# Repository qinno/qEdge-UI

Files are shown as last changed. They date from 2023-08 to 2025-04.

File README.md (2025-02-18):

# qEdge-UI

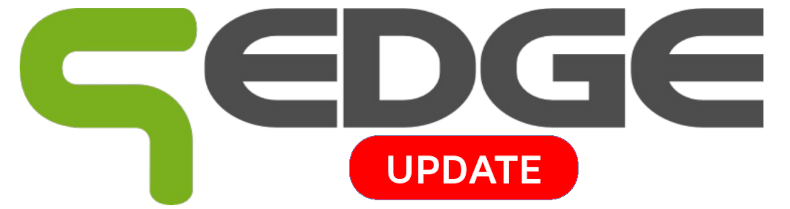
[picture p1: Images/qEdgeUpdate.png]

# Update
qEdge-UI supports now PICO2-W plattform (RP2350) with minimum changes as qEdge-UI++. Compilation now works in the Arduino 2.x.x IDE. LittleFS upload does not work in the moment, copy the files in /data to the SD-card, system copies it automagically to LittleFS on the first start. 

# About

This project is an example of use of what can be achieved with free/libre and open source software and free/libre and open source tools in a professional proceeding. 
In contrast to the generally accepted approach of commercial companies, the development results of this project (hardware and mechanical design, as well as software source code) are also available under an open source licence.

Based on the Raspberry Pi Pico (2), we have created a design that can be used as a starting point for further development. In order to keep things as simple as possible we use the Arduino platform.

Key hardware features of **qEdge-UI (qEdge-UI++)**:

- Raspberry Pi Pico RP2040 (2350)
- Dual-Core ARM Cortex M0+ CPU @133 MHz (ARM Cortex M33 @150 MHz or RISC-V)
- 264KB SRAM and 2MB Flash (520 KB / 4MB)
- WiFi + Bluetooth (Pico-W/Pico2-W)
- USB interface and power supply
- additional 12/24 VDC supply
- 3,2" TFT-Display 320x240 with resistive touch
- 4x1 keypad
- expansion connector for UART, I²C, GPIO, ADC
- RS-485 Interface
- Micro-SD-card slot
- LoRa module with stable SMA connector
- RTC with ultracap buffer
- Buzzer
- RGB-LEDs for signalling
- Raspberry Pi 3b/4b connectable (optional, not tested)

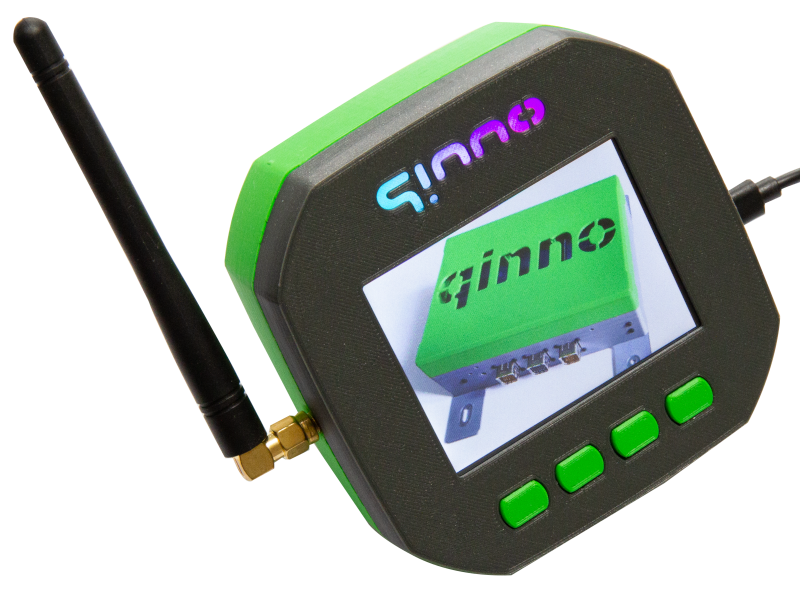
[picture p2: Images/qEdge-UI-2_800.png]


# Getting Started

### Electronics

To get started you will need the qEdge-UI electronic boards (main and display adapter). [We provide the full KiCad project here.](Electronics)

### Software

To get started with the software development you need a PC with:

* preinstalled Windows 7 or newer (64Bit), Linux (32/64Bit) or MacOS 10.10 newer
* An Arduino IDE 1.8.x including USB Driver support
* Addional you can use our qEdge-UI examples and libraries as a starting point for your own software development or you can download the precompiled UFS binaries of our qEdge-UI examples. [Here](Software) you can find the sources and installation guideline.

### Mechanics

To create the nice looking electronic box above you need a 3D printer [and the mechanics](Mechanics)

## qEdge-UI Hardware Test App functionality

The main objective of the qEdge-UI HwTestApp software is to check the functionality of the hardware.

* Touch - check precision of touch screen
* Slideshow - show PNG files on SD-Card (micro)
* UART - Test UART1 (RX/TX)
* RS-485 - Test UART2 connected to RS-485 driver (RX/TX)
* Micro-SD-card - check SD-card presence and list files on SD-card
* LittleFS - list, copy, rename and delete files in the filesystem
* LoRa - send/receive LoRa messages
* WiFi - scan and log in a network for receiving NTP time information
* GAME - space shooters clone to show performance
* Info - show system infos
* Keyboard - keyboard emulation
* Settings - set RGB preferences and backlight, test Buzzer

# Roadmap

See the [open issues](https://github.com/qinno/qEdge-UI/issues) for a list of proposed features (and known issues).

# Contributing

First of all, thank you for taking the time to contribute! Contributions are what make the open source community such an amazing place to learn, inspire and create. Every contribution you make benefits everyone else and is **greatly appreciated**.

Please try to create bug reports that are:

- _Reproducible._ Include steps to reproduce the problem.
- _Specific._ Include as much detail as possible: which version, what environment, etc.
- _Unique._ Do not duplicate existing open issues.
- _Scoped to a Single Bug._ One bug per report.

# Use and Regulations

Please note that this is an engineering example and is not certified to European regulations such as CE and RED, so use it at your own risk. If you find this platform helpful, we can assist you in creating a production-ready and certified product.

# Known limitations

This project is at the moment not used in a commercial open source product, but can be used as a starting point for that purpose. Please fell free to contact us for more information.

# Support

Reach out to the maintainer at one of the following places:

- By email which is located at [qinno GmbH · GitHub](https://github.com/qinno)

# Licenses

This project is licensed under the following open source licenses:
* Electronics are under [**CERN-OHL-S V2**](https://ohwr.org/cern_ohl_s_v2.txt)
* Mechanics and Design are under [**CC-BY-NC-4.0**](https://creativecommons.org/licenses/by-nc/4.0/legalcode)
* Software Examples are under [**GPLv3**](https://www.gnu.org/licenses/gpl-3.0.en.html)
   
See corresponding Readme.md files in the folders Electronics, Mechanics and Software for more detailed information.

[Raspberry Pi is a trademark of Raspberry Pi Ltd](http://www.raspberrypi.com/)

# Acknowledgements

Thanks to our partners supporting this project:

* [Our Customer Varmeco for the generous donation of material](https://varmeco.de)

* Axel Isele for the mechanics design

* [Würth Elektronik for free samples for the very first prototypes](https://www.we-online.com/de)

* All qinno-colleagues for their commitment even in their spare time

Thanks also for these awesome resources that were used during the development of the **qEdge-UI**:

* [The KiCAD team for their great CAE tool](https://www.kicad.org/)
* [Earle F. Philhower, III for his Arduino library for the RP2040](https://github.com/earlephilhower/arduino-pico)
* [Bodmer for his versatile TFT-Library](https://github.com/Bodmer/TFT_eSPI)
* [Larry Bank for his PNG extension](https://github.com/bitbank2/PNGdec)
* [The Adafruit Industries Team for their RGB-LED library](https://github.com/adafruit/Adafruit_NeoPixel)
* [The Arduino team for their easy to use (now legacy) IDE](https://www.arduino.cc/en/software)
* [Sandeep Mistry for his handy LoRa library](https://github.com/sandeepmistry/arduino-LoRa)

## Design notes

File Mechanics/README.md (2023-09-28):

# qEdge-UI mechanics

In this directory you will find the mechanic data to 3D-Print a housing and keys for qEdge-UI. You will find an exploded view under [Assembling](QE.ASM-102_01.pdf).

There are 4 different parts that need to be printed.

# Top housing

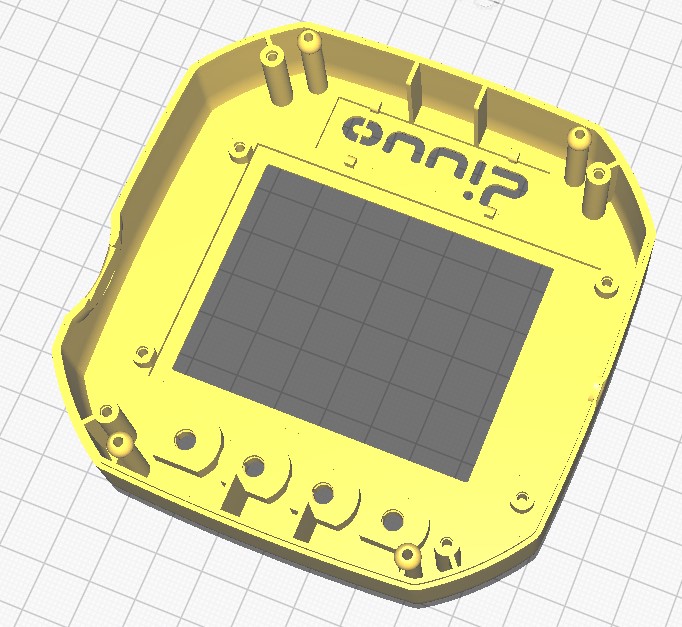
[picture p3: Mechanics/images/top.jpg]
Top


# Bottom Housing

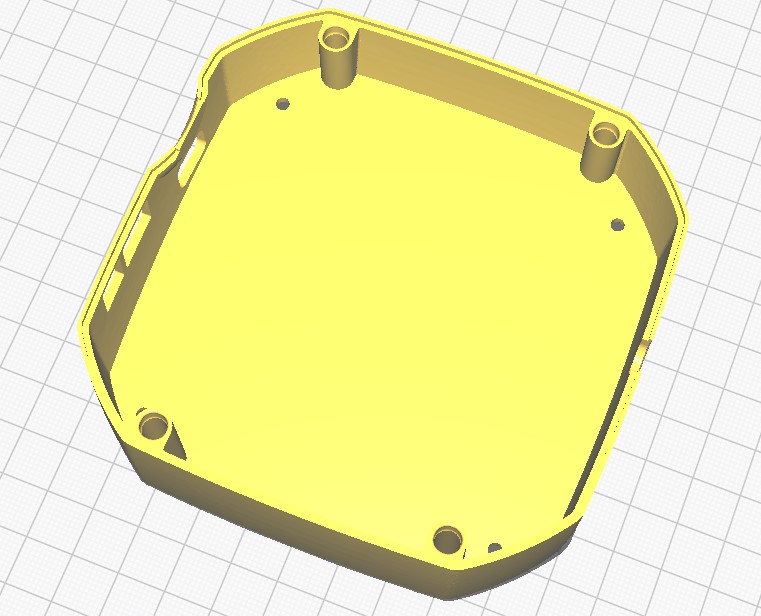
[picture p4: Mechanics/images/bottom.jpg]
Bottom


# Buttons (4x needed)

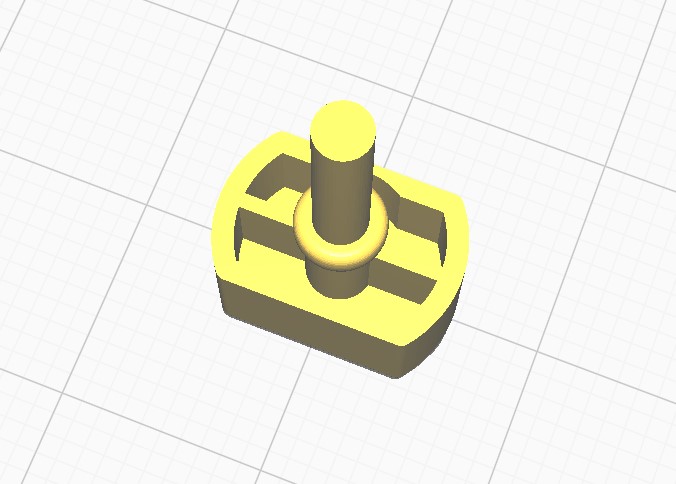
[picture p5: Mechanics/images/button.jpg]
Buttons


# LED Window

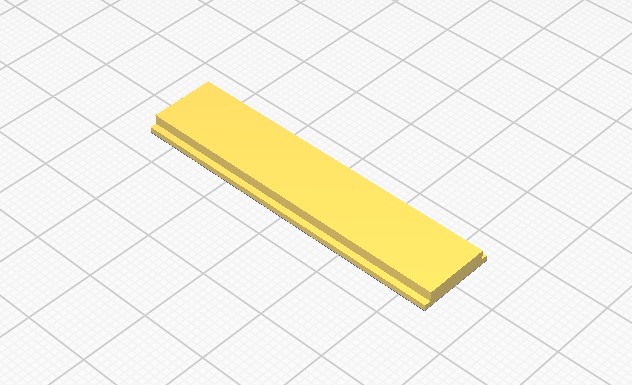
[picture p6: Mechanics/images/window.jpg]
Window


You can choose any filamant type and color. However, the GCODE is designed for PLA filament. Use something translucent for the window.

# Tips for printing

Notes on the printability of the qEdge housing, you will find the data

in [STL](./stl) for free printing in all slicers
in [3MF](./3mf) with our presets for easy adjustments
in [GCODE](./gcode) for use with a Prusa MK3S+

Please check the compatibility of the data with your printer. We cannot accept any liability for damage. The files are created with Prusa-SLICER 2.6.0.

## Bottom Housing

- The bottom should be placed flat on the print bed.
- Organic support structures / treesupports are recommended for the fillets.

## Top Housing

- The Top Housing should be placed with the top side facing the print bed. 
  
  - The Button holes also require support structures.
  
  - We do not recommend the use of treesupports here, as they are difficult to remove.  Easy to remove here was the snug option in Prusaslicer.
  
  - Before printing the upper part, we recommend printing our Support-Test STL files.  You can check the type of support structures you have and the position of the buttons without having to print the entire housing.

## Buttons

For printing, it is recommended to print at least 4 buttons at the same time to ensure sufficient cooling of the printed parts.

# License

This work is licensed under the Creative Commons Attribution-NonCommercial 4.0 International License. To view a copy of this license, visit http://creativecommons.org/licenses/by-nc/4.0/ or send a letter to Creative Commons, PO Box 1866, Mountain View, CA 94042, USA.

## Additional Printig Files (tests pending)

Since there is already print data for a Prusa printer, I wanted to extend the data for the BambuLab printer I use. Here are only [3MF](./3mf) data available, because BambuLab devices do not need the manual intermediate step to .gcode and can print directly from this file.

Important: 
1. These data are intended in the Bambu Studio Slicer or the Orca Slicer. To my knowledge, other software does not support the multi-plate layouts.

2. Bed 04 is preconfigured for a test of the support structures, the two cutouts use different types of 'normal' supports to test their removal after printing.

#### P1-X1
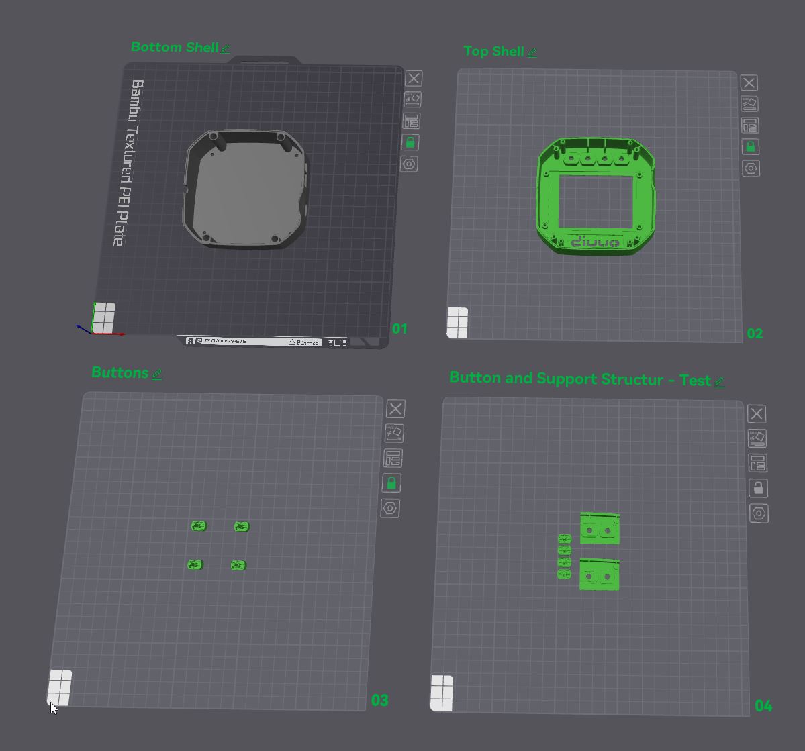
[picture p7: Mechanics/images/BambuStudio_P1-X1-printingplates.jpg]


#### A1
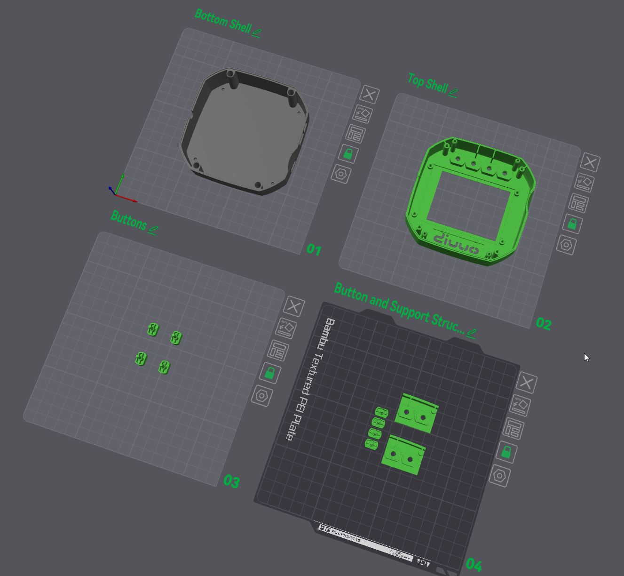
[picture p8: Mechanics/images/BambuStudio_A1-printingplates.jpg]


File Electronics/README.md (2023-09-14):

# qEdge-UI electronics

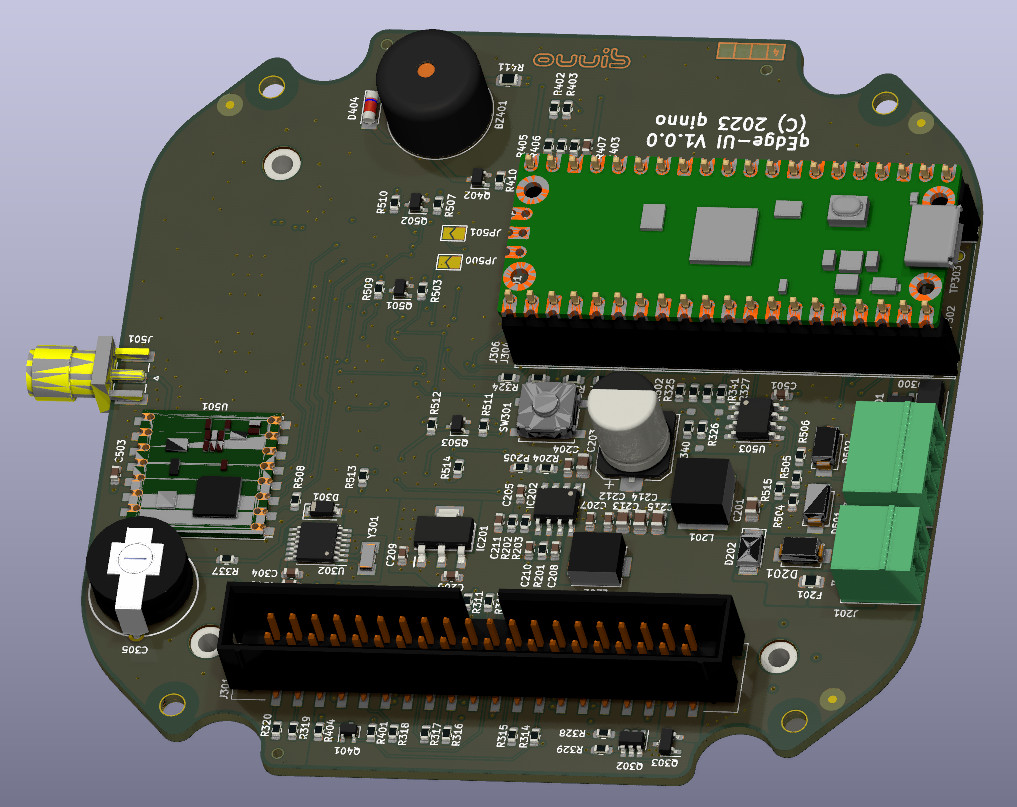
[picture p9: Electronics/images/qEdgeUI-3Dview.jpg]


In this directory you will find the complete electronic design in KiCAD.

### The main electronics

[in the directory qedge-UI](qEdge-UI)

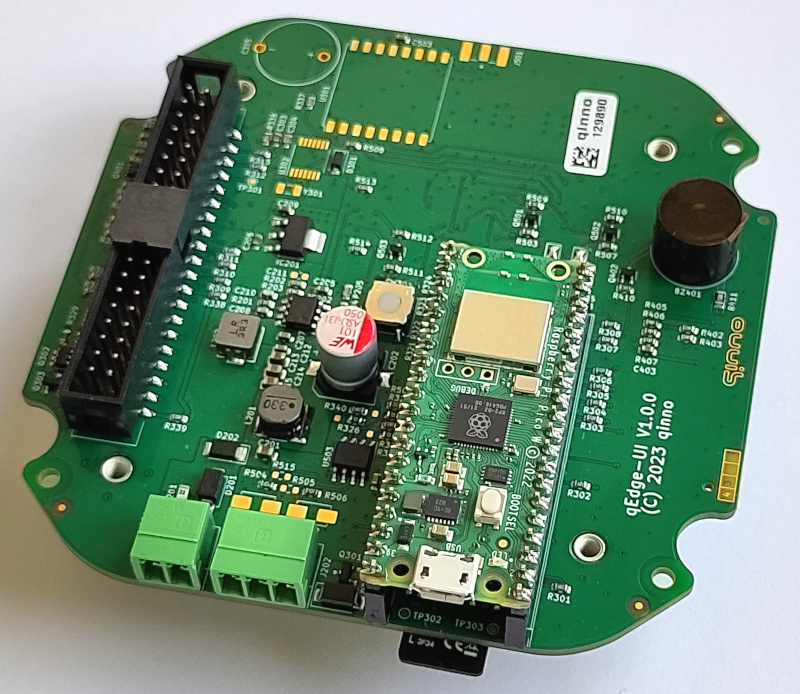
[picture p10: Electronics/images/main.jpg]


### The display adapter board

 [in the directory qEdge-LCD-Adapter](qEdge-LCD-Adapter)

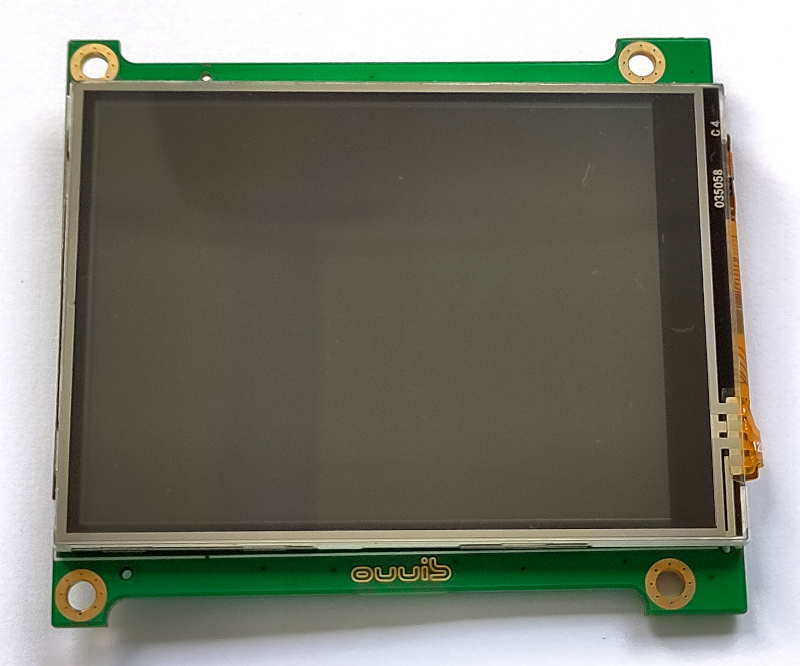
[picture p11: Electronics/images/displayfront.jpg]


You need to glue the display to the adapter board with double-sided adhesive tape and connect it to the ZIF-connector.

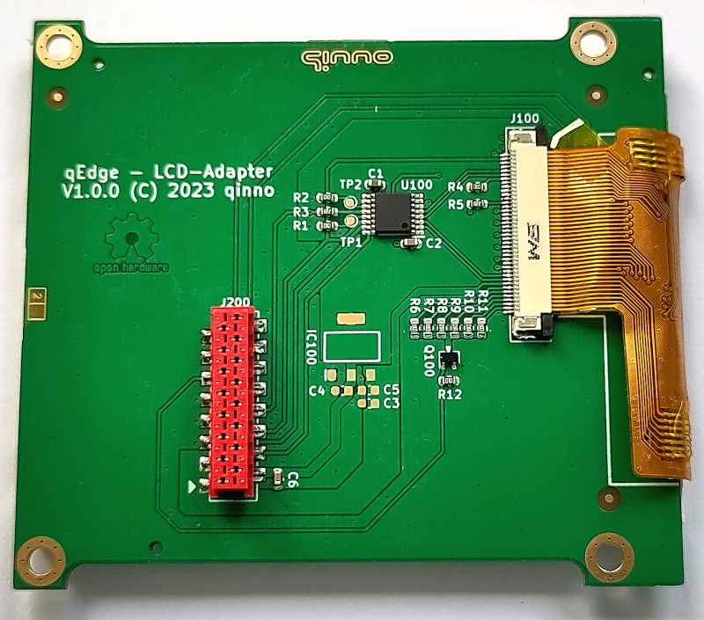
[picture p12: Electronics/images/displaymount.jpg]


For use with RaspBerry Pi Pico or Pico-W you need to close the Jumpers JP500 and JP501. After you have assembled both boards, you need to connect them with a ribbon cable.

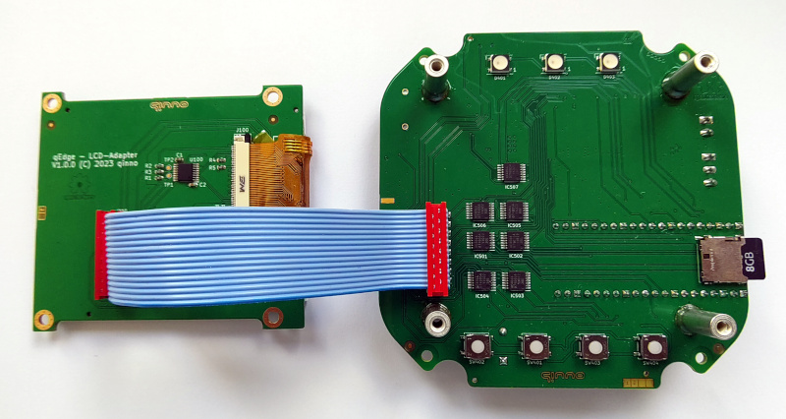
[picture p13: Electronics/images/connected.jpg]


Now screw the LCD display on top of the main board.

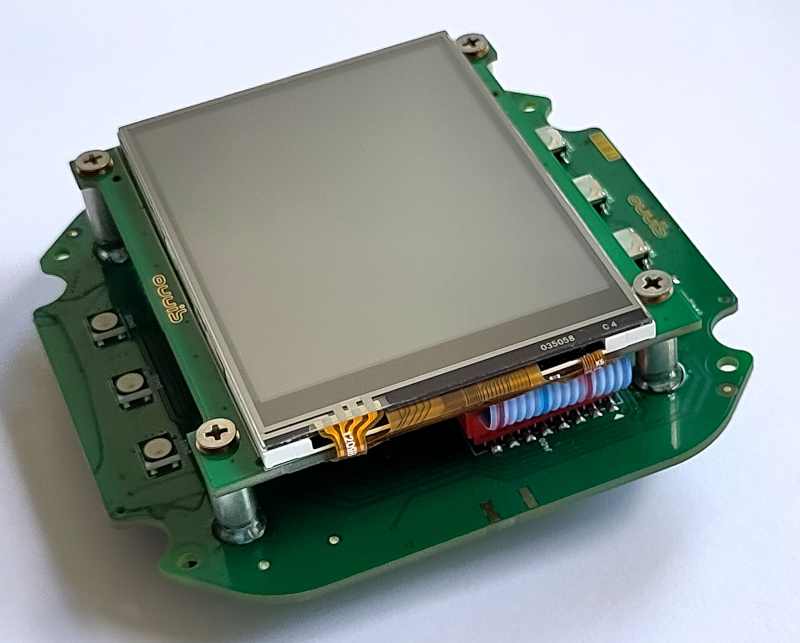
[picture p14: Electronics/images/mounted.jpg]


You can supply the unit via Micro-USB (5V) and/or via the Phoenix connectors with 12V/24V (mating connector Phoenix 1952267).

The RS-485 connector needs Phoenix mating connector 1952270 to fit.

Fingers crossed ...

# License

(C) 2023 qinno - this work is licensed under CERN-OHL-S
see https://ohwr.org/cern_ohl_s_v2.pdf for more information

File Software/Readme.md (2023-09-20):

# qEdge-UI software

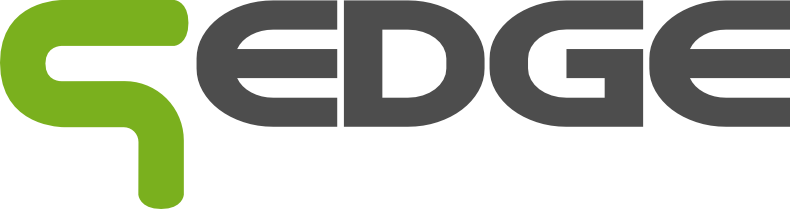
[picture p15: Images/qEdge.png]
qEdge-UI Logo

---

# Getting Started

To get started with the software development you need a PC with:

## SW-Environment Prerequisites

### OS
* Windows 7 or newer (64Bit) or
* Linux (32/64Bit) or 
* MacOS 10.10 or newer

### IDE
* An Arduino IDE 1.8.x including USB Driver support (tested with 1.8.19 - 541MB) [download here](https://www.arduino.cc/en/software). Arduino IDE 2.x is not recommended, because it has no support for Littlefs (extension), Compilation with IDE 2.x should work)

### Board package
* The Raspberry Pi Pico / RP2040 Board package by Earle F. Philhower, III. Please follow the [installation guide](https://github.com/earlephilhower/arduino-pico#installation) on Github from Earle F. Philhower, III in the arduino-pico repository. Only the installtion steps under the section "Installation" are needed.
  
### Libraries
Install the following libraries, from the Arduino IDE, by selecting the "Sketch" menu and then selecting "Include Library" and then clicking on "Manage Libraries":

* TFT_eSPI (by Bodmer - version 2.5.0)
* TFT_eWidget (by Bodmer - version 0.0.5)
* PNGdec (by Larry Bank - version 1.0.1)
* Adafruit_NeoPixel (by Adafruit - version 1.11.0)
* LoRa (by Sandeep Mistry - version 0.8.0)

#### Configure LoRA libary
* Open with an editor the file LoRa.h in Arduino/libraries/LoRa/src/
* Change in Line 23 from:

```
#define LORA_DEFAULT_SPI           SPI
```

to:

```
#define LORA_DEFAULT_SPI           SPI1
```

## Installing qEdge-UI HwTestApp

### Clone the qEdge-UI repository locally into the Arduino sources folder
* Located in the default installation path for Windows:
```
cd C:\Users\{username}\Documents\Arduino
```
  
* Located in the default installation path for Linux:
```  
cd /home/{username}/Arduino
```

* clone the repo
```
git clone https://github.com/qinno/qEdge-UI
```

### Copy & Configure the qEdge-UI HwTestApp

* Copy the file **User_Setup.h** of the repository folder Software\libaries\TFT_eSPI\ to overwrite the file with the same name in:
  
  Windows: `C:\Users\{username}\Documents\Arduino\libraries\TFT_eSPI`
  
  Linux: `/home/{username}/Arduino\libraries\TFT_eSPI`

### Download & Integrate LittleFS plugin

* Download from Github the latest ZIP archive of the LittleFS plugin (e.g. PicoLittleFS-0.2.0.zip) [Release folder of the repository of arduino-pico-littlefs-plugin from Earle F. Philhower, III](https://github.com/earlephilhower/arduino-pico-littlefs-plugin/releases). 

* Create a folder tools if it not already exists:
  
  Windows: `C:\Users\{username}\Documents\Arduino\tools`
  
  Linux: `/home/{username}/Arduino/tools`

* Unzip the LittleFS plugin archiv into the folder tools 

* Close the Ardunio IDE

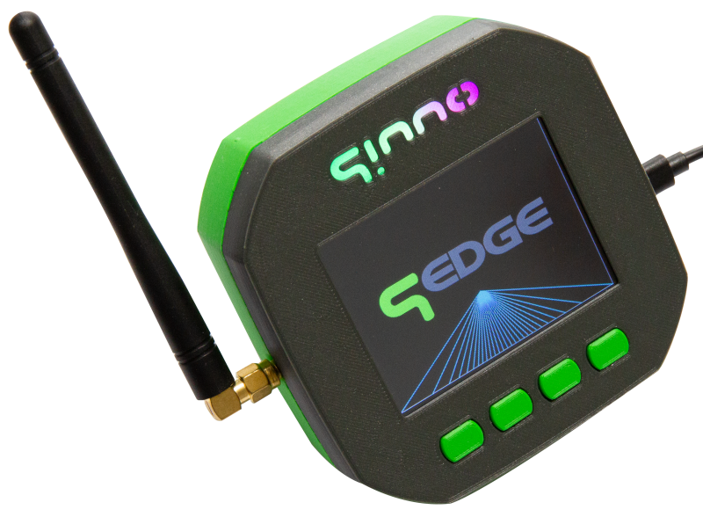
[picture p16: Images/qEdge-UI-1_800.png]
qEdge-UI with HwTestApp


## Running HwTestApp on qEdge-UI

### Initial setup Arduino IDE

* Start the Arduino IDE and select: Tools -> Board ->Raspberry Pi RP2040 Boards(3.3.0) -> **Raspberry Pi Pico W**
* Set LittleFS size by Tools -> Flash Size -> **2MB (Sketch: 1536KB, FS: 512KB**
* Connect your qEdgeUI with an USB cable 
* Select the corresponding COM Port X for the USB communication by Tools -> Port -> COM X (Raspberry Pi Pico W)

### Loading HwTestApp sketch into the IDE and compile

* In the Arduino IDE load the sketch **HwTestApp** by File -> Open -> and selecting in the qEdgeUI-demo folder the arduino file qEdgeUI-demo.ino
* Compile the sketch by selecting: Sketch -> Compile

### Upload sketch & LittleFS files to target

* Upload the sketch by selecting: Sketch -> Upload 
* Upload LittleFS files by selecting: Tools -> Pico LittleFS Data Upload (located in HwTestApp/data)

### Calibration of the qEdge-UI

The first time when the qEdge-UI unit is used after upload, it starts with a touch calibration screen. Please follow the instructions on the touchscreen. After calibration press the save button on the touchscreen and wait up to 5 seconds (if micro sd memory card is not accessible).

If you wish to re-calibrate, power down the system (unplug the USB cable) and press any front panel key on the qEdgeUI for up to 5 seconds while power is applied.

## Behind the scenes

PNG files on Micro-SD-card or LittleFS needs to be 320x240 (4:3) to fill the whole screen. Use ImageMagick to convert existing files.

# Roadmap

See the [open issues](https://github.com/dec0dOS/amazing-github-template/issues) for a list of proposed features (and known issues).

# Contributing

First of all, thank you for taking the time to contribute! Contributions are what make the open source community such an amazing place to learn, inspire and create. Every contribution you make benefits everyone else and is **greatly appreciated**.

Please try to create bug reports that are:

- _Reproducible._ Include steps to reproduce the problem.
- _Specific._ Include as much detail as possible: which version, what environment, etc.
- _Unique._ Do not duplicate existing opened issues.
- _Scoped to a Single Bug._ One bug per report.

# Known limitations

* Main menu starts slowly if compiled with SD option and no Micro-SD-card inserted

* RTC not yet supported in software

# Support

Reach out to the maintainer at one of the following places:

- By email which is located at [qinno GmbH · GitHub](https://github.com/qinno)

# License
The files in these folders are licensed under the following open source licenses:
* [examples/](examples/) -> [**GPLv3**](https://www.gnu.org/licenses/gpl-3.0.en.html)
* PNG Images in folder data and SDcontent [examples/HwTestApp/](examples/HwTestApp/) -> [**CC-BY-NC-4.0**](https://creativecommons.org/licenses/by-nc/4.0/legalcode)
* [libraries/TFT_eSPI](libraries/TFT_eSPI) -> [**MIT, BSD, FreeBSD**](libraries/TFT_eSPI/license.txt)

For detailed information please have a look at the licence files in the corresponding folders and file header in each corresponding file.

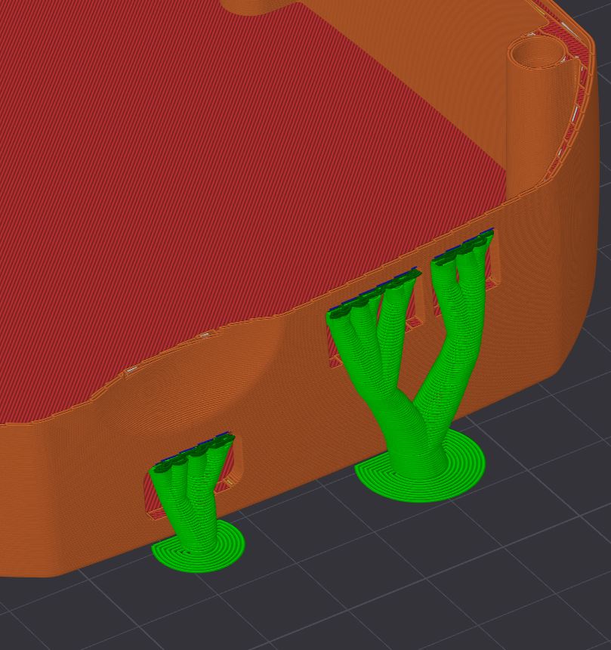
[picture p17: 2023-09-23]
Mechanics/images/bottom_support example.jpg

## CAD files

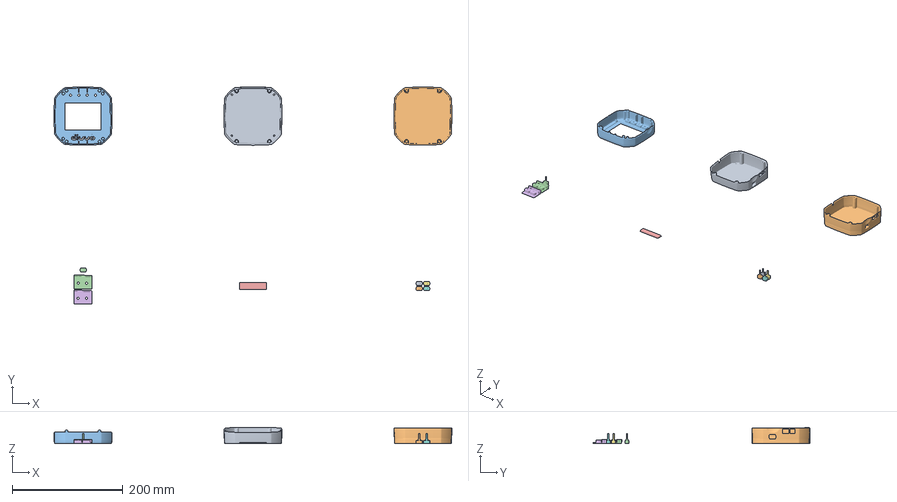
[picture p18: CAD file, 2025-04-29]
Mechanics/3mf/qEdge.104 Babu Studio 2.0+.3mf
719.4 x 392.6 x 29.6 mm
qEdge-bottom.104.stl
qEdge-bottom.104_flat.stl
qEdge-top.104.stl
Support-Test-button.104.stl
qEdge-window.104.stl
Support-Test-top-104.stl
qEdge-button.104.stl.stl x 4

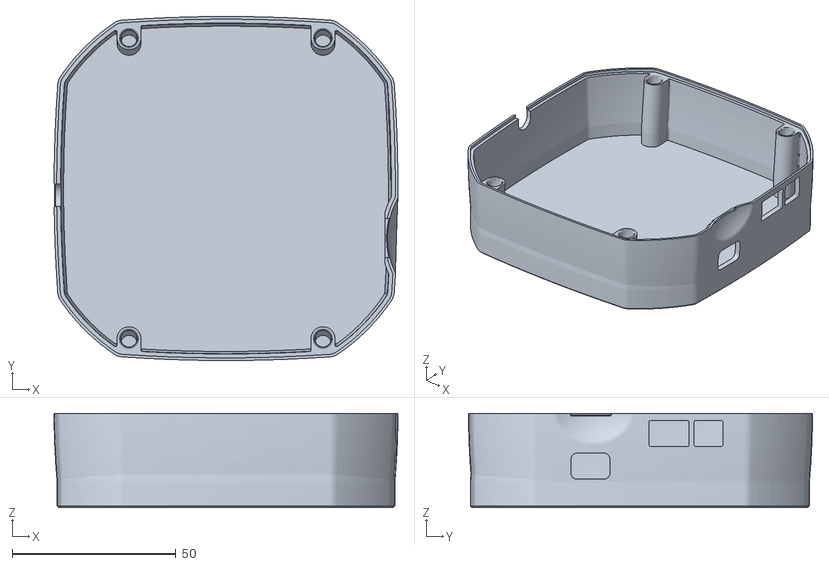
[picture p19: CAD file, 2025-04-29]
Mechanics/stl/104/qEdge-bottom.104_flat.stl
105.0 x 105.0 x 28.7

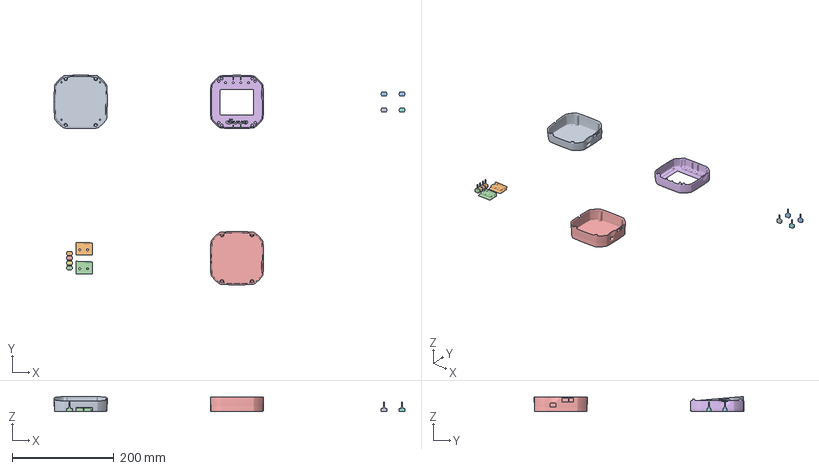
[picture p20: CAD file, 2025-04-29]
Mechanics/3mf/qEdge.104_BambuStudio-Slicer_P1-X1_3 plate project file.3mf
690.0 x 412.4 x 29.6 mm
qEdge-bottom.104.stl
Support-Test-top-104.stl x 2
qEdge-button.104.stl.stl x 8
qEdge-top.104.stl
qEdge-bottom.104_flat.stl

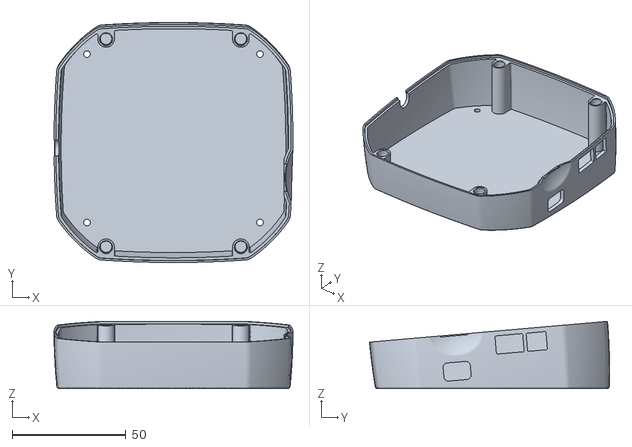
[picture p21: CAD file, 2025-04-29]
Mechanics/stl/104/qEdge-bottom.104.stl
105.0 x 105.5 x 29.6

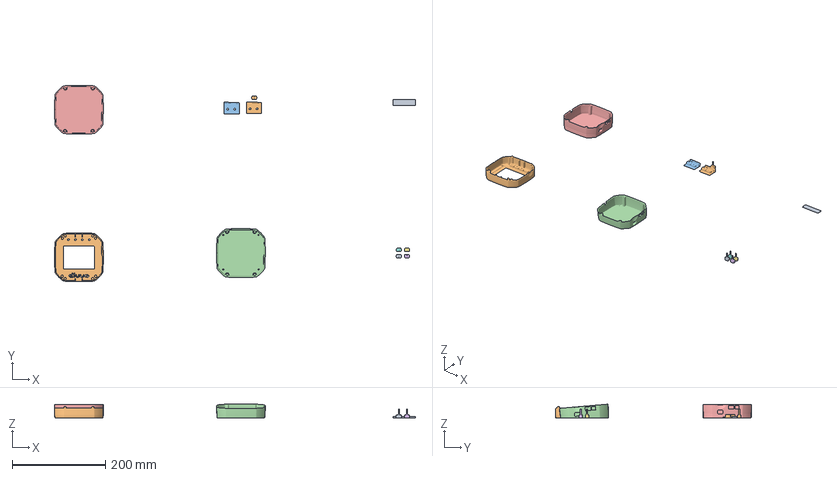
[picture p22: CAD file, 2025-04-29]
Mechanics/3mf/qEdge.104_Prusa-Slicer_plate project file.3mf
775.4 x 422.0 x 29.6 mm
qEdge-window.104.stl
Support-Test-button.104.stl
Support-Test-top-104.stl
qEdge-bottom.104.stl
qEdge-bottom.104_flat.stl
qEdge-button.104.stl.stl
qEdge-top.104.stl

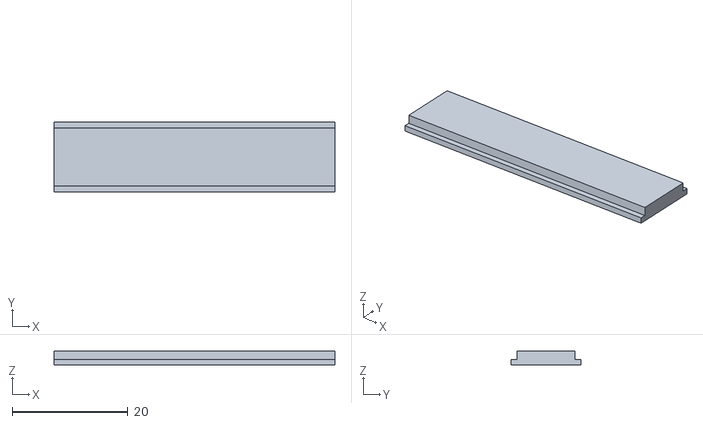
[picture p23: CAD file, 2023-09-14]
Mechanics/stl/104/qEdge-window.104.stl
48.6 x 12.1 x 2.50

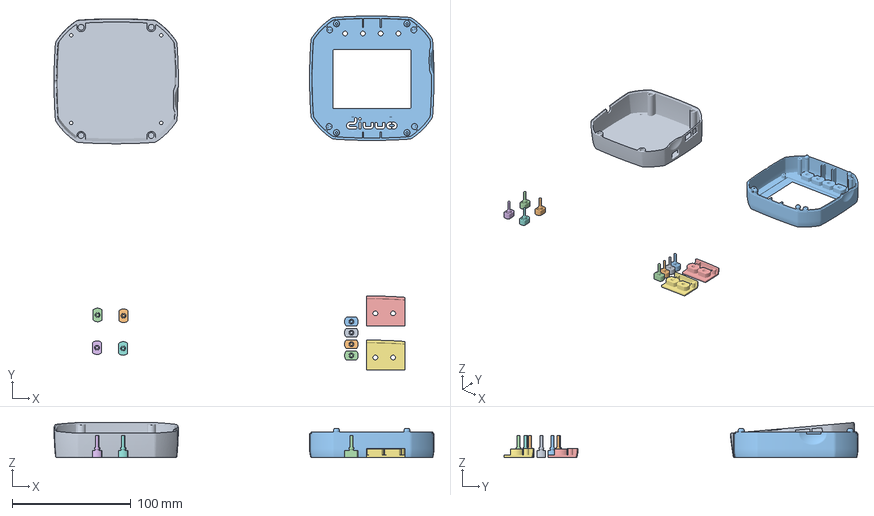
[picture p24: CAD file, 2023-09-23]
Mechanics/3mf/qEdge.104_BambuStudio-Slicer_A1_4 plates project.3mf
320.7 x 298.7 x 29.6 mm
qEdge-bottom.104.stl
qEdge-button.104.stl.stl x 8
qEdge-top.104.stl
Support-Test-top-104.stl x 2

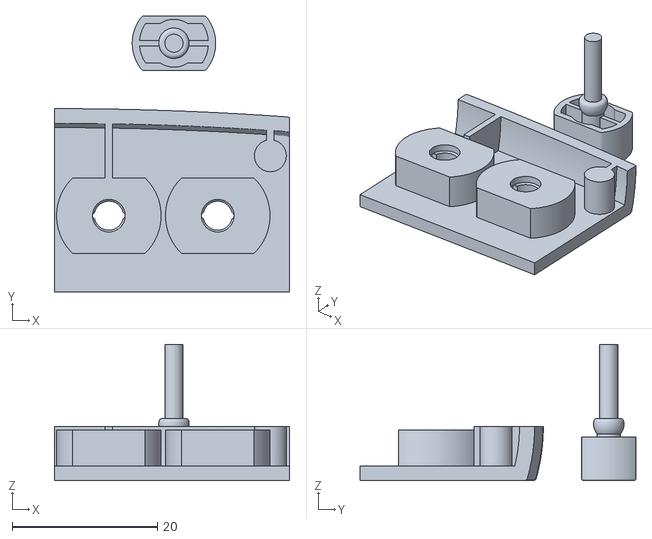
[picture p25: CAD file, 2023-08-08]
Mechanics/stl/104/Support-Test-button.104.stl
32.4 x 38.0 x 18.8

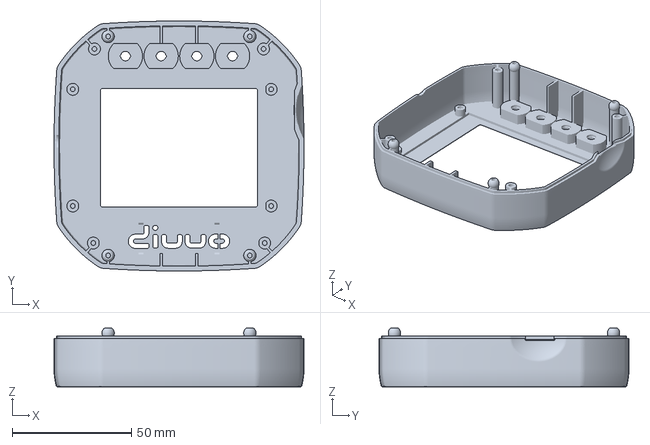
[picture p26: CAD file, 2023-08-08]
Mechanics/3mf/TOP_QE.PT-00_103+_Grau-2.3mf
105.0 x 105.0 x 24.6 mm

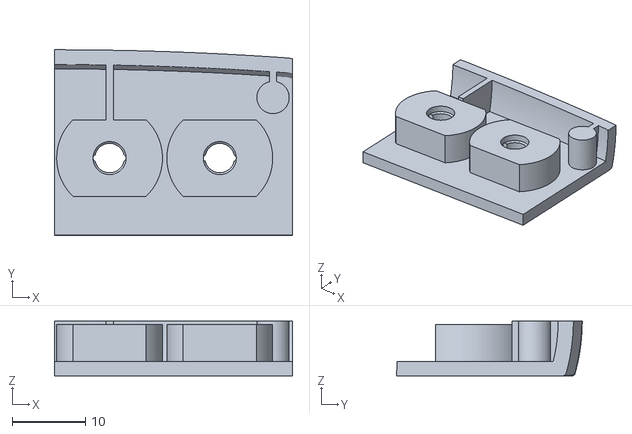
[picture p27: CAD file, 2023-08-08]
Mechanics/stl/104/Support-Test-top-104.stl
32.4 x 25.3 x 7.47

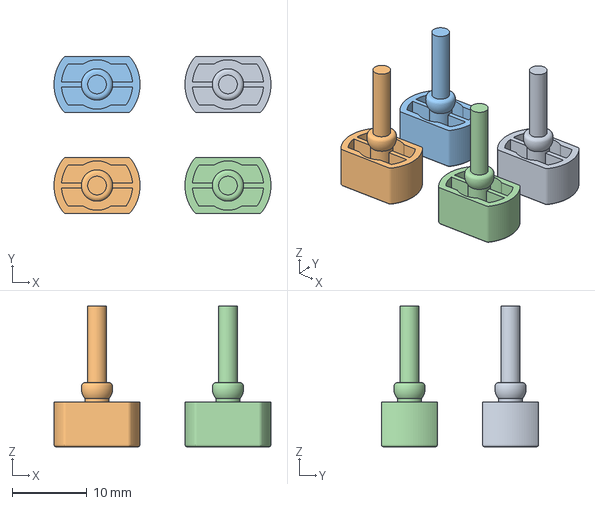
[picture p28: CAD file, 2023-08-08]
Mechanics/3mf/4xBUTTON_QE.PT-03_102_003_1mm.3mf
29.0 x 21.0 x 18.8 mm
Edit LZI_04-07-23_002_1mm x 4

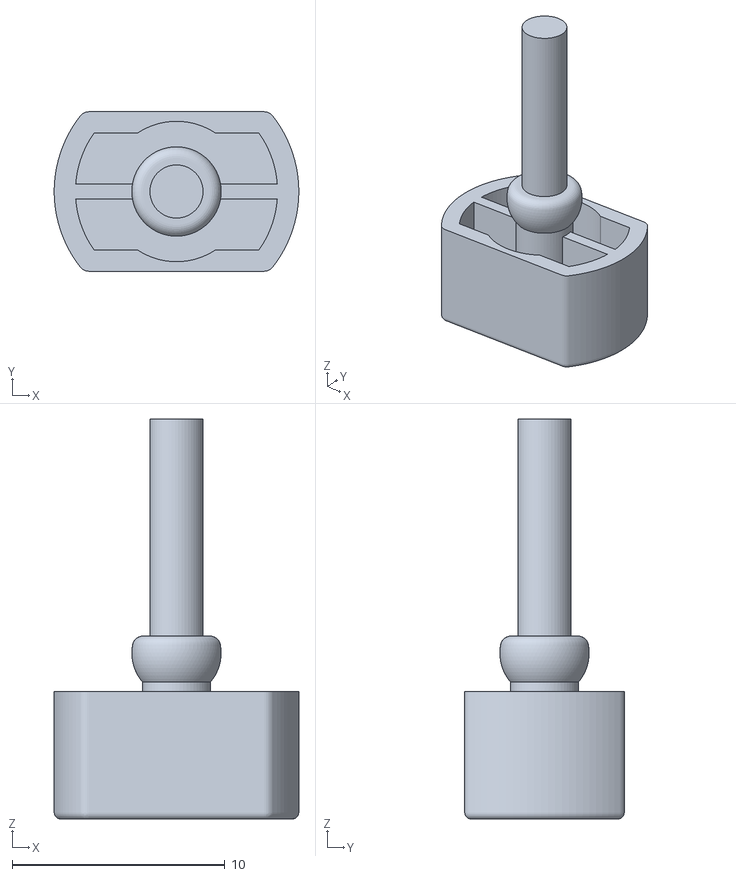
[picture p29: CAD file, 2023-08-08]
Mechanics/stl/104/qEdge-button.104.stl.stl
11.5 x 7.50 x 18.8

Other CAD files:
Mechanics/stl/104/qEdge-top.104.stl
Mechanics/3mf/BOTTOM-QE.PT-02_101.3mf

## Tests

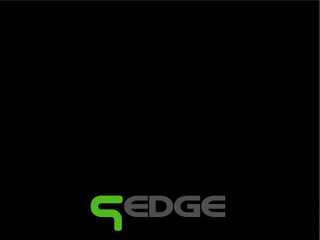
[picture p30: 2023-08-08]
Software/examples/HwTestApp/SDcontent/idle.png

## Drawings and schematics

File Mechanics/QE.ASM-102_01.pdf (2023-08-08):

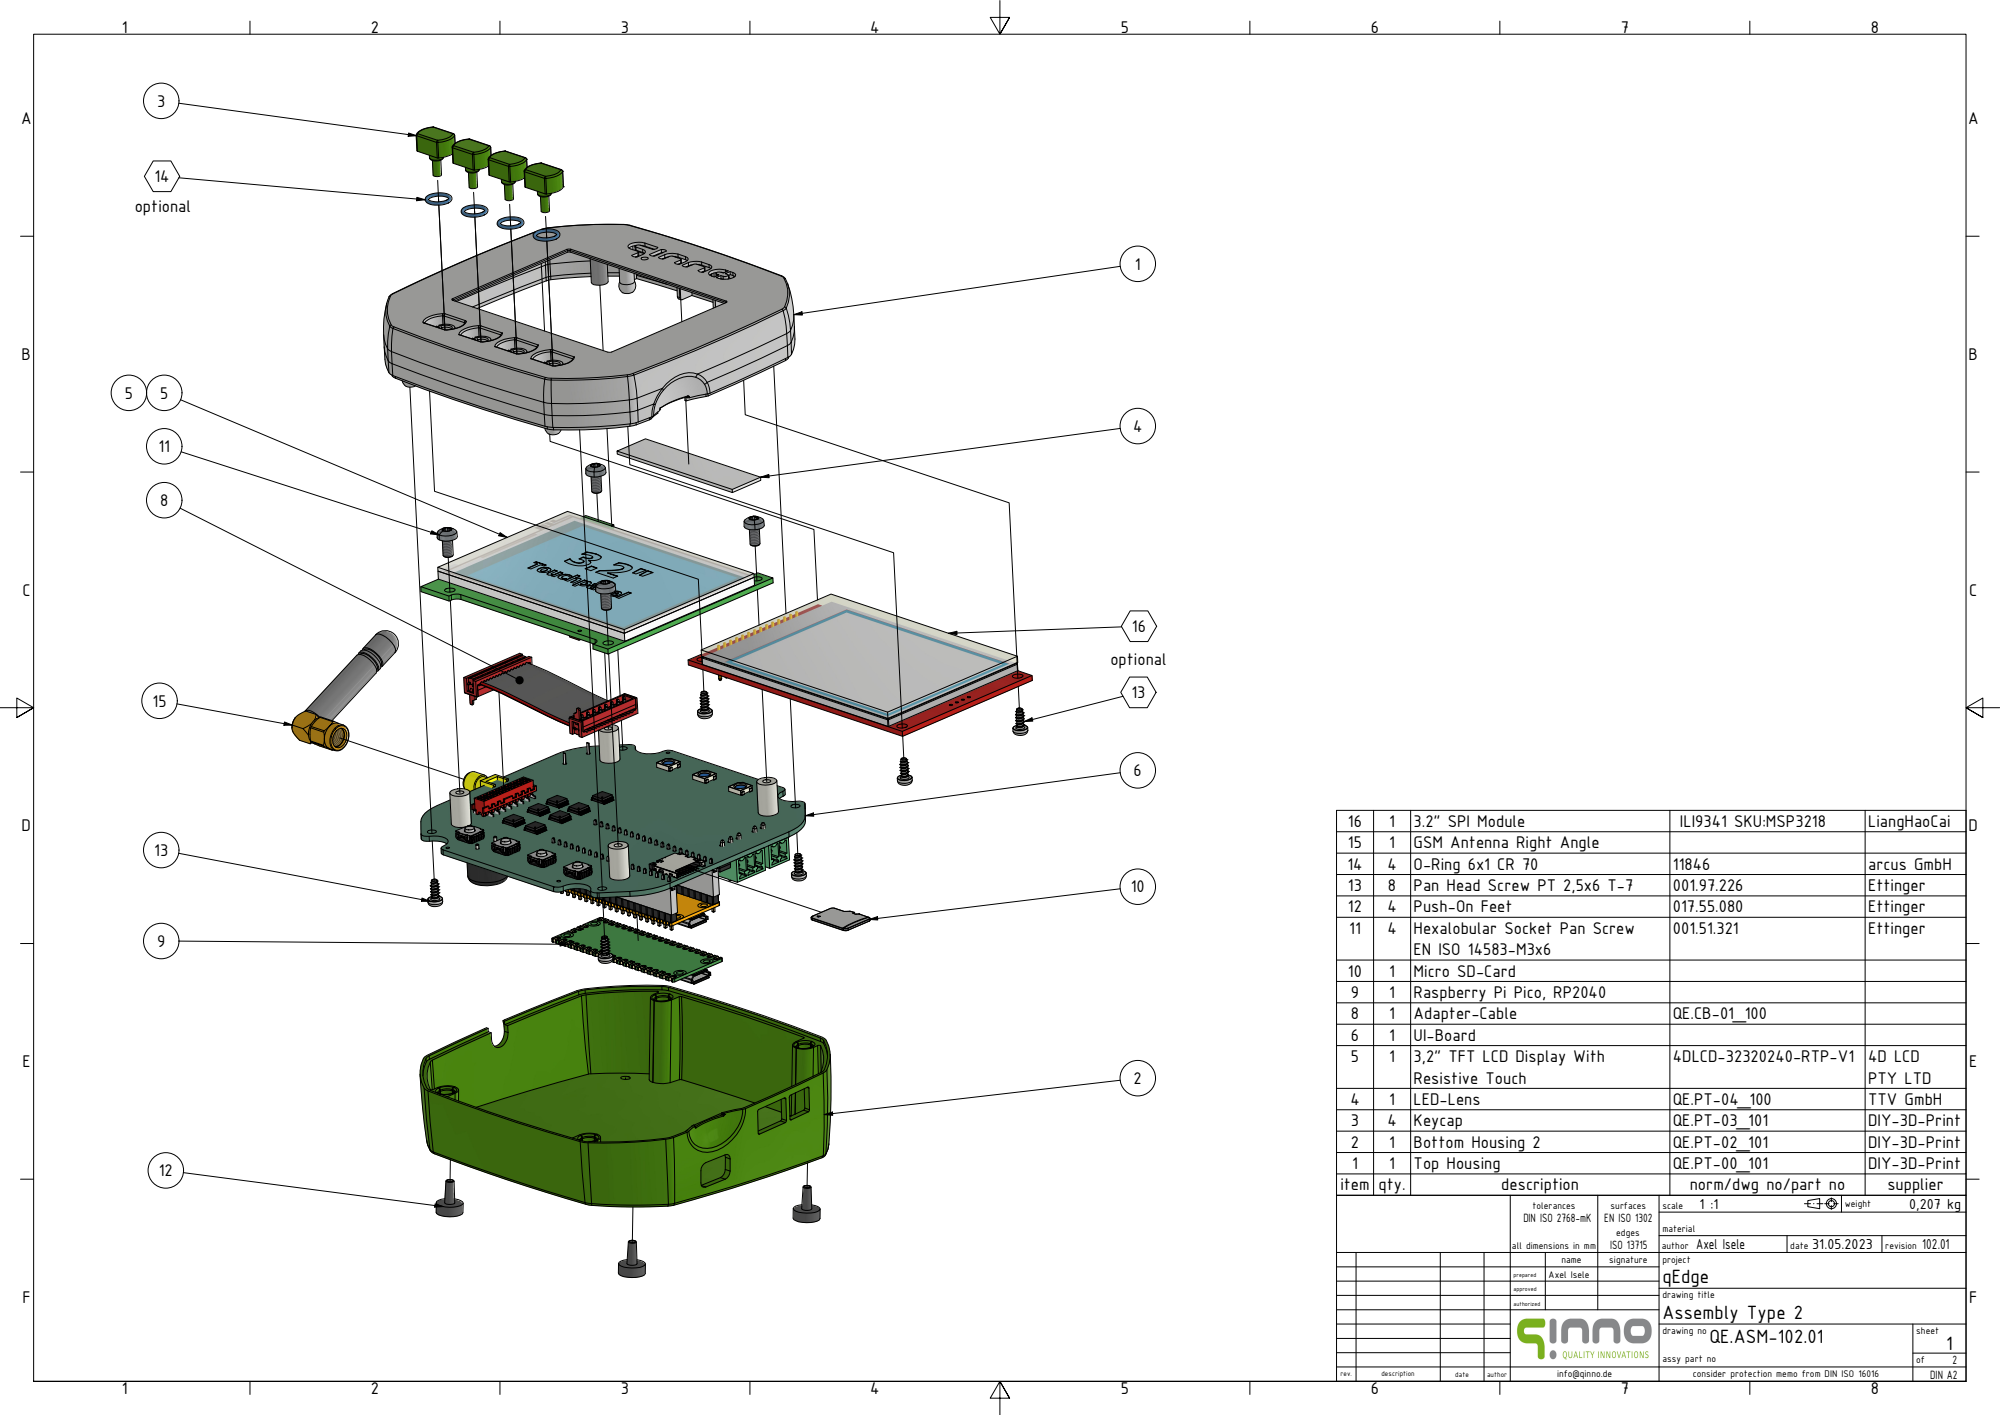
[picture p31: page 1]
GSM Antenna Right Angle 14; 4 O-Ring 6x1 CR 70; arcus GmbH 13; 8 Pan Head Screw PT 2,5x6 T-7; Ettinger 12; 4 Push-On Feet; Ettinger Hexalobular Socket Pan Screw; Ettinger EN ISO 14583-M3x6 11; Micro SD-Card 9; Raspberry Pi Pico, RP2040 8; Adapter-Cable; UI-Board; 4D LCD PTY LTD 3,2" TFT LCD Display With; 4DLCD-32320240-RTP-V1 Resistive Touch 5; LED-Lens; TTV GmbH 3; 4 Keycap; DIY-3D-Prin; t item qty.; description; norm/dwg no/part no; supplier; l info@qinno.de; project drawing; N IS s ISO 137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

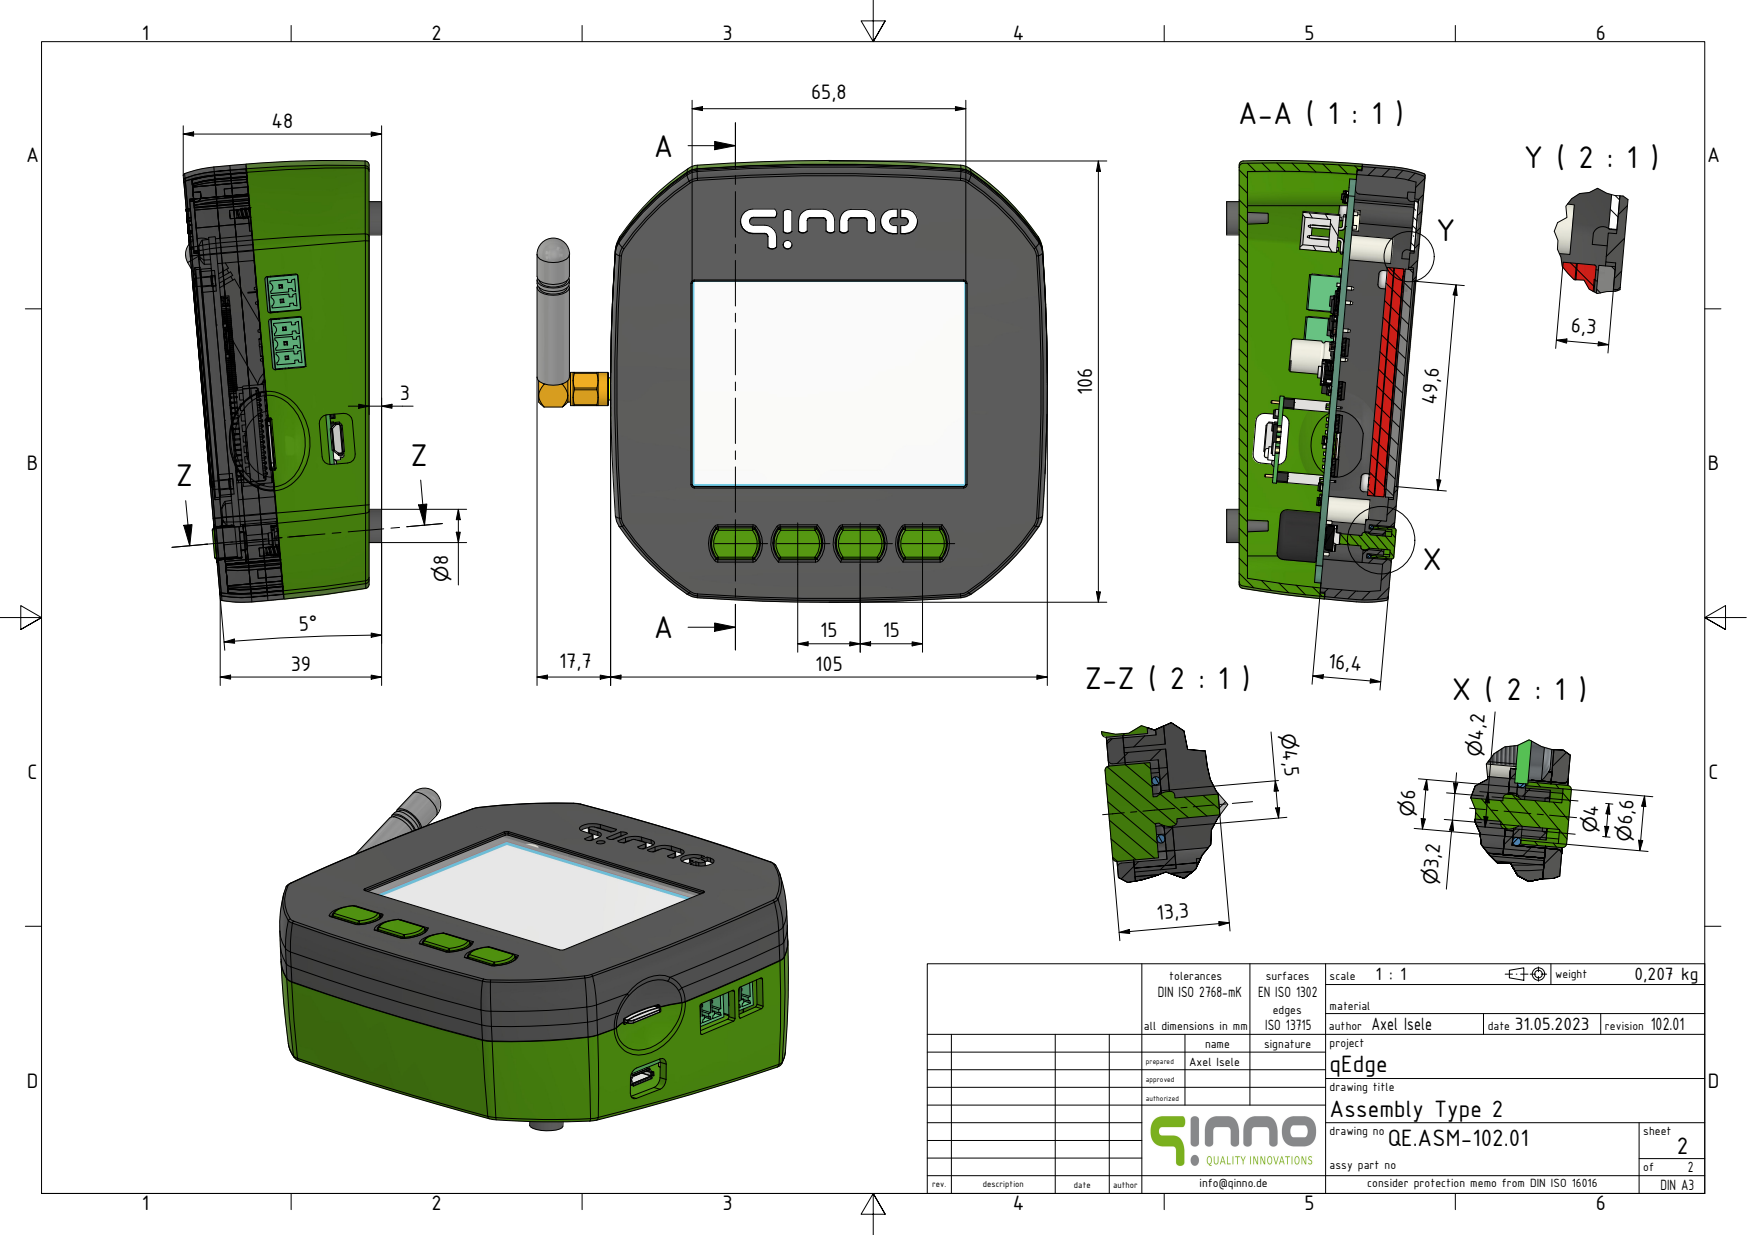
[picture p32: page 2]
N IS s ISO 137; DIN IS

p r e p a r e d | A x e l Is e l e | | l info@qinno.de

n a m e | sig n a t u r e | project drawing q E d g e

A x e l Is e l e a u t h o r | 3 1.0 5.2 0 2 3 d a t e | 1 0 2.0 1 r e visio n

a u t h o riz e d

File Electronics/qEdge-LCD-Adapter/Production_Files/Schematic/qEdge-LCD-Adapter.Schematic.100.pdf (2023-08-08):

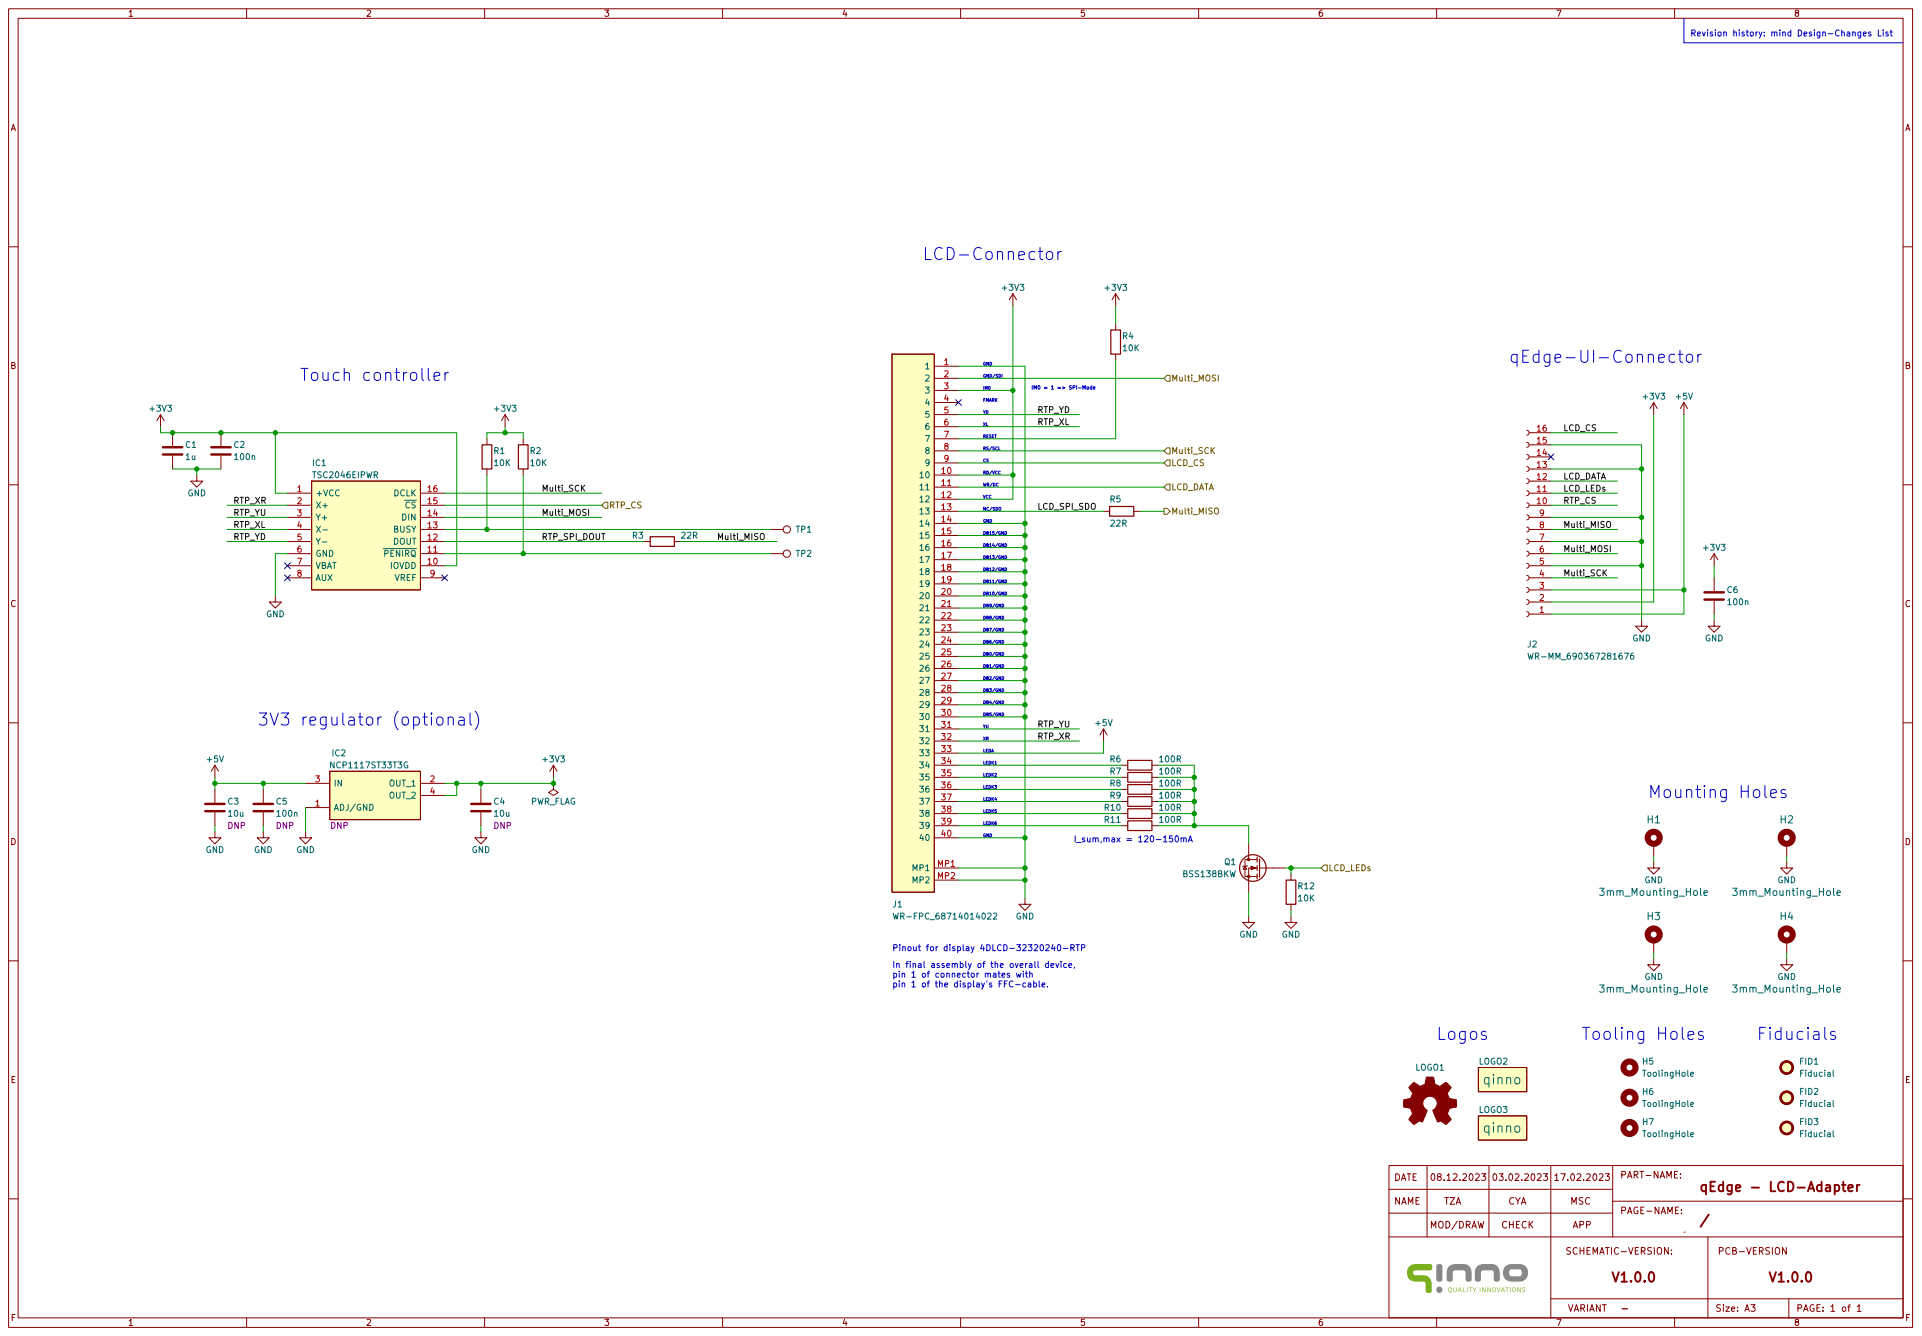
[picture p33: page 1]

Revision history: mind Design-Changes List

XLRESET GND LCD-Connector
IM0 = 1 => SPI-Mode Pinout for display 4DLCD-32320240-RTP

RD/VCC WR/DC

LEDK3 In final assembly of the overall device,

pin 1 of connector mates with
pin 1 of the display's FFC-cable.

SCHEMATIC-VERSION: | Size: A3 PCB-VERSION

VARIANT -

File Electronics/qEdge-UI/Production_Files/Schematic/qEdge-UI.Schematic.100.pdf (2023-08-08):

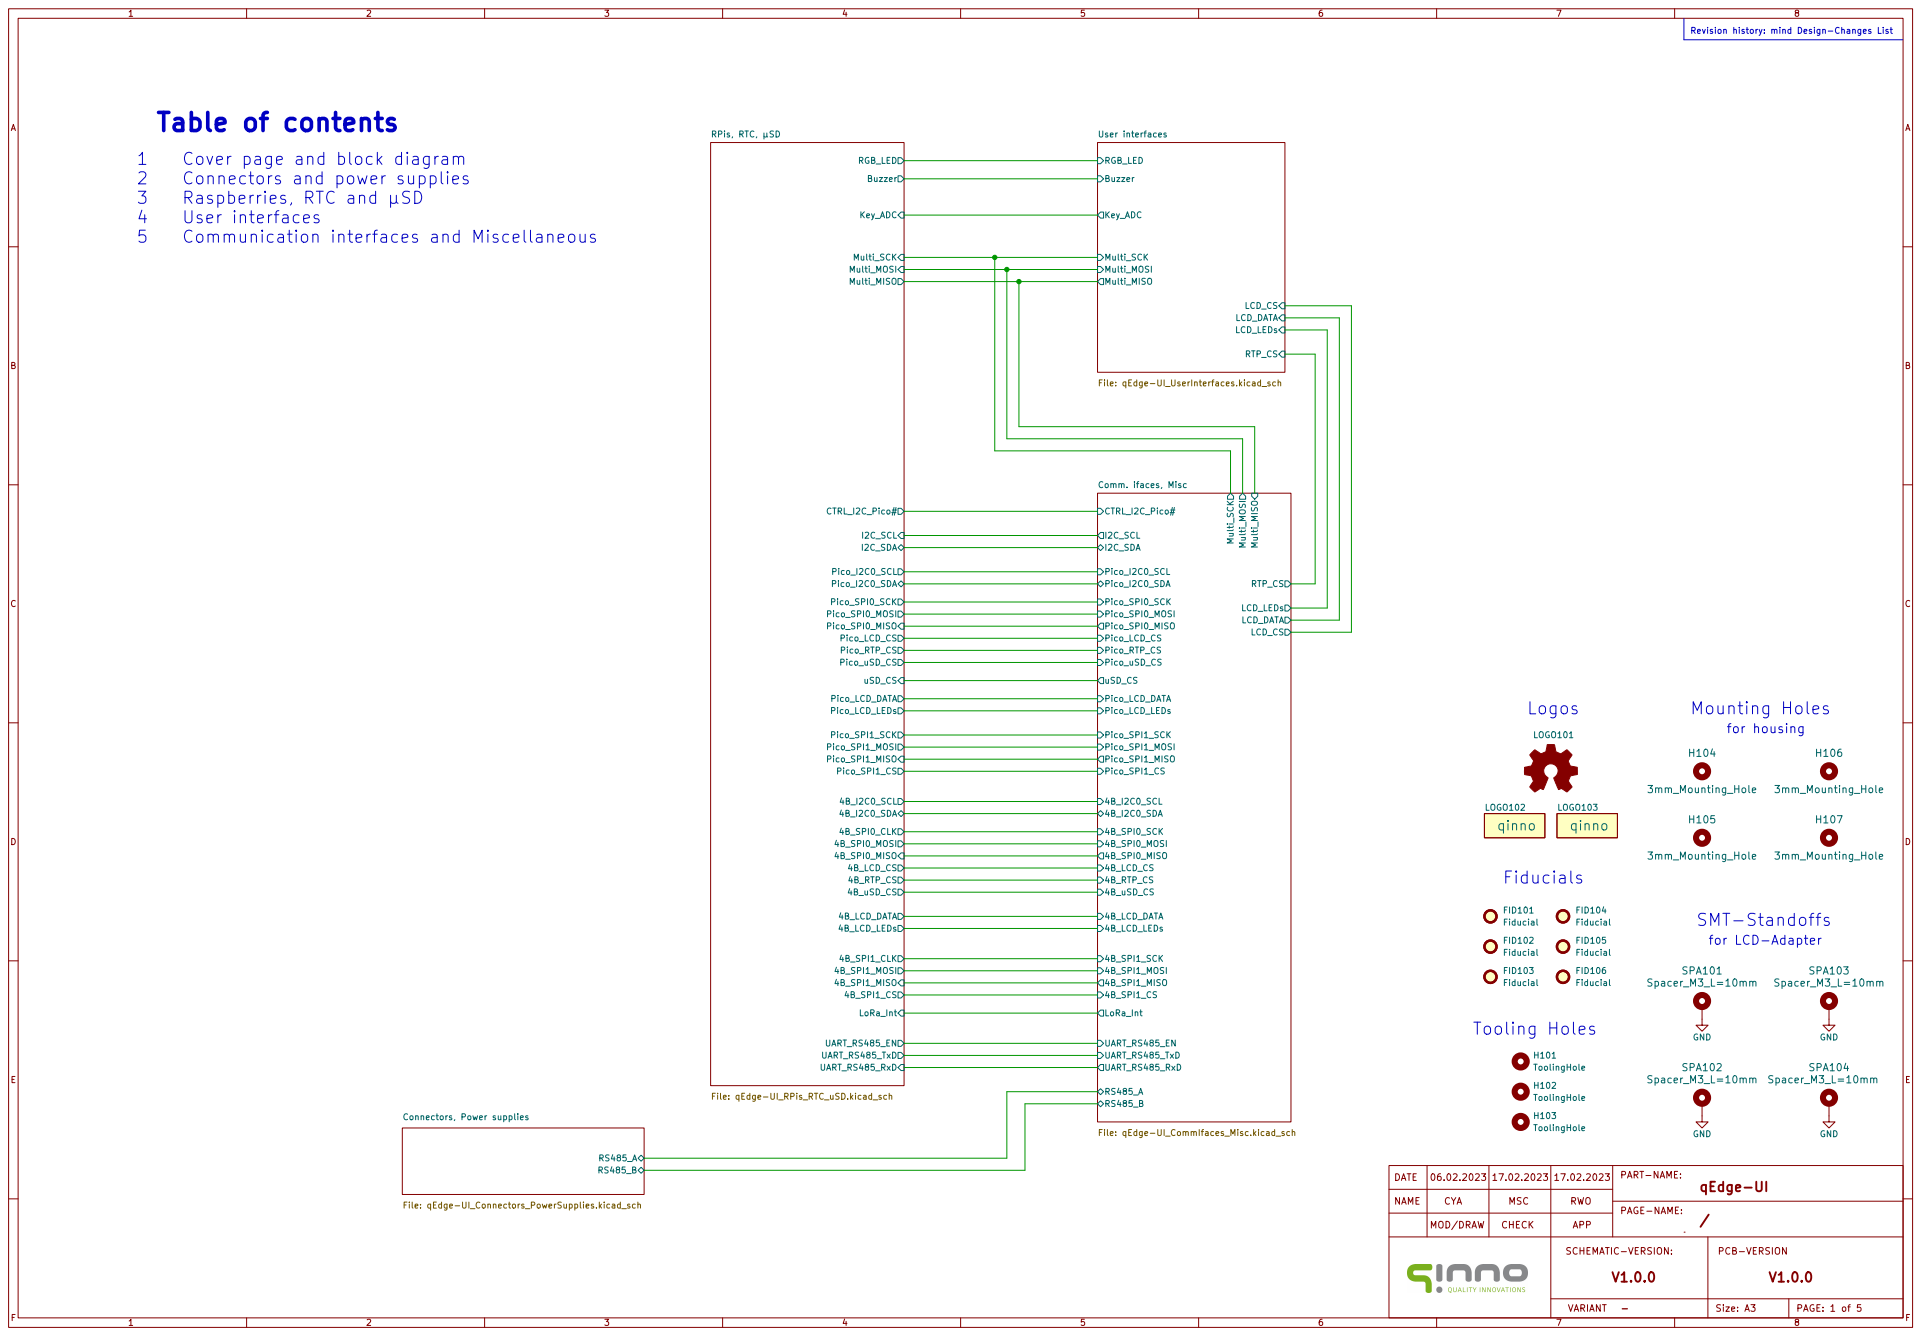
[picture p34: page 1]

Revision history: mind Design-Changes List

User interfaces File: qEdge-UI_UserInterfaces.kicad_sch

1 Cover page and block diagram
2 Connectors and power supplies
4 User interfaces
5 Communication interfaces and Miscellaneous

SCHEMATIC-VERSION: | Size: A3 PCB-VERSION

VARIANT -

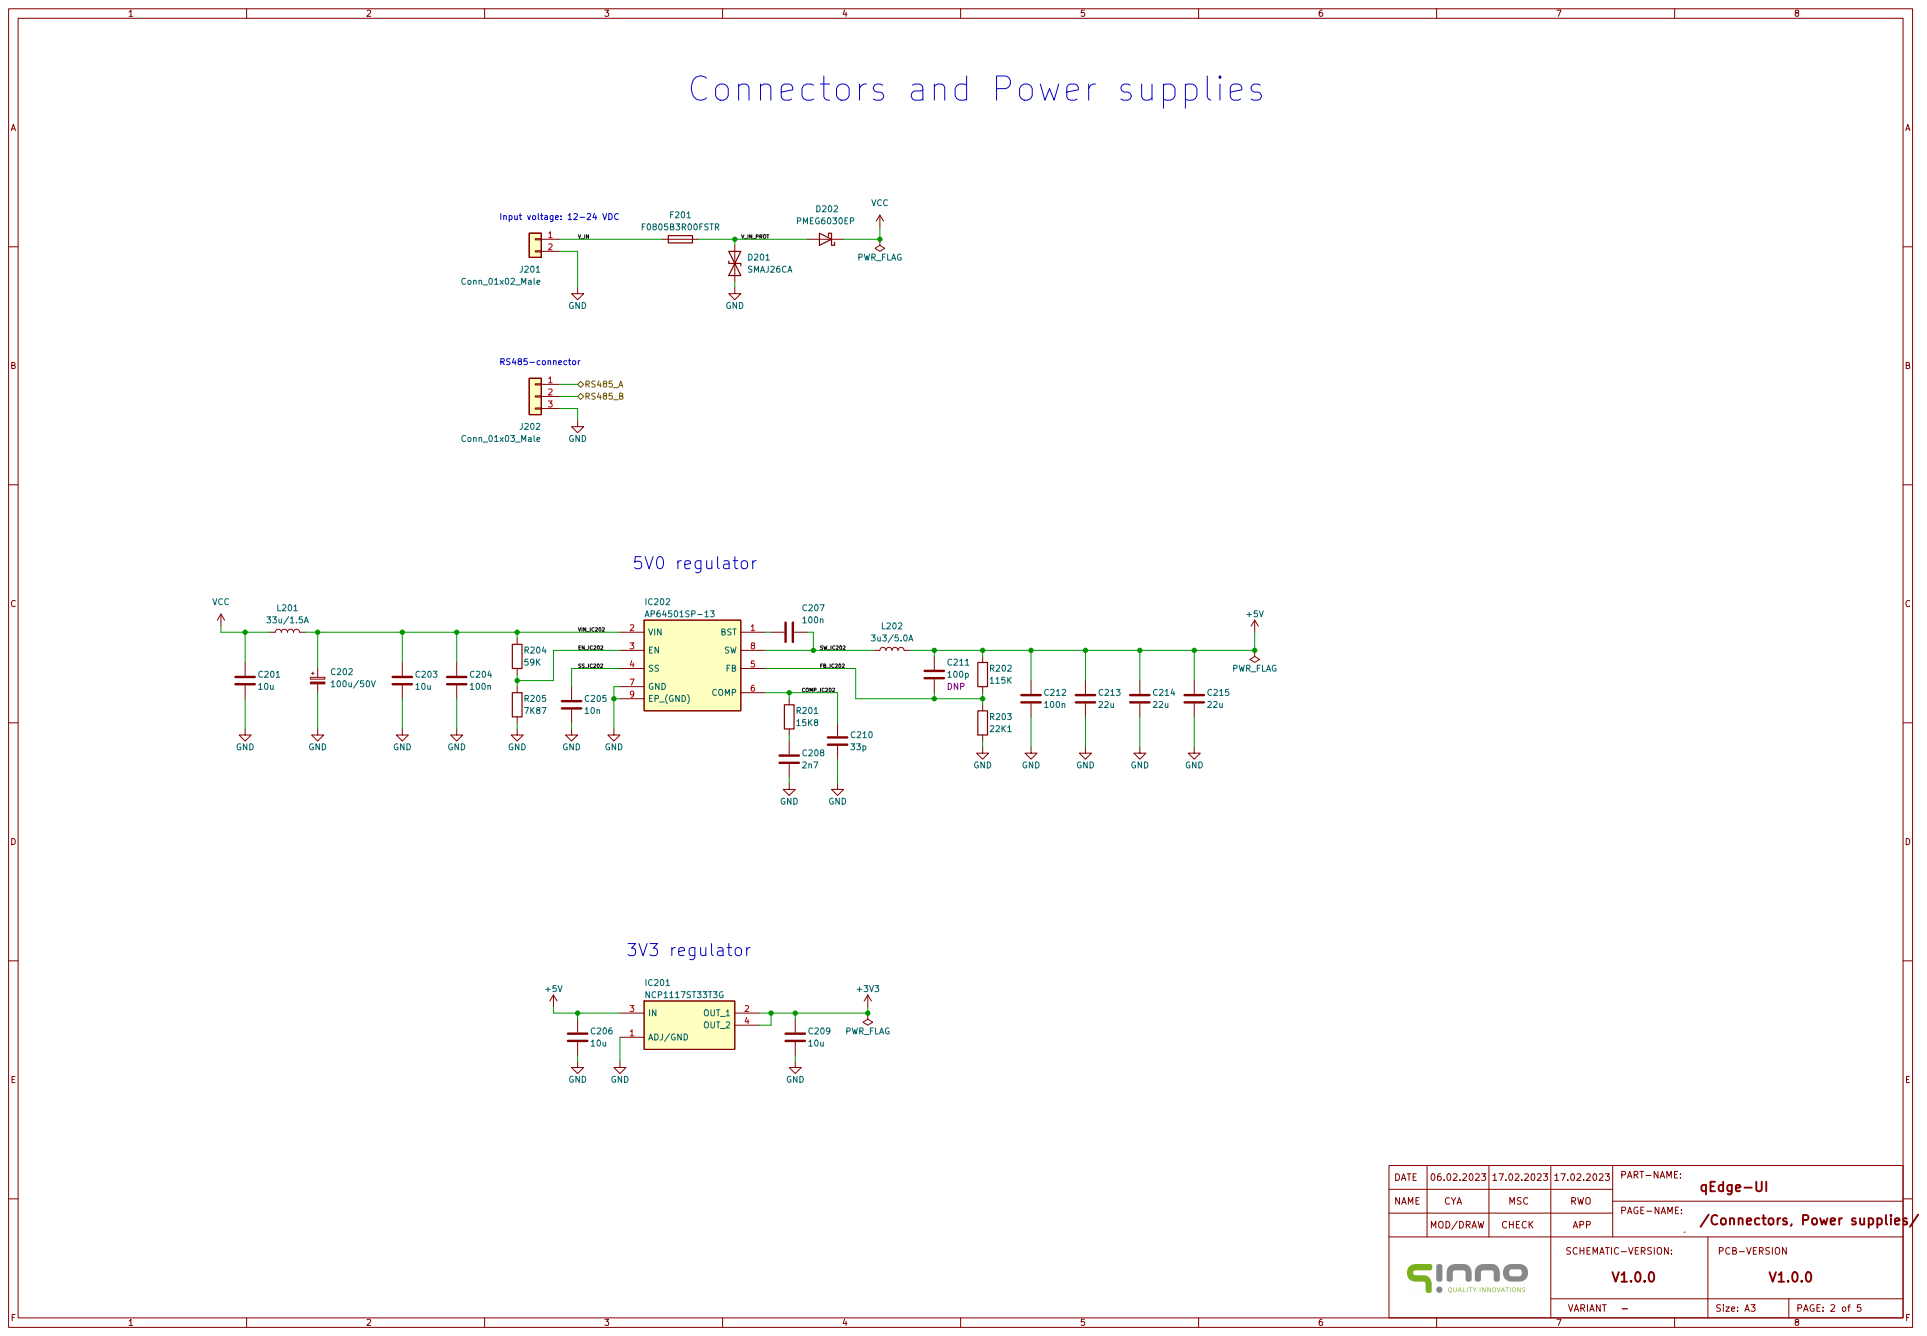
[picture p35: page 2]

Connectors and Power supplies

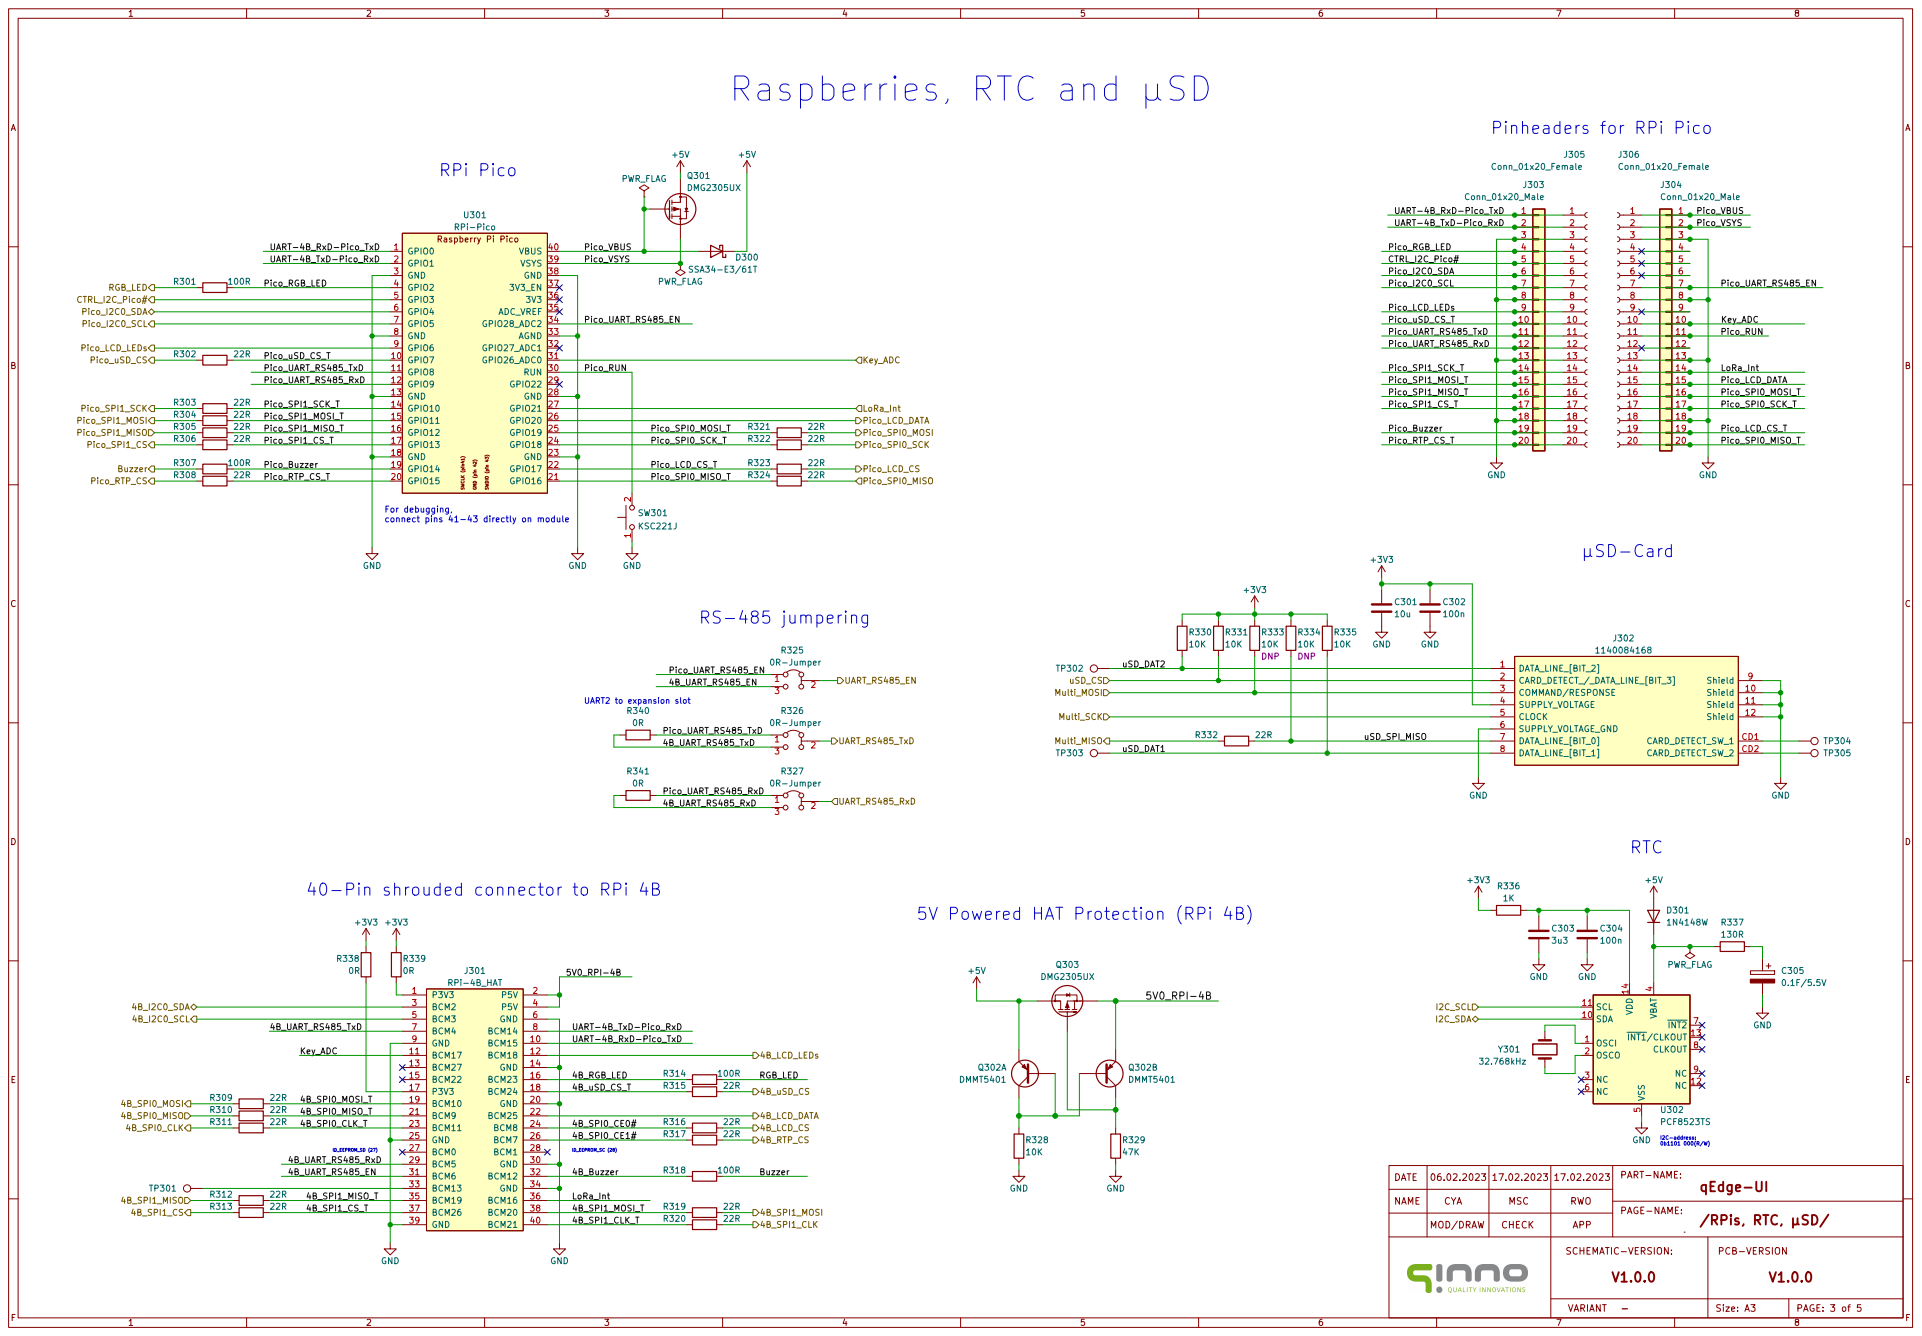
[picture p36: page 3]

Pinheaders for RPi Pico

17 | 17
18 | 18
19 | 19
20 | 20

For debugging,
connect pins 41-43 directly on module

I2C-address: 0b1101 000(R/W) 40-Pin shrouded connector to RPi 4B

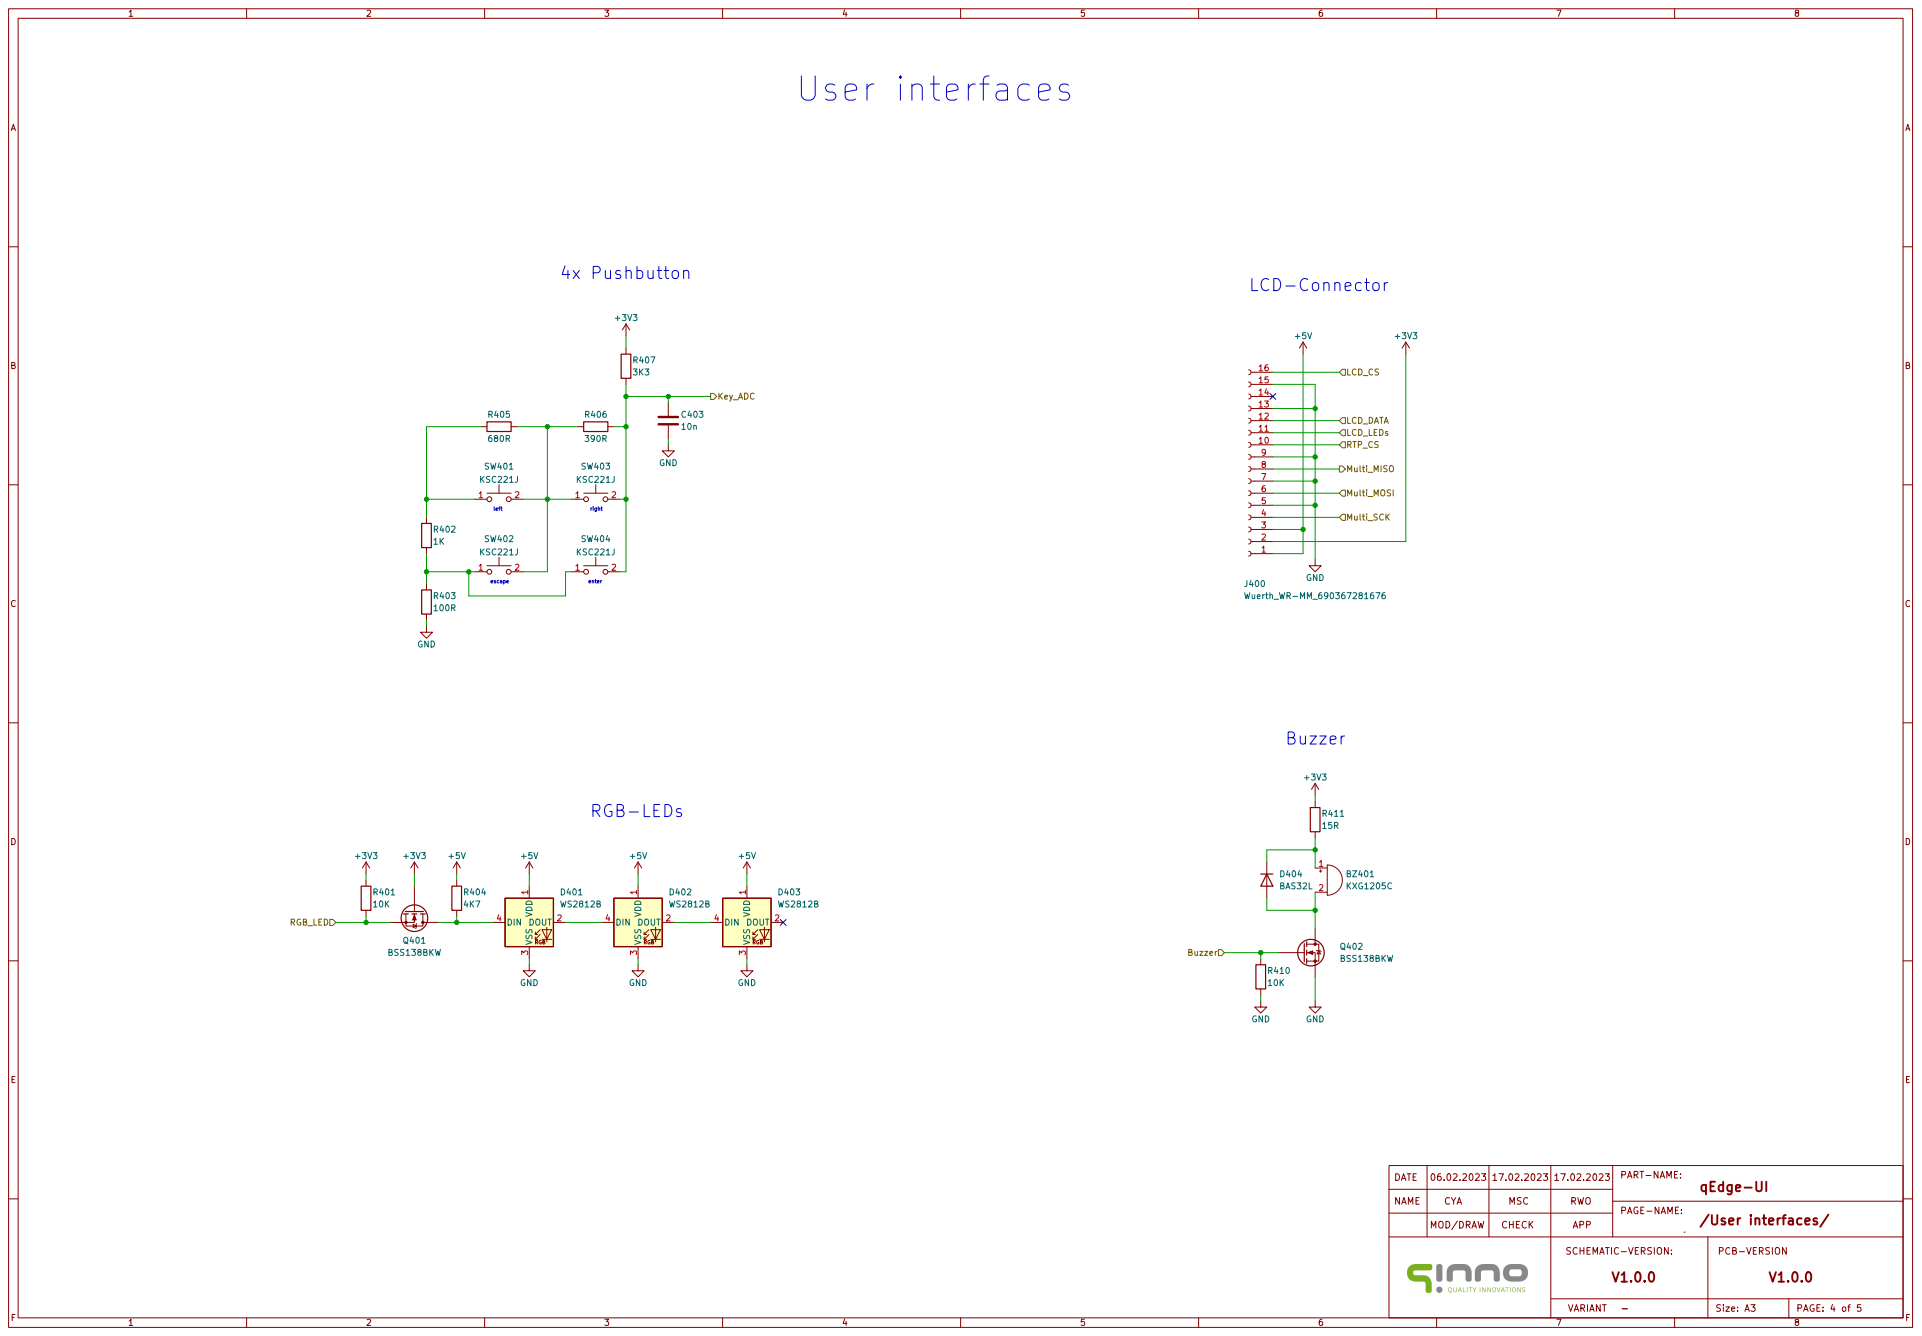
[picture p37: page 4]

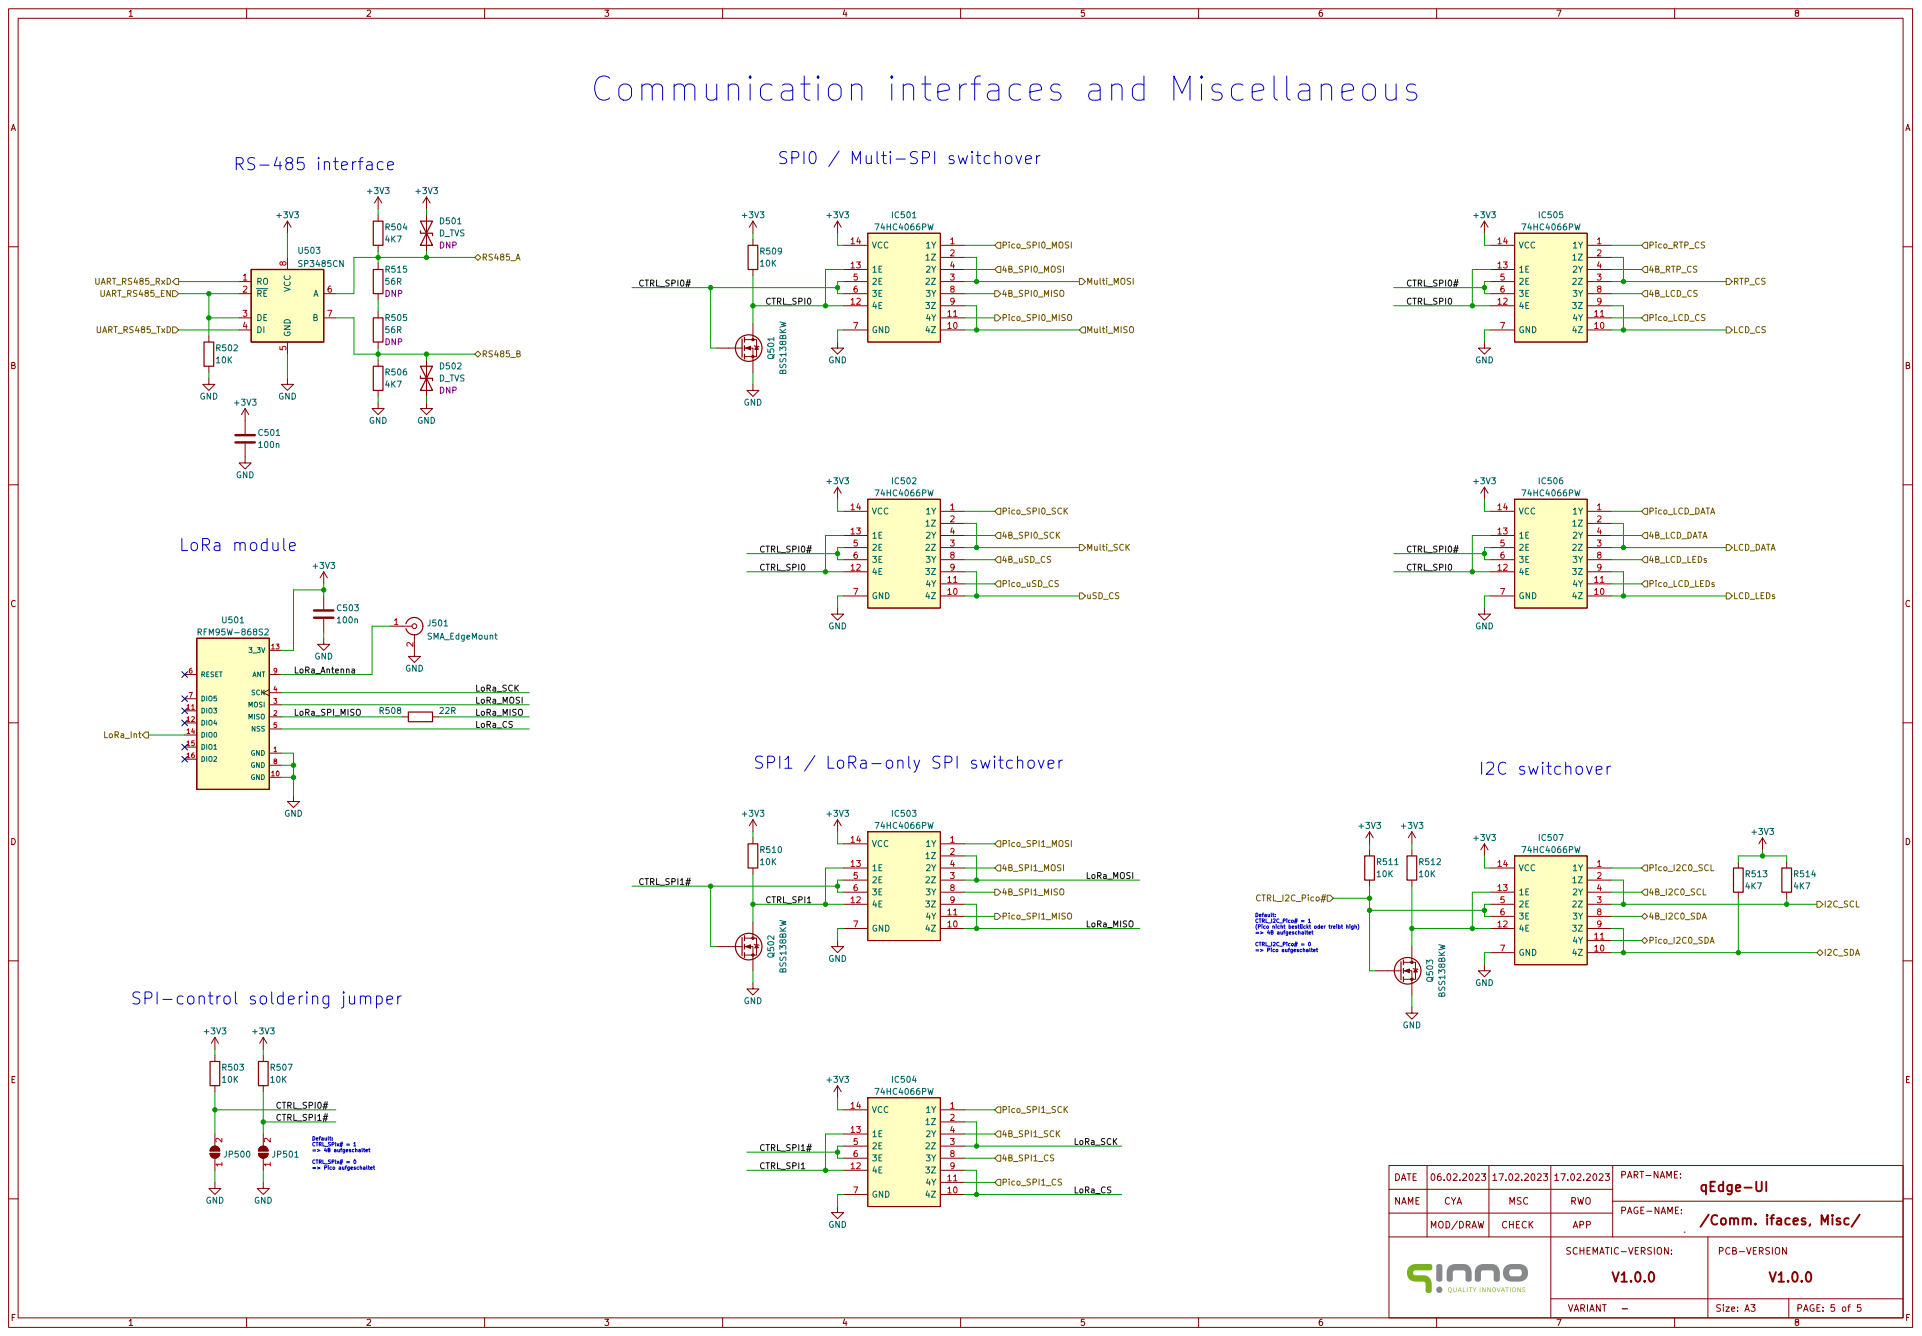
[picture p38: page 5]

þÿ(Pico nicht bestückt oder treibt high) => 4B aufgeschaltet CTRL_I2C_Pico# = 0 => Pico aufgeschaltet LoRa module

SPI1 / LoRa-only SPI switchover

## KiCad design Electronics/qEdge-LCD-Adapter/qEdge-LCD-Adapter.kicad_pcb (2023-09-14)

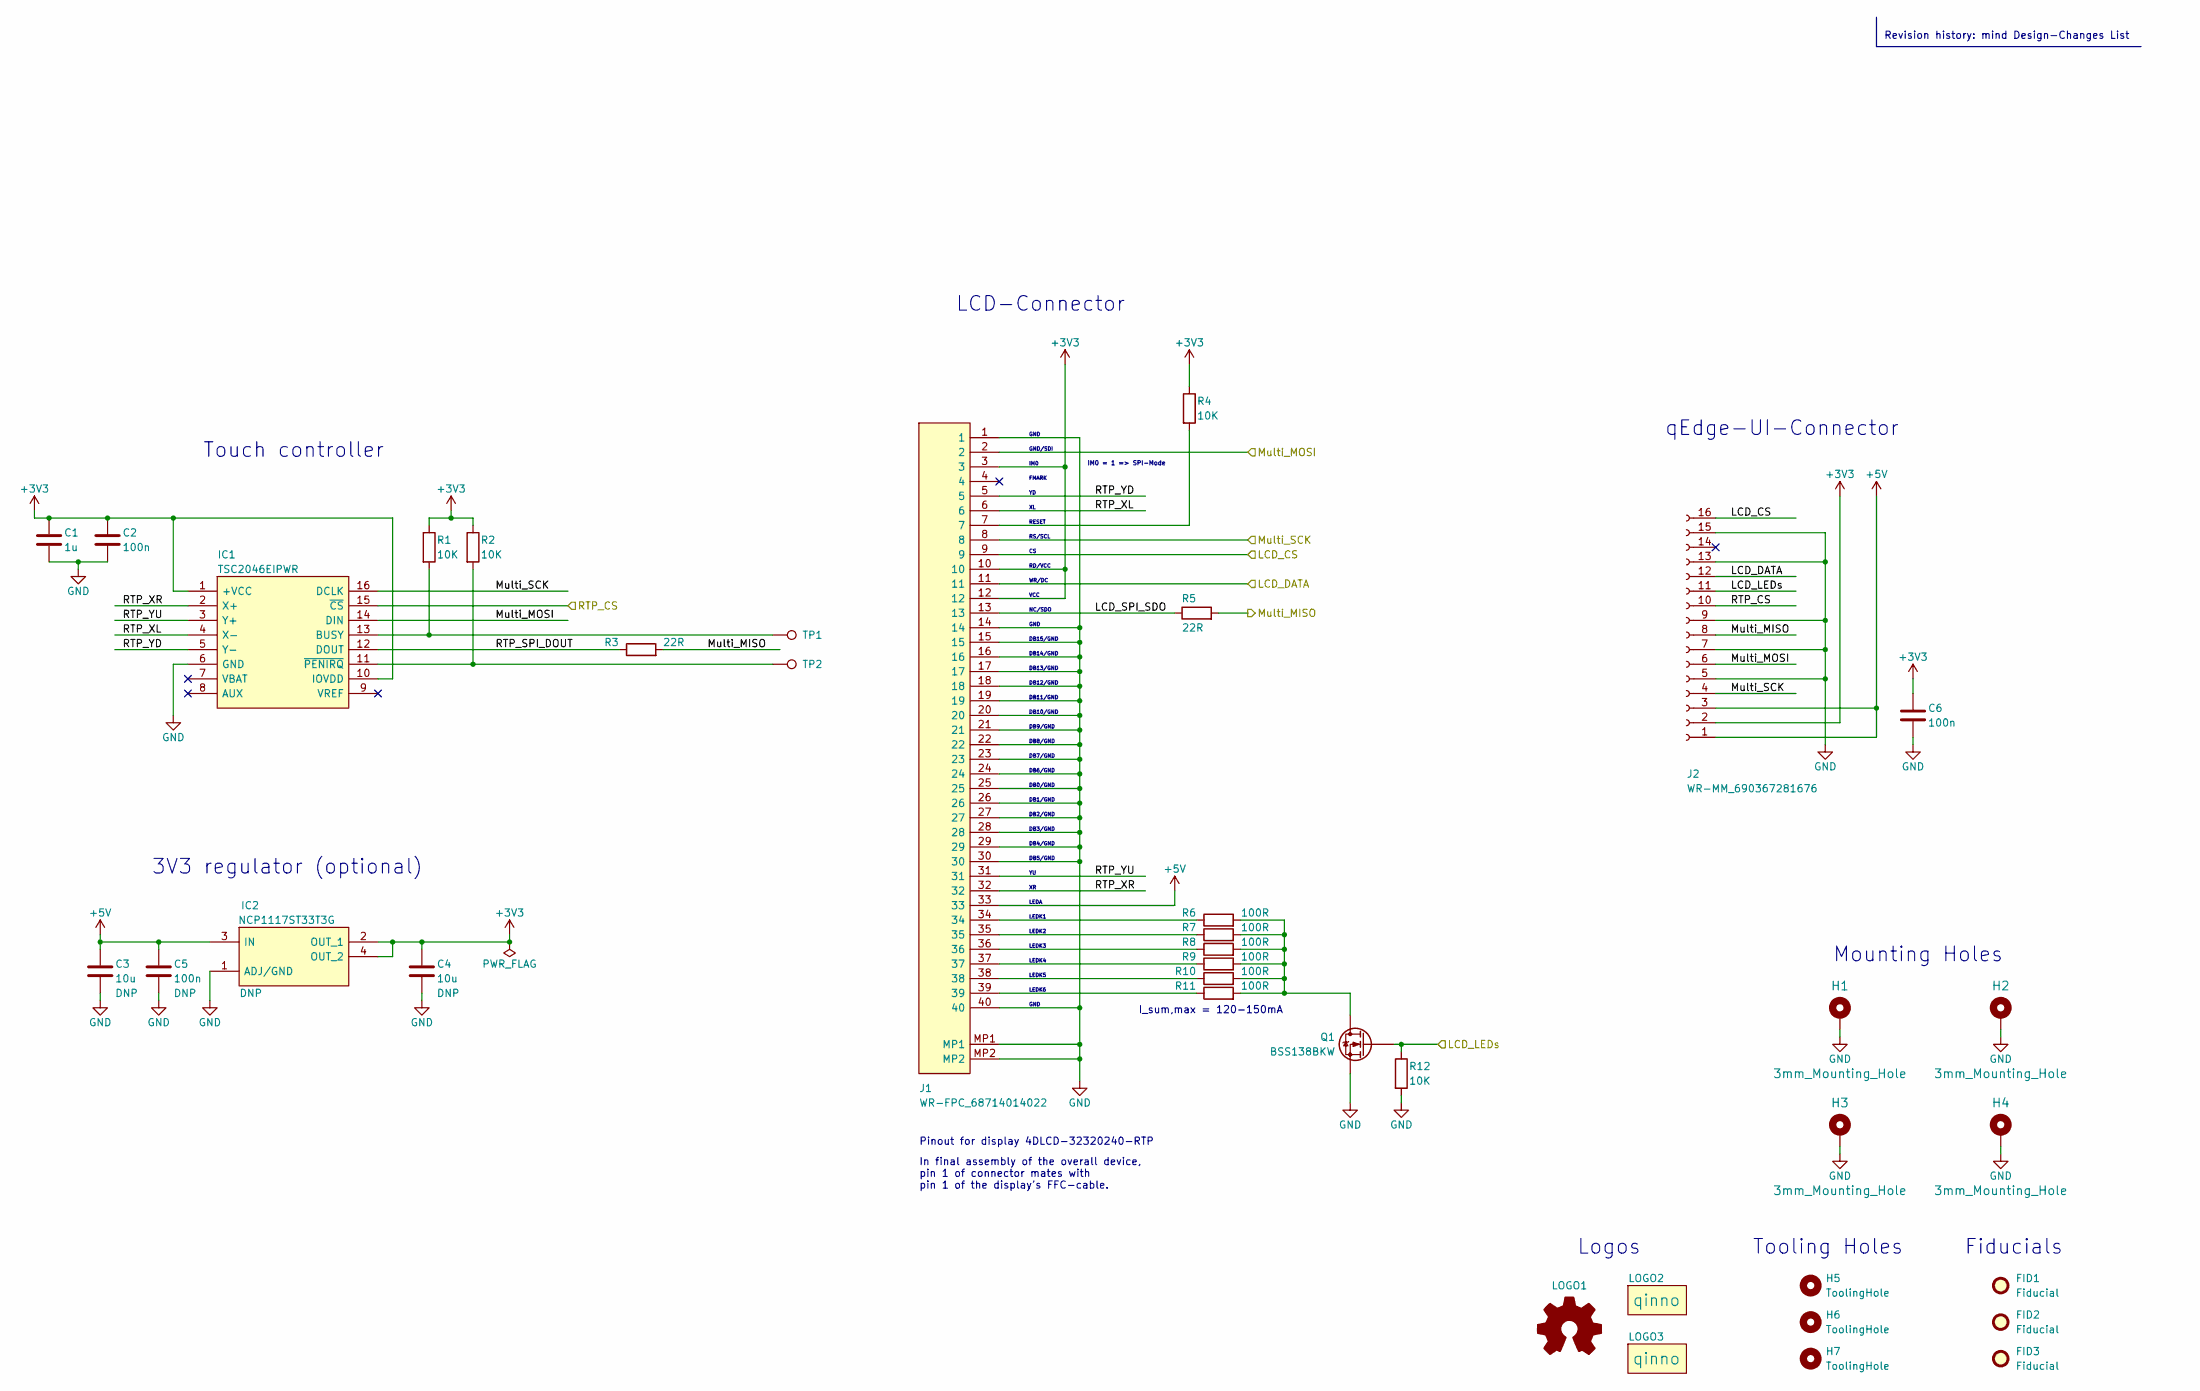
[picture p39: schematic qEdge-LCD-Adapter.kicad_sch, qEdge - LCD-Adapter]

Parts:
C1: 1u; C_0603_1608Metric
C2, C5, C6: 100n; C_0603_1608Metric
C3, C4: 10u; C_0603_1608Metric
FID1, FID2, FID3: Fiducial; Fiducial_1mm_Mask3mm
H1, H2, H3, H4: 3mm_Mounting_Hole; MountingHole_3.2mm_M3_DIN965_Pad
H5, H6, H7: ToolingHole; JLCSMT_ToolingHole
IC1: TSC2046EIPWR; SOP65P640X120-16N; Manufacturer_Part_Number TSC2046EIPWR
IC2: NCP1117ST33T3G; SOT230P700X180-4N; Manufacturer_Part_Number NCP1117ST33T3G
J1: WR-FPC_68714014022; Wuerth_WR-FPC_68714014022; Manufacturer_Part_Number 68714014022
J2: WR-MM_690367281676; Wuerth_WR-MM_690367281676; Manufacturer_Part_Number 690367281676
LOGO1: Logo_Open_Hardware_Small; OSHW-Logo2_9.8x8mm_Copper
LOGO2, LOGO3: qinno; Logo-qinno-2
Q1: BSS138BKW; SOT-323_SC-70; Manufacturer_Part_Number BSS138BKW,115
R1, R2, R4, R12: 10K; R_0603_1608Metric
R3, R5: 22R; R_0603_1608Metric
R6, R7, R8, R9, R10, R11: 100R; R_0603_1608Metric
TP1, TP2: TestPoint; TestPoint_Pad_D1.0mm

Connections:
+3V3: C1.1, C2.1, C4.1, C6.1, IC1.1 (+VCC), IC1.10 (IOVDD), IC2.2 (OUT_1), IC2.4 (OUT_2), J1.3, J1.10, J1.12, J2.2, R1.1, R2.1, R4.1
+5V: C3.1, C5.1, IC2.3 (IN), J1.33, J2.1, J2.3
/LCD_CS: J1.9, J2.16
/LCD_DATA: J1.11, J2.12
/LCD_LEDs: J2.11, Q1.1 (G), R12.1
/LCD_SPI_SDO: J1.13, R5.1
/Multi_MISO: J2.8, R3.2, R5.2
/Multi_MOSI: IC1.14 (DIN), J1.2, J2.6
/Multi_SCK: IC1.16 (DCLK), J1.8, J2.4
/RTP_CS: IC1.15 (~CS), J2.10
/RTP_SPI_DOUT: IC1.12 (DOUT), R3.1
/RTP_XL: IC1.4 (X-), J1.6
/RTP_XR: IC1.2 (X+), J1.32
/RTP_YD: IC1.5 (Y-), J1.5
/RTP_YU: IC1.3 (Y+), J1.31
GND: C1.2, C2.2, C3.2, C4.2, C5.2, C6.2, H1.1, H2.1, H3.1, H4.1, IC1.6 (GND), IC2.1 (ADJ/GND), J1.1, J1.14, J1.15, J1.16, J1.17, J1.18, J1.19, J1.20, J1.21, J1.22, J1.23, J1.24, J1.25, J1.26, J1.27, J1.28, J1.29, J1.30, J1.40, J1.MP1, J1.MP2, J2.5, J2.7, J2.9, J2.13, J2.15, Q1.2 (S), R12.2
unnamed: IC1.11 (~PENIRQ), R2.2, TP2.1
unnamed: IC1.13 (BUSY), R1.2, TP1.1
unnamed: J1.7, R4.2
unnamed: J1.34, R6.1
unnamed: J1.35, R7.1
unnamed: J1.36, R8.1
unnamed: J1.37, R9.1
unnamed: J1.38, R10.1
unnamed: J1.39, R11.1
unnamed: Q1.3 (D), R6.2, R7.2, R8.2, R9.2, R10.2, R11.2

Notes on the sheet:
LEDK3
GND
DB3/GND
DB9/GND
LEDK4
DB14/GND
LEDK2
DB5/GND
WR/DC
FMARK
Tooling Holes
IM0
LEDA
Pinout for display 4DLCD-32320240-RTP
RS/SCL
DB1/GND
LEDK5
RESET
DB10/GND
RD/VCC
DB8/GND
NC/SDO
DB0/GND
LEDK1
I_sum,max = 120-150mA
LEDK6
Logos
DB2/GND
DB11/GND
DB4/GND
qEdge-UI-Connector
DB7/GND
DB13/GND
LCD-Connector
DB15/GND
3V3 regulator (optional)
GND/SDI
Mounting Holes
Revision history: mind Design-Changes List
Touch controller

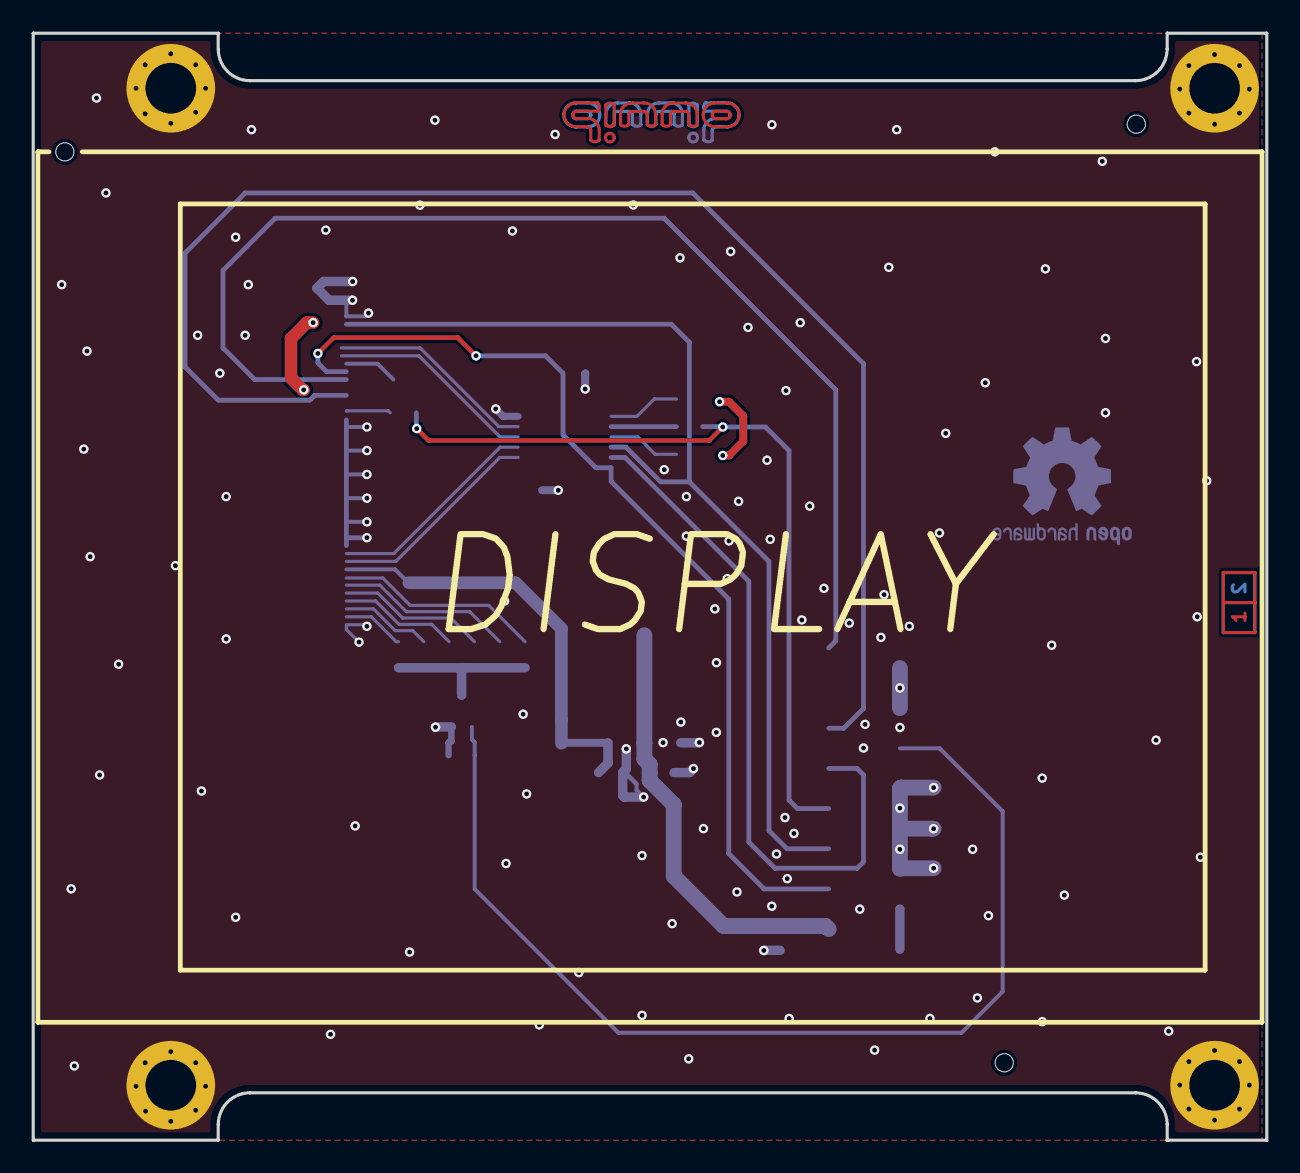
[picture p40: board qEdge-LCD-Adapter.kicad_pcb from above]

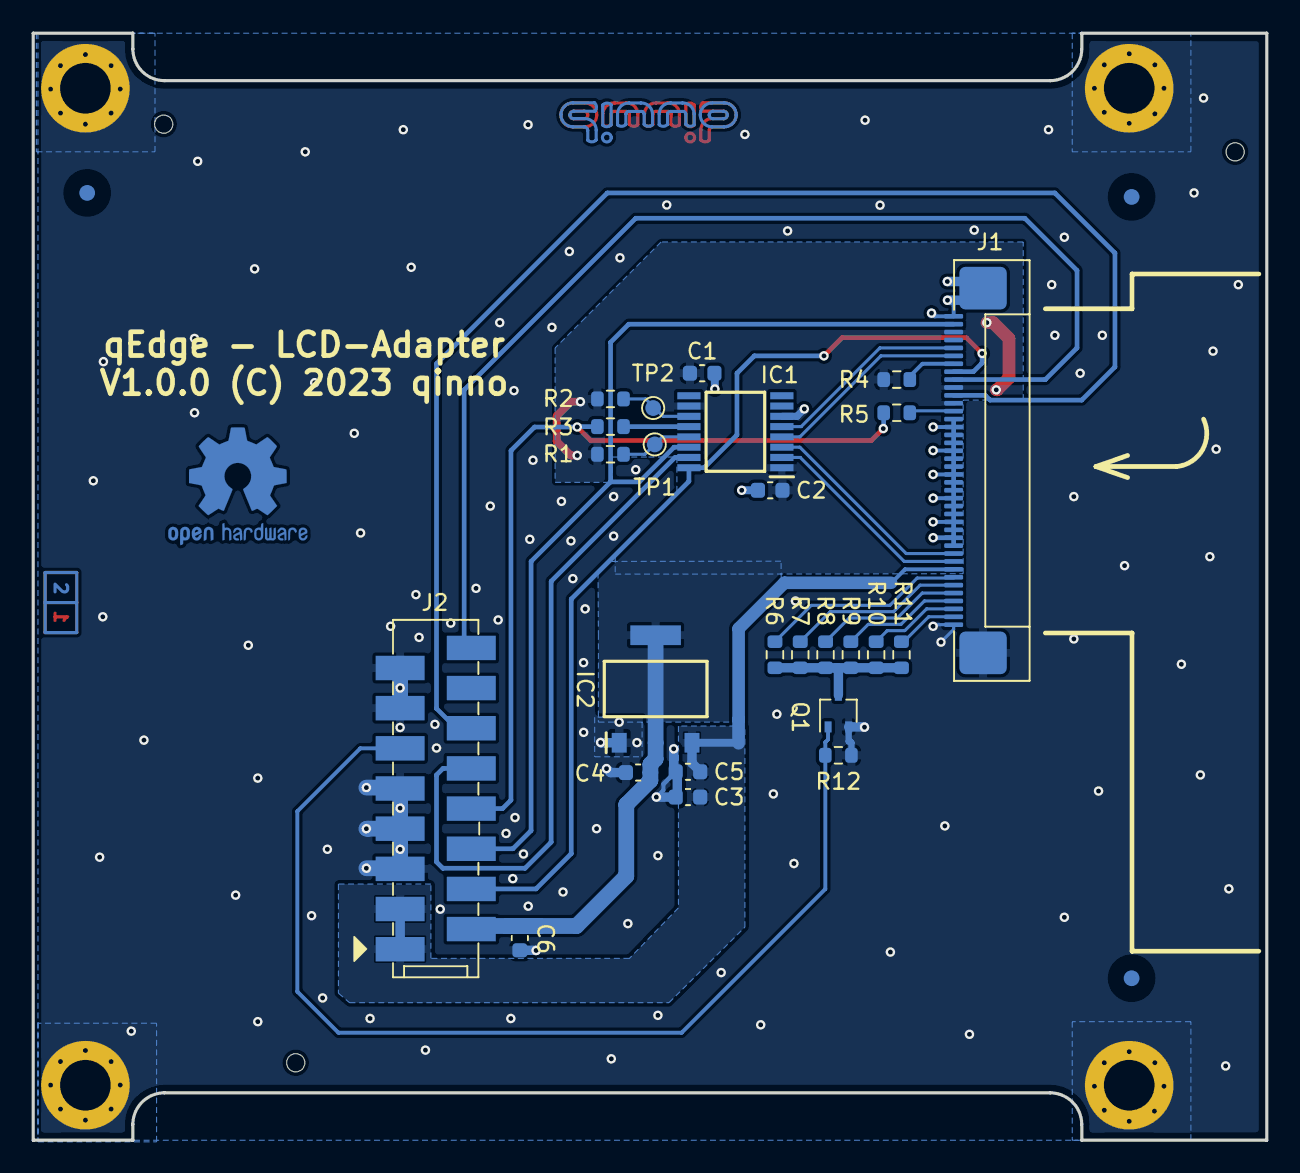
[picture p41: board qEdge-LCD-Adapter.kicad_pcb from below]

Board: 2 copper layers, 78.0 x 70.0 mm, 38 parts (30 on the bottom side), 26 nets.

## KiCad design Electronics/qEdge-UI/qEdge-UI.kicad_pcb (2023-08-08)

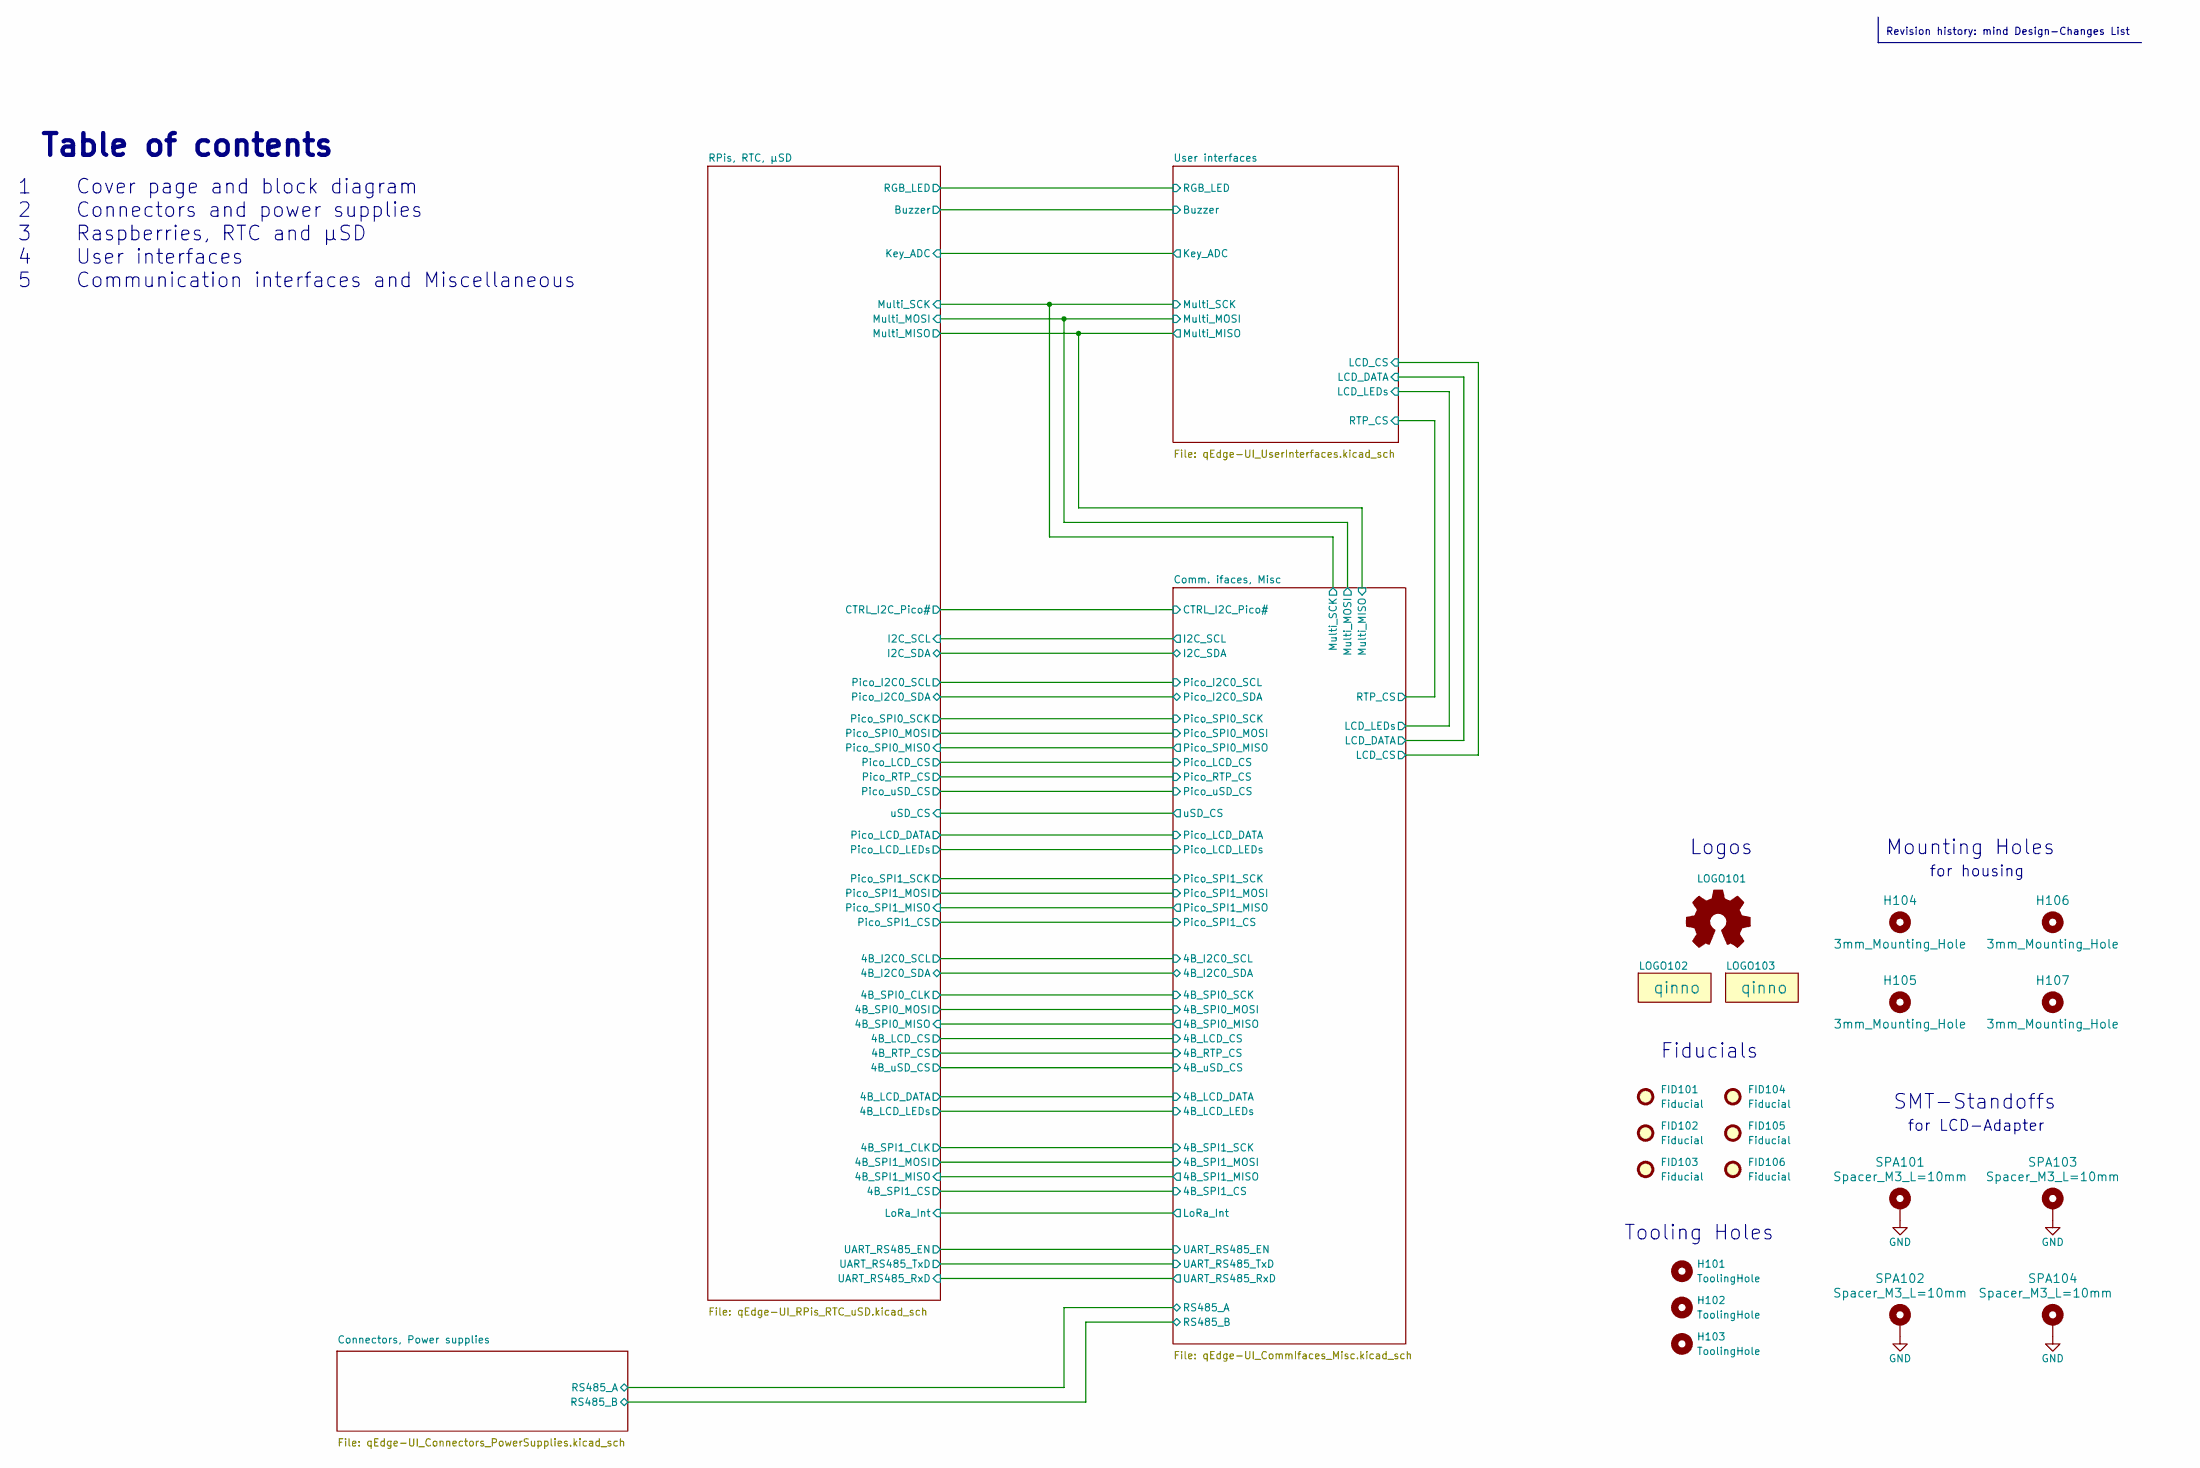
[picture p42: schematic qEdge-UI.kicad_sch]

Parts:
FID101, FID102, FID103, FID104, FID105, FID106: Fiducial; Fiducial_1mm_Mask3mm
H101, H102, H103: ToolingHole; JLCSMT_ToolingHole
H104, H105, H106, H107: 3mm_Mounting_Hole; NPTH_3mm_ID
LOGO101: Logo_Open_Hardware_Small; OSHW-Logo2_9.8x8mm_Copper
LOGO102, LOGO103: qinno; Logo-qinno-2
SPA101, SPA102, SPA103, SPA104: Spacer_M3_L=10mm; Mounting_Wuerth_WA-SMSI-M3_H10mm_9774100360; Manufacturer_Part_Number 9774100360

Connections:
GND: SPA101.1, SPA102.1, SPA103.1, SPA104.1; also elsewhere on the board

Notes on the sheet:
Logos
Mounting Holes
SMT-Standoffs
Tooling Holes
Revision history: mind Design-Changes List
for LCD-Adapter
Table of contents
for housing
1 Cover page and block diagram 2 Connectors and power supplies 3 Raspberries, RTC and µSD 4 User interfaces 5 Communication interfaces and Miscellaneous
Fiducials

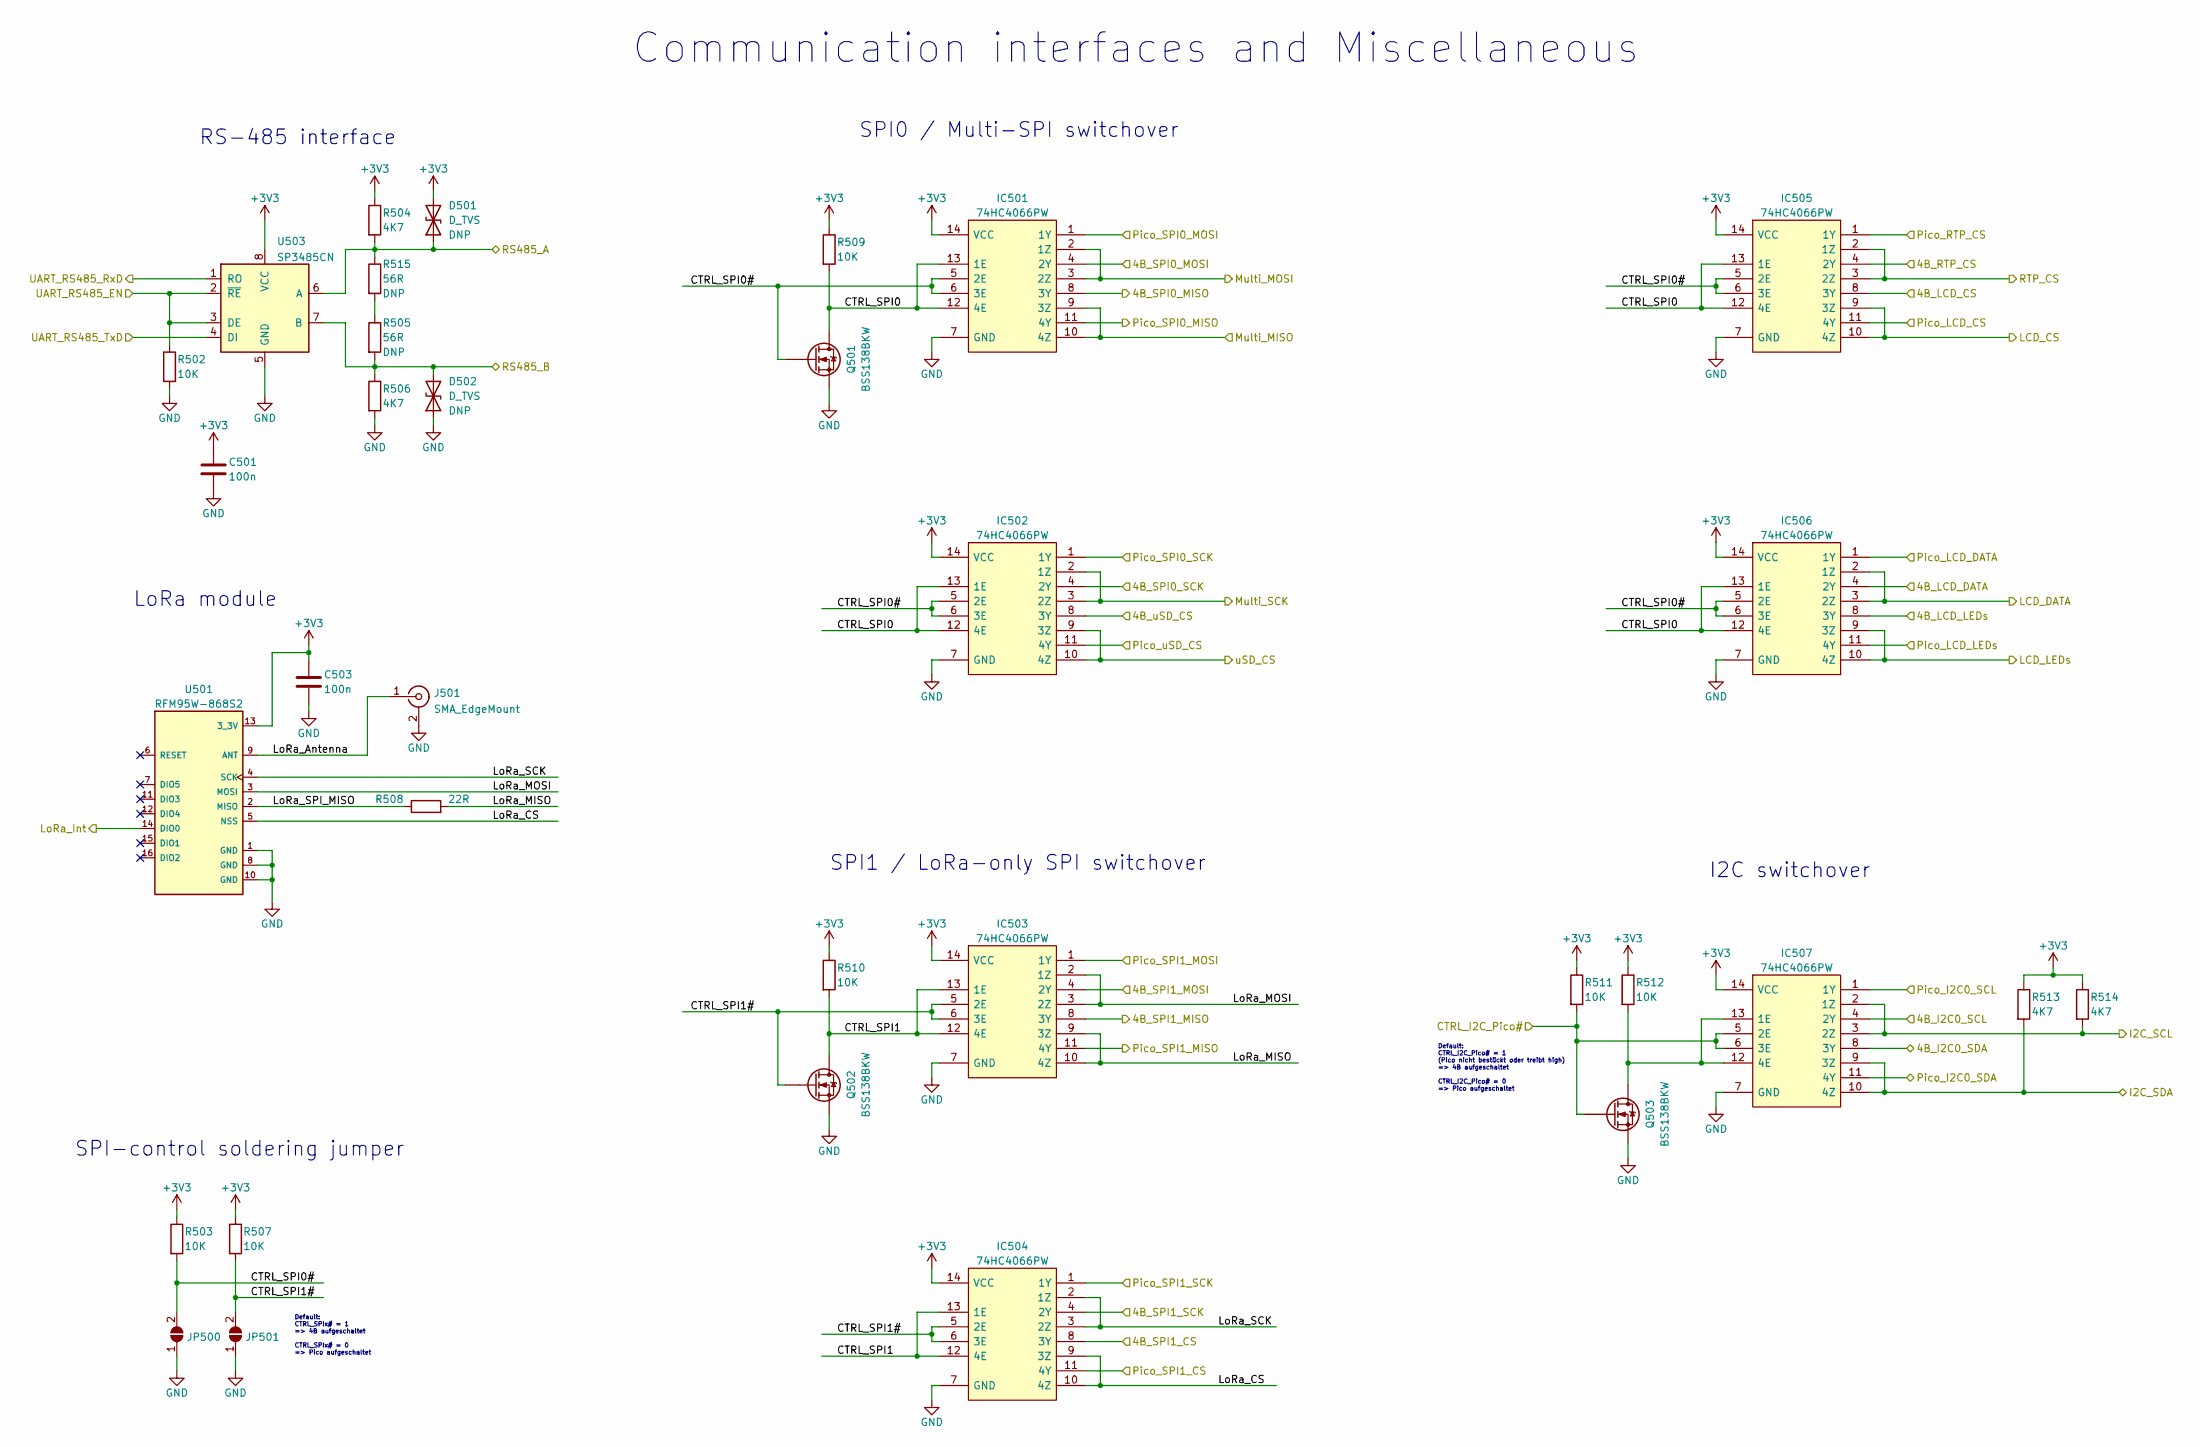
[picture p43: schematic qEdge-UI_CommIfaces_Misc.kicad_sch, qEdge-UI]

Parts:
C501, C503: 100n; C_0603_1608Metric
D501, D502: D_TVS; D_SMA_bipolar
IC501, IC502, IC503, IC504, IC505, IC506, IC507: 74HC4066PW; SOP65P640X110-14N; Manufacturer_Part_Number 74HC4066PW,118
J501: SMA_EdgeMount; Samtec_SMA-J-P-X-ST-EM1; Manufacturer_Part_Number SMA-J-P-H-ST-EM1
JP500, JP501: SolderJumper_2_Open; SolderJumper-2_P1.3mm_Open_TrianglePad1.0x1.5mm
Q501, Q502, Q503: BSS138BKW; SOT-323_SC-70; Manufacturer_Part_Number BSS138BKW,115
R502, R503, R507, R509, R510, R511, R512: 10K; R_0603_1608Metric
R504, R506, R513, R514: 4K7; R_0603_1608Metric
R505, R515: 56R; R_0603_1608Metric
R508: 22R; R_0603_1608Metric
U501: RFM95W-868S2; HopeRF_RFM95W-868S2; Manufacturer_Part_Number RFM95W-868S2
U503: SP3485CN; SOIC-8_3.9x4.9mm_P1.27mm; Manufacturer_Part_Number SP3485CN-L/TR

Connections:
+3V3: C501.1, C503.1, D501.2 (A2), IC501.14 (VCC), IC502.14 (VCC), IC503.14 (VCC), IC504.14 (VCC), IC505.14 (VCC), IC506.14 (VCC), IC507.14 (VCC), R503.1, R504.1, R507.1, R509.1, R510.1, R511.1, R512.1, R513.1, R514.1, U501.13 (3_3V), U503.8 (VCC); also elsewhere on the board
/Comm. ifaces, Misc/4B_I2C0_SCL: IC507.4 (2Y); also elsewhere on the board
/Comm. ifaces, Misc/4B_I2C0_SDA: IC507.8 (3Y); also elsewhere on the board
/Comm. ifaces, Misc/4B_LCD_CS: IC505.8 (3Y); also elsewhere on the board
/Comm. ifaces, Misc/4B_LCD_DATA: IC506.4 (2Y); also elsewhere on the board
/Comm. ifaces, Misc/4B_LCD_LEDs: IC506.8 (3Y); also elsewhere on the board
/Comm. ifaces, Misc/4B_RTP_CS: IC505.4 (2Y); also elsewhere on the board
/Comm. ifaces, Misc/4B_SPI0_MISO: IC501.8 (3Y); also elsewhere on the board
/Comm. ifaces, Misc/4B_SPI0_MOSI: IC501.4 (2Y); also elsewhere on the board
/Comm. ifaces, Misc/4B_SPI0_SCK: IC502.4 (2Y); also elsewhere on the board
/Comm. ifaces, Misc/4B_SPI1_CS: IC504.8 (3Y); also elsewhere on the board
/Comm. ifaces, Misc/4B_SPI1_MISO: IC503.8 (3Y); also elsewhere on the board
/Comm. ifaces, Misc/4B_SPI1_MOSI: IC503.4 (2Y); also elsewhere on the board
/Comm. ifaces, Misc/4B_SPI1_SCK: IC504.4 (2Y); also elsewhere on the board
/Comm. ifaces, Misc/4B_uSD_CS: IC502.8 (3Y); also elsewhere on the board
/Comm. ifaces, Misc/CTRL_SPI0: IC501.12 (4E), IC501.13 (1E), IC502.12 (4E), IC502.13 (1E), IC505.12 (4E), IC505.13 (1E), IC506.12 (4E), IC506.13 (1E), Q501.3 (D), R509.2
/Comm. ifaces, Misc/CTRL_SPI0#: IC501.5 (2E), IC501.6 (3E), IC502.5 (2E), IC502.6 (3E), IC505.5 (2E), IC505.6 (3E), IC506.5 (2E), IC506.6 (3E), JP500.2 (B), Q501.1 (G), R503.2
/Comm. ifaces, Misc/CTRL_SPI1: IC503.12 (4E), IC503.13 (1E), IC504.12 (4E), IC504.13 (1E), Q502.3 (D), R510.2
/Comm. ifaces, Misc/CTRL_SPI1#: IC503.5 (2E), IC503.6 (3E), IC504.5 (2E), IC504.6 (3E), JP501.2 (B), Q502.1 (G), R507.2
/Comm. ifaces, Misc/I2C_SCL: IC507.2 (1Z), IC507.3 (2Z), R514.2; also elsewhere on the board
/Comm. ifaces, Misc/I2C_SDA: IC507.9 (3Z), IC507.10 (4Z), R513.2; also elsewhere on the board
/Comm. ifaces, Misc/LCD_CS: IC505.9 (3Z), IC505.10 (4Z); also elsewhere on the board
/Comm. ifaces, Misc/LCD_DATA: IC506.2 (1Z), IC506.3 (2Z); also elsewhere on the board
/Comm. ifaces, Misc/LCD_LEDs: IC506.9 (3Z), IC506.10 (4Z); also elsewhere on the board
/Comm. ifaces, Misc/LoRa_Antenna: J501.1 (In), U501.9 (ANT)
/Comm. ifaces, Misc/LoRa_CS: IC504.9 (3Z), IC504.10 (4Z), U501.5 (NSS)
/Comm. ifaces, Misc/LoRa_MISO: IC503.9 (3Z), IC503.10 (4Z), R508.2
/Comm. ifaces, Misc/LoRa_MOSI: IC503.2 (1Z), IC503.3 (2Z), U501.3 (MOSI)
/Comm. ifaces, Misc/LoRa_SCK: IC504.2 (1Z), IC504.3 (2Z), U501.4 (SCK)
/Comm. ifaces, Misc/LoRa_SPI_MISO: R508.1, U501.2 (MISO)
/Comm. ifaces, Misc/Multi_MISO: IC501.9 (3Z), IC501.10 (4Z); also elsewhere on the board
/Comm. ifaces, Misc/Multi_MOSI: IC501.2 (1Z), IC501.3 (2Z); also elsewhere on the board
/Comm. ifaces, Misc/Multi_SCK: IC502.2 (1Z), IC502.3 (2Z); also elsewhere on the board
/Comm. ifaces, Misc/Pico_LCD_CS: IC505.11 (4Y); also elsewhere on the board
/Comm. ifaces, Misc/Pico_RTP_CS: IC505.1 (1Y); also elsewhere on the board
/Comm. ifaces, Misc/Pico_SPI0_MISO: IC501.11 (4Y); also elsewhere on the board
/Comm. ifaces, Misc/Pico_SPI0_MOSI: IC501.1 (1Y); also elsewhere on the board
/Comm. ifaces, Misc/Pico_SPI0_SCK: IC502.1 (1Y); also elsewhere on the board
/Comm. ifaces, Misc/Pico_SPI1_CS: IC504.11 (4Y); also elsewhere on the board
/Comm. ifaces, Misc/Pico_SPI1_MISO: IC503.11 (4Y); also elsewhere on the board
/Comm. ifaces, Misc/Pico_SPI1_MOSI: IC503.1 (1Y); also elsewhere on the board
/Comm. ifaces, Misc/Pico_SPI1_SCK: IC504.1 (1Y); also elsewhere on the board
/Comm. ifaces, Misc/Pico_uSD_CS: IC502.11 (4Y); also elsewhere on the board
/Comm. ifaces, Misc/RS485_A: D501.1 (A1), R504.2, R515.1, U503.6 (A); also elsewhere on the board
/Comm. ifaces, Misc/RS485_B: D502.2 (A2), R505.2, R506.1, U503.7 (B); also elsewhere on the board
/Comm. ifaces, Misc/RTP_CS: IC505.2 (1Z), IC505.3 (2Z); also elsewhere on the board
/Comm. ifaces, Misc/UART_RS485_EN: R502.1, U503.2 (~RE), U503.3 (DE); also elsewhere on the board
/Comm. ifaces, Misc/UART_RS485_RxD: U503.1 (RO); also elsewhere on the board
/Comm. ifaces, Misc/UART_RS485_TxD: U503.4 (DI); also elsewhere on the board
/Comm. ifaces, Misc/uSD_CS: IC502.9 (3Z), IC502.10 (4Z); also elsewhere on the board
/RPis, RTC, µSD/CTRL_I2C_Pico#: IC507.5 (2E), IC507.6 (3E), Q503.1 (G), R511.2; also elsewhere on the board
/RPis, RTC, µSD/LoRa_Int: U501.14 (DIO0); also elsewhere on the board
/RPis, RTC, µSD/Pico_I2C0_SCL: IC507.1 (1Y); also elsewhere on the board
/RPis, RTC, µSD/Pico_I2C0_SDA: IC507.11 (4Y); also elsewhere on the board
/RPis, RTC, µSD/Pico_LCD_DATA: IC506.1 (1Y); also elsewhere on the board
/RPis, RTC, µSD/Pico_LCD_LEDs: IC506.11 (4Y); also elsewhere on the board
GND: C501.2, C503.2, D502.1 (A1), IC501.7 (GND), IC502.7 (GND), IC503.7 (GND), IC504.7 (GND), IC505.7 (GND), IC506.7 (GND), IC507.7 (GND), J501.2 (Ext), JP500.1 (A), JP501.1 (A), Q501.2 (S), Q502.2 (S), Q503.2 (S), R502.2, R506.2, U501.1 (GND), U501.8 (GND), U501.10 (GND), U503.5 (GND); also elsewhere on the board
unnamed: IC507.12 (4E), IC507.13 (1E), Q503.3 (D), R512.2
unnamed: R505.1, R515.2

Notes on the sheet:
RS-485 interface
Default: CTRL_I2C_Pico# = 1 (Pico nicht bestückt oder treibt high) => 4B aufgeschaltet CTRL_I2C_Pico# = 0 => Pico aufgeschaltet
I2C switchover
Communication interfaces and Miscellaneous
SPI0 / Multi-SPI switchover
LoRa module
Default: CTRL_SPIx# = 1 => 4B aufgeschaltet CTRL_SPIx# = 0 => Pico aufgeschaltet
SPI-control soldering jumper
SPI1 / LoRa-only SPI switchover

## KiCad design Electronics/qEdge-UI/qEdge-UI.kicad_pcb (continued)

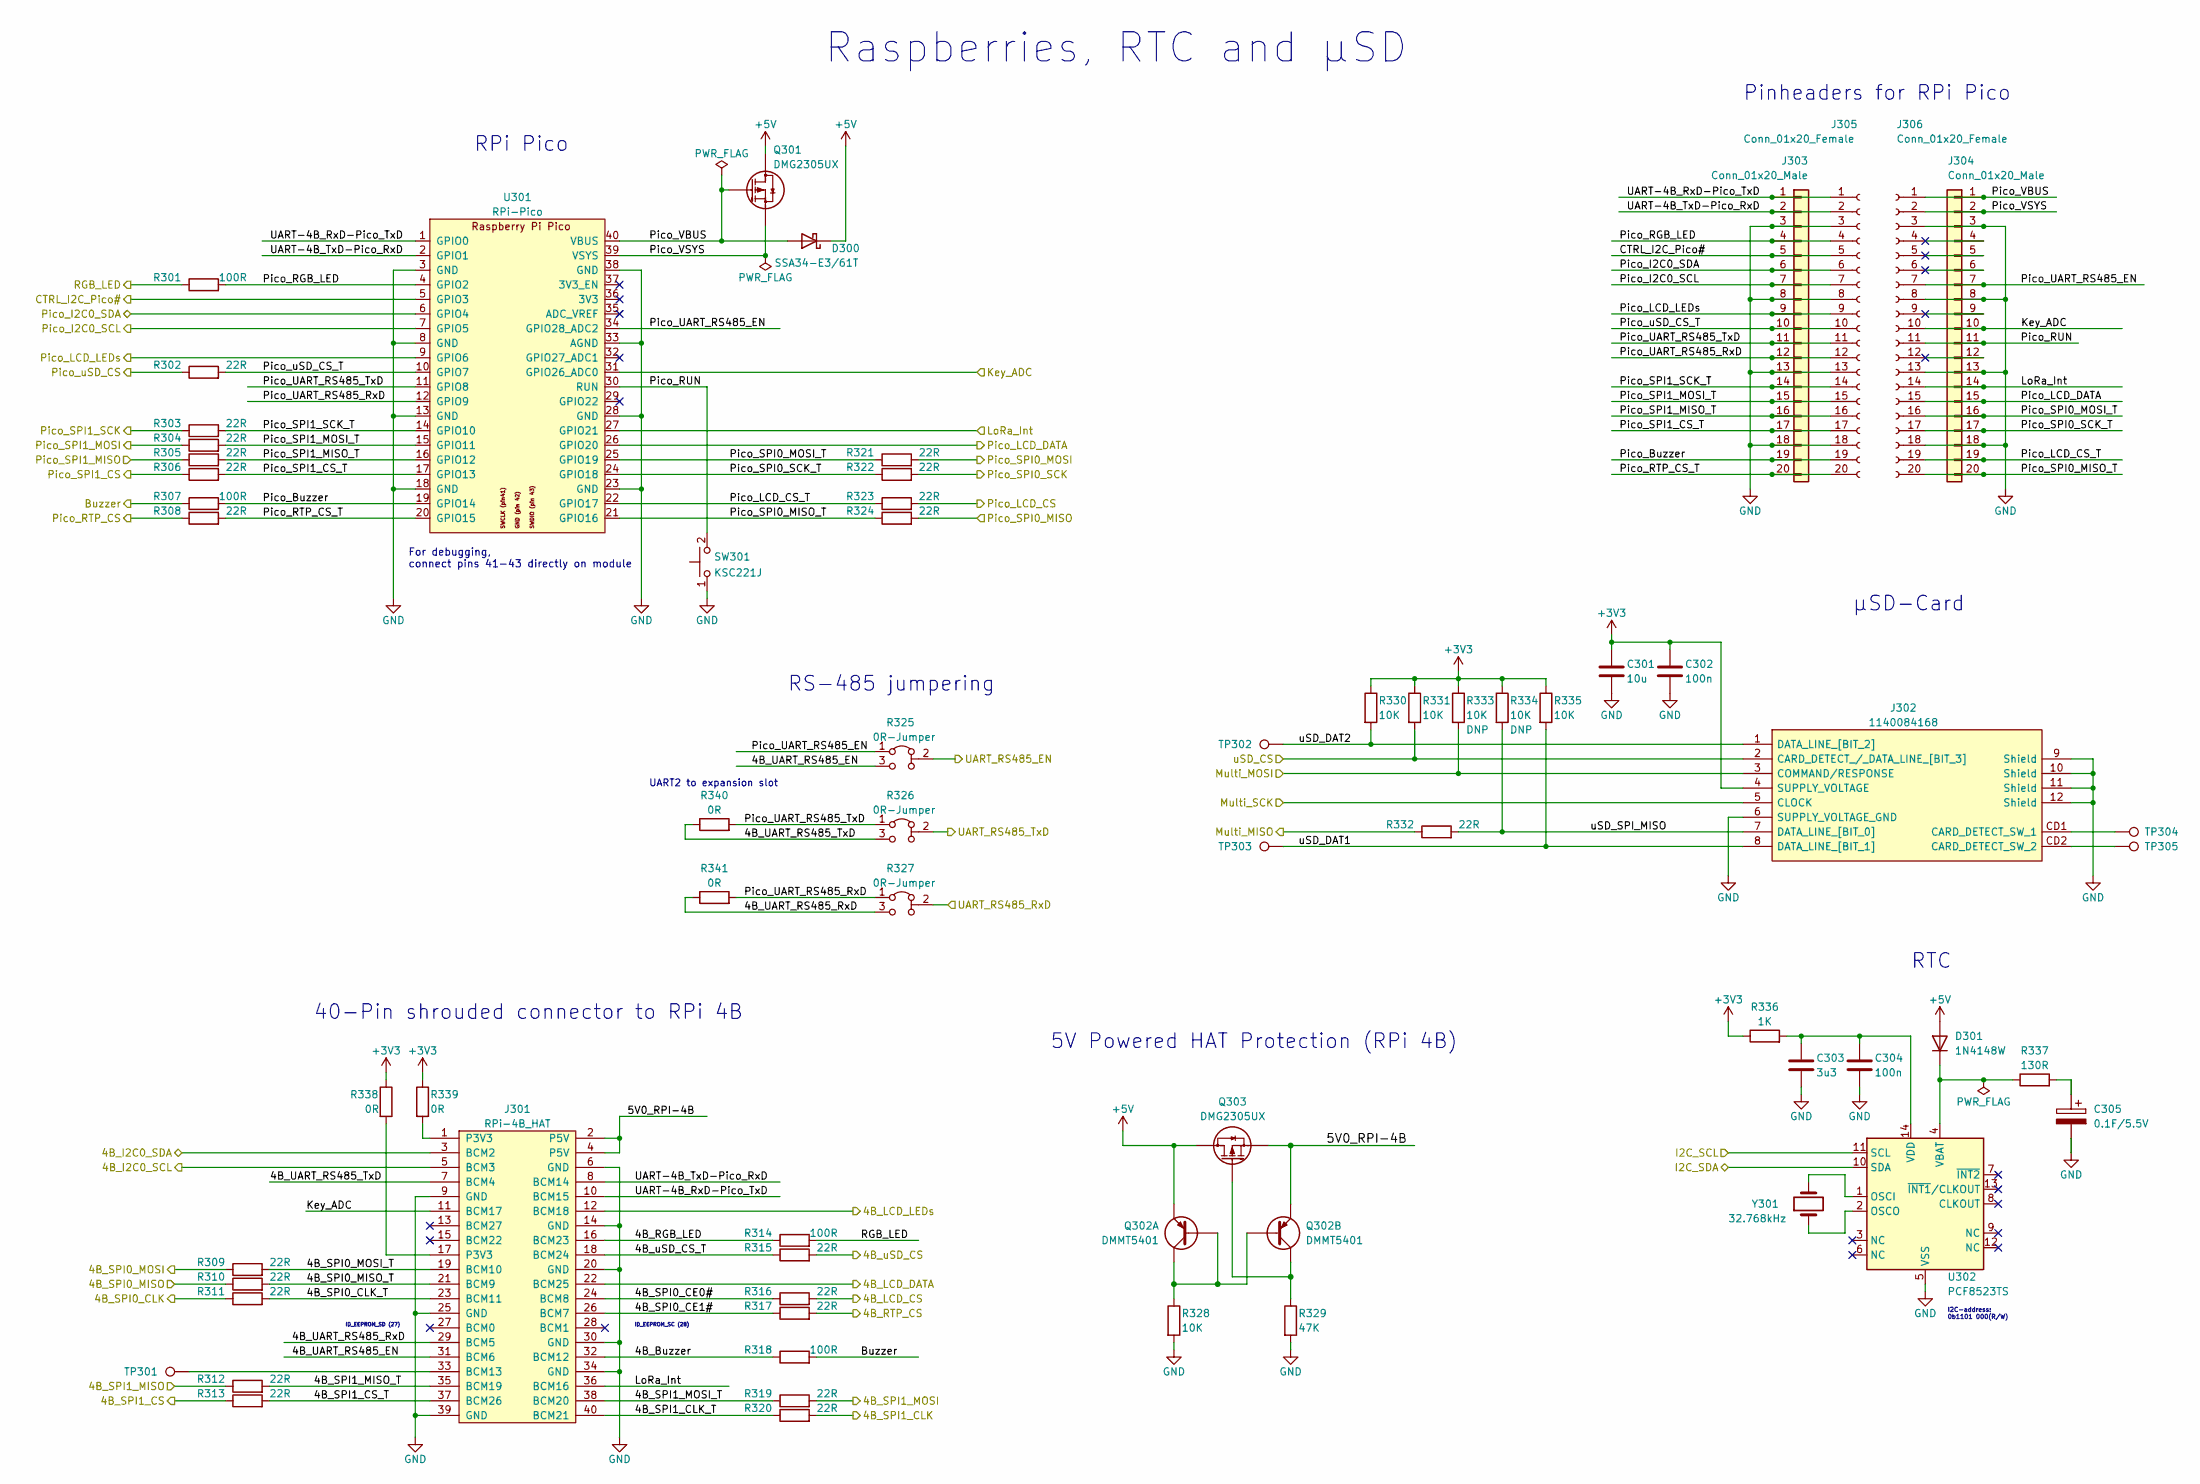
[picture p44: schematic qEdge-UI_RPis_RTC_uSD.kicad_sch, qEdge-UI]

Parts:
C301: 10u; C_0603_1608Metric
C302, C304: 100n; C_0603_1608Metric
C303: 3u3; C_0603_1608Metric
C305: 0.1F/5.5V; Elna_DX5R5H104U; Manufacturer_Part_Number DX-5R5H104U
D300: SSA34-E3/61T; D_SMA; Manufacturer_Part_Number SSA34-E3/61T
D301: 1N4148W; D_SOD-123; Manufacturer_Part_Number 1N4148W-E3
J301: RPi-4B_HAT; Wuerth_WR-BHD_61234020621; Manufacturer_Part_Number 61234020621
J302: 1140084168; Amphenol_1140084168; Manufacturer_Part_Number 1140084168
J303, J304: Conn_01x20_Male; PinHeader_1x20_P2.54mm_Vertical; Manufacturer_Part_Number MC34739
J305, J306: Conn_01x20_Female; PinSocket_1x20_P2.54mm_Vertical; Manufacturer_Part_Number 2212S-20SG-85
Q301, Q303: DMG2305UX; SOT-23; Manufacturer_Part_Number DMG2305UX-13
Q302: DMMT5401; SOT-23-6; Manufacturer_Part_Number DMMT5401-7-F
R301, R307, R314, R318: 100R; R_0603_1608Metric
R302, R303, R304, R305, R306, R308, R309, R310, R311, R312, R313, R315, R316, R317, R319, R320, R321, R322, R323, R324, R332: 22R; R_0603_1608Metric
R325, R326, R327: 0R-Jumper; 0603_3-pin-Jumper; Manufacturer_Part_Number RC0603FR-070RL
R328, R330, R331, R333, R334, R335: 10K; R_0603_1608Metric
R329: 47K; R_0603_1608Metric
R336: 1K; R_0603_1608Metric
R337: 130R; R_0603_1608Metric
R338, R339, R340, R341: 0R; R_0603_1608Metric
SW301: KSC221J; SW_Push_1P1T_NO_CK_KSC6xxJ; Manufacturer_Part_Number KSC221JLFS
TP301, TP302, TP303, TP304, TP305: TestPoint; TestPoint_Pad_D1.0mm
U301: RPi-Pico; RPi-Pico_THT_wo_Debug; Manufacturer_Part_Number Pico W
U302: PCF8523TS; TSSOP-14_4.4x5mm_P0.65mm
Y301: 32.768kHz; MicroCrystal_CM7V32768TBQA020; Manufacturer_Part_Number CM7V-T1A-Low-ESR-32.768k-7pF-10-TB-QA

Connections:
+3V3: C301.1, C302.1, J302.4 (SUPPLY_VOLTAGE), R330.1, R331.1, R333.1, R334.1, R335.1, R336.1, R338.1, R339.1; also elsewhere on the board
+5V: D300.1 (K), D301.2 (A), Q301.3 (D), Q302.6 (E), Q303.3 (D); also elsewhere on the board
/Comm. ifaces, Misc/4B_I2C0_SCL: J301.5 (BCM3); also elsewhere on the board
/Comm. ifaces, Misc/4B_I2C0_SDA: J301.3 (BCM2); also elsewhere on the board
/Comm. ifaces, Misc/4B_LCD_CS: R316.2; also elsewhere on the board
/Comm. ifaces, Misc/4B_LCD_DATA: J301.22 (BCM25); also elsewhere on the board
/Comm. ifaces, Misc/4B_LCD_LEDs: J301.12 (BCM18); also elsewhere on the board
/Comm. ifaces, Misc/4B_RTP_CS: R317.2; also elsewhere on the board
/Comm. ifaces, Misc/4B_SPI0_MISO: R310.1; also elsewhere on the board
/Comm. ifaces, Misc/4B_SPI0_MOSI: R309.1; also elsewhere on the board
/Comm. ifaces, Misc/4B_SPI0_SCK: R311.1; also elsewhere on the board
/Comm. ifaces, Misc/4B_SPI1_CS: R313.1; also elsewhere on the board
/Comm. ifaces, Misc/4B_SPI1_MISO: R312.1; also elsewhere on the board
/Comm. ifaces, Misc/4B_SPI1_MOSI: R319.2; also elsewhere on the board
/Comm. ifaces, Misc/4B_SPI1_SCK: R320.2; also elsewhere on the board
/Comm. ifaces, Misc/4B_uSD_CS: R315.2; also elsewhere on the board
/Comm. ifaces, Misc/I2C_SCL: U302.11 (SCL); also elsewhere on the board
/Comm. ifaces, Misc/I2C_SDA: U302.10 (SDA); also elsewhere on the board
/Comm. ifaces, Misc/Multi_MISO: R332.1; also elsewhere on the board
/Comm. ifaces, Misc/Multi_MOSI: J302.3 (COMMAND/RESPONSE), R333.2; also elsewhere on the board
/Comm. ifaces, Misc/Multi_SCK: J302.5 (CLOCK); also elsewhere on the board
/Comm. ifaces, Misc/Pico_LCD_CS: R323.2; also elsewhere on the board
/Comm. ifaces, Misc/Pico_RTP_CS: R308.1; also elsewhere on the board
/Comm. ifaces, Misc/Pico_SPI0_MISO: R324.2; also elsewhere on the board
/Comm. ifaces, Misc/Pico_SPI0_MOSI: R321.2; also elsewhere on the board
/Comm. ifaces, Misc/Pico_SPI0_SCK: R322.2; also elsewhere on the board
/Comm. ifaces, Misc/Pico_SPI1_CS: R306.1; also elsewhere on the board
/Comm. ifaces, Misc/Pico_SPI1_MISO: R305.1; also elsewhere on the board
/Comm. ifaces, Misc/Pico_SPI1_MOSI: R304.1; also elsewhere on the board
/Comm. ifaces, Misc/Pico_SPI1_SCK: R303.1; also elsewhere on the board
/Comm. ifaces, Misc/Pico_uSD_CS: R302.1; also elsewhere on the board
/Comm. ifaces, Misc/UART_RS485_EN: R325.2 (B); also elsewhere on the board
/Comm. ifaces, Misc/UART_RS485_RxD: R327.2 (B); also elsewhere on the board
/Comm. ifaces, Misc/UART_RS485_TxD: R326.2 (B); also elsewhere on the board
/Comm. ifaces, Misc/uSD_CS: J302.2 (CARD_DETECT_/_DATA_LINE_[BIT_3]), R331.2; also elsewhere on the board
/RPis, RTC, µSD/4B_Buzzer: J301.32 (BCM12), R318.1
/RPis, RTC, µSD/4B_RGB_LED: J301.16 (BCM23), R314.1
/RPis, RTC, µSD/4B_SPI0_CE0#: J301.24 (BCM8), R316.1
/RPis, RTC, µSD/4B_SPI0_CE1#: J301.26 (BCM7), R317.1
/RPis, RTC, µSD/4B_SPI0_CLK_T: J301.23 (BCM11), R311.2
/RPis, RTC, µSD/4B_SPI0_MISO_T: J301.21 (BCM9), R310.2
/RPis, RTC, µSD/4B_SPI0_MOSI_T: J301.19 (BCM10), R309.2
/RPis, RTC, µSD/4B_SPI1_CLK_T: J301.40 (BCM21), R320.1
/RPis, RTC, µSD/4B_SPI1_CS_T: J301.37 (BCM26), R313.2
/RPis, RTC, µSD/4B_SPI1_MISO_T: J301.35 (BCM19), R312.2
/RPis, RTC, µSD/4B_SPI1_MOSI_T: J301.38 (BCM20), R319.1
/RPis, RTC, µSD/4B_UART_RS485_EN: J301.31 (BCM6), R325.3 (C)
/RPis, RTC, µSD/4B_UART_RS485_RxD: J301.29 (BCM5), R327.3 (C), R341.1
/RPis, RTC, µSD/4B_UART_RS485_TxD: J301.7 (BCM4), R326.3 (C), R340.1
/RPis, RTC, µSD/4B_uSD_CS_T: J301.18 (BCM24), R315.1
/RPis, RTC, µSD/5V0_RPI-4B: J301.2 (P5V), J301.4 (P5V), Q302.5 (E), Q303.2 (S)
/RPis, RTC, µSD/Buzzer: R307.1, R318.2; also elsewhere on the board
/RPis, RTC, µSD/CTRL_I2C_Pico#: J303.5, J305.5, U301.5 (GPIO3); also elsewhere on the board
/RPis, RTC, µSD/Key_ADC: J301.11 (BCM17), J304.10, J306.10, U301.31 (GPIO26_ADC0); also elsewhere on the board
/RPis, RTC, µSD/LoRa_Int: J301.36 (BCM16), J304.14, J306.14, U301.27 (GPIO21); also elsewhere on the board
/RPis, RTC, µSD/Pico_Buzzer: J303.19, J305.19, R307.2, U301.19 (GPIO14)
/RPis, RTC, µSD/Pico_I2C0_SCL: J303.7, J305.7, U301.7 (GPIO5); also elsewhere on the board
/RPis, RTC, µSD/Pico_I2C0_SDA: J303.6, J305.6, U301.6 (GPIO4); also elsewhere on the board
/RPis, RTC, µSD/Pico_LCD_CS_T: J304.19, J306.19, R323.1, U301.22 (GPIO17)
/RPis, RTC, µSD/Pico_LCD_DATA: J304.15, J306.15, U301.26 (GPIO20); also elsewhere on the board
/RPis, RTC, µSD/Pico_LCD_LEDs: J303.9, J305.9, U301.9 (GPIO6); also elsewhere on the board
/RPis, RTC, µSD/Pico_RGB_LED: J303.4, J305.4, R301.2, U301.4 (GPIO2)
/RPis, RTC, µSD/Pico_RTP_CS_T: J303.20, J305.20, R308.2, U301.20 (GPIO15)
/RPis, RTC, µSD/Pico_RUN: J304.11, J306.11, SW301.2, U301.30 (RUN)
/RPis, RTC, µSD/Pico_SPI0_MISO_T: J304.20, J306.20, R324.1, U301.21 (GPIO16)
/RPis, RTC, µSD/Pico_SPI0_MOSI_T: J304.16, J306.16, R321.1, U301.25 (GPIO19)
/RPis, RTC, µSD/Pico_SPI0_SCK_T: J304.17, J306.17, R322.1, U301.24 (GPIO18)
/RPis, RTC, µSD/Pico_SPI1_CS_T: J303.17, J305.17, R306.2, U301.17 (GPIO13)
/RPis, RTC, µSD/Pico_SPI1_MISO_T: J303.16, J305.16, R305.2, U301.16 (GPIO12)
/RPis, RTC, µSD/Pico_SPI1_MOSI_T: J303.15, J305.15, R304.2, U301.15 (GPIO11)
/RPis, RTC, µSD/Pico_SPI1_SCK_T: J303.14, J305.14, R303.2, U301.14 (GPIO10)
/RPis, RTC, µSD/Pico_UART_RS485_EN: J304.7, J306.7, R325.1 (A), U301.34 (GPIO28_ADC2)
/RPis, RTC, µSD/Pico_UART_RS485_RxD: J303.12, J305.12, R327.1 (A), R341.2, U301.12 (GPIO9)
/RPis, RTC, µSD/Pico_UART_RS485_TxD: J303.11, J305.11, R326.1 (A), R340.2, U301.11 (GPIO8)
/RPis, RTC, µSD/Pico_VBUS: D300.2 (A), J304.1, J306.1, Q301.1 (G), U301.40 (VBUS)
/RPis, RTC, µSD/Pico_VSYS: J304.2, J306.2, Q301.2 (S), U301.39 (VSYS)
/RPis, RTC, µSD/Pico_uSD_CS_T: J303.10, J305.10, R302.2, U301.10 (GPIO7)
/RPis, RTC, µSD/RGB_LED: R301.1, R314.2; also elsewhere on the board
/RPis, RTC, µSD/UART-4B_RxD-Pico_TxD: J301.10 (BCM15), J303.1, J305.1, U301.1 (GPIO0)
/RPis, RTC, µSD/UART-4B_TxD-Pico_RxD: J301.8 (BCM14), J303.2, J305.2, U301.2 (GPIO1)
/RPis, RTC, µSD/uSD_DAT1: J302.8 (DATA_LINE_[BIT_1]), R335.2, TP303.1
/RPis, RTC, µSD/uSD_DAT2: J302.1 (DATA_LINE_[BIT_2]), R330.2, TP302.1
/RPis, RTC, µSD/uSD_SPI_MISO: J302.7 (DATA_LINE_[BIT_0]), R332.2, R334.2
GND: C301.2, C302.2, C303.2, C304.2, C305.1, J301.6 (GND), J301.9 (GND), J301.14 (GND), J301.20 (GND), J301.25 (GND), J301.30 (GND), J301.34 (GND), J301.39 (GND), J302.6 (SUPPLY_VOLTAGE_GND), J302.9 (Shield), J302.10 (Shield), J302.11 (Shield), J302.12 (Shield), J303.3, J303.8, J303.13, J303.18, J304.3, J304.8, J304.13, J304.18, J305.3, J305.8, J305.13, J305.18, J306.3, J306.8, J306.13, J306.18, R328.2, R329.2, SW301.1, U301.3 (GND), U301.8 (GND), U301.13 (GND), U301.18 (GND), U301.23 (GND), U301.28 (GND), U301.33 (AGND), U301.38 (GND), U302.5 (VSS); also elsewhere on the board
unnamed: C303.1, C304.1, R336.2, U302.14 (VDD)
unnamed: C305.2, R337.2
unnamed: D301.1 (K), R337.1, U302.4 (VBAT)
unnamed: J301.1 (P3V3), R339.2
unnamed: J301.17 (P3V3), R338.2
unnamed: J301.33 (BCM13), TP301.1
unnamed: J302.CD1 (CARD_DETECT_SW_1), TP304.1
unnamed: J302.CD2 (CARD_DETECT_SW_2), TP305.1
unnamed: Q302.1 (C), Q302.2 (B), Q302.3 (B), R328.1
unnamed: Q302.4 (C), Q303.1 (G), R329.1
unnamed: U302.1 (OSCI), Y301.2
unnamed: U302.2 (OSCO), Y301.1

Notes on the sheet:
Pinheaders for RPi Pico
ID_EEPROM_SC (28)
RS-485 jumpering
For debugging, connect pins 41-43 directly on module
µSD-Card
ID_EEPROM_SD (27)
RTC
RPi Pico
5V Powered HAT Protection (RPi 4B)
I2C-address: 0b1101 000(R/W)
UART2 to expansion slot
40-Pin shrouded connector to RPi 4B
Raspberries, RTC and µSD

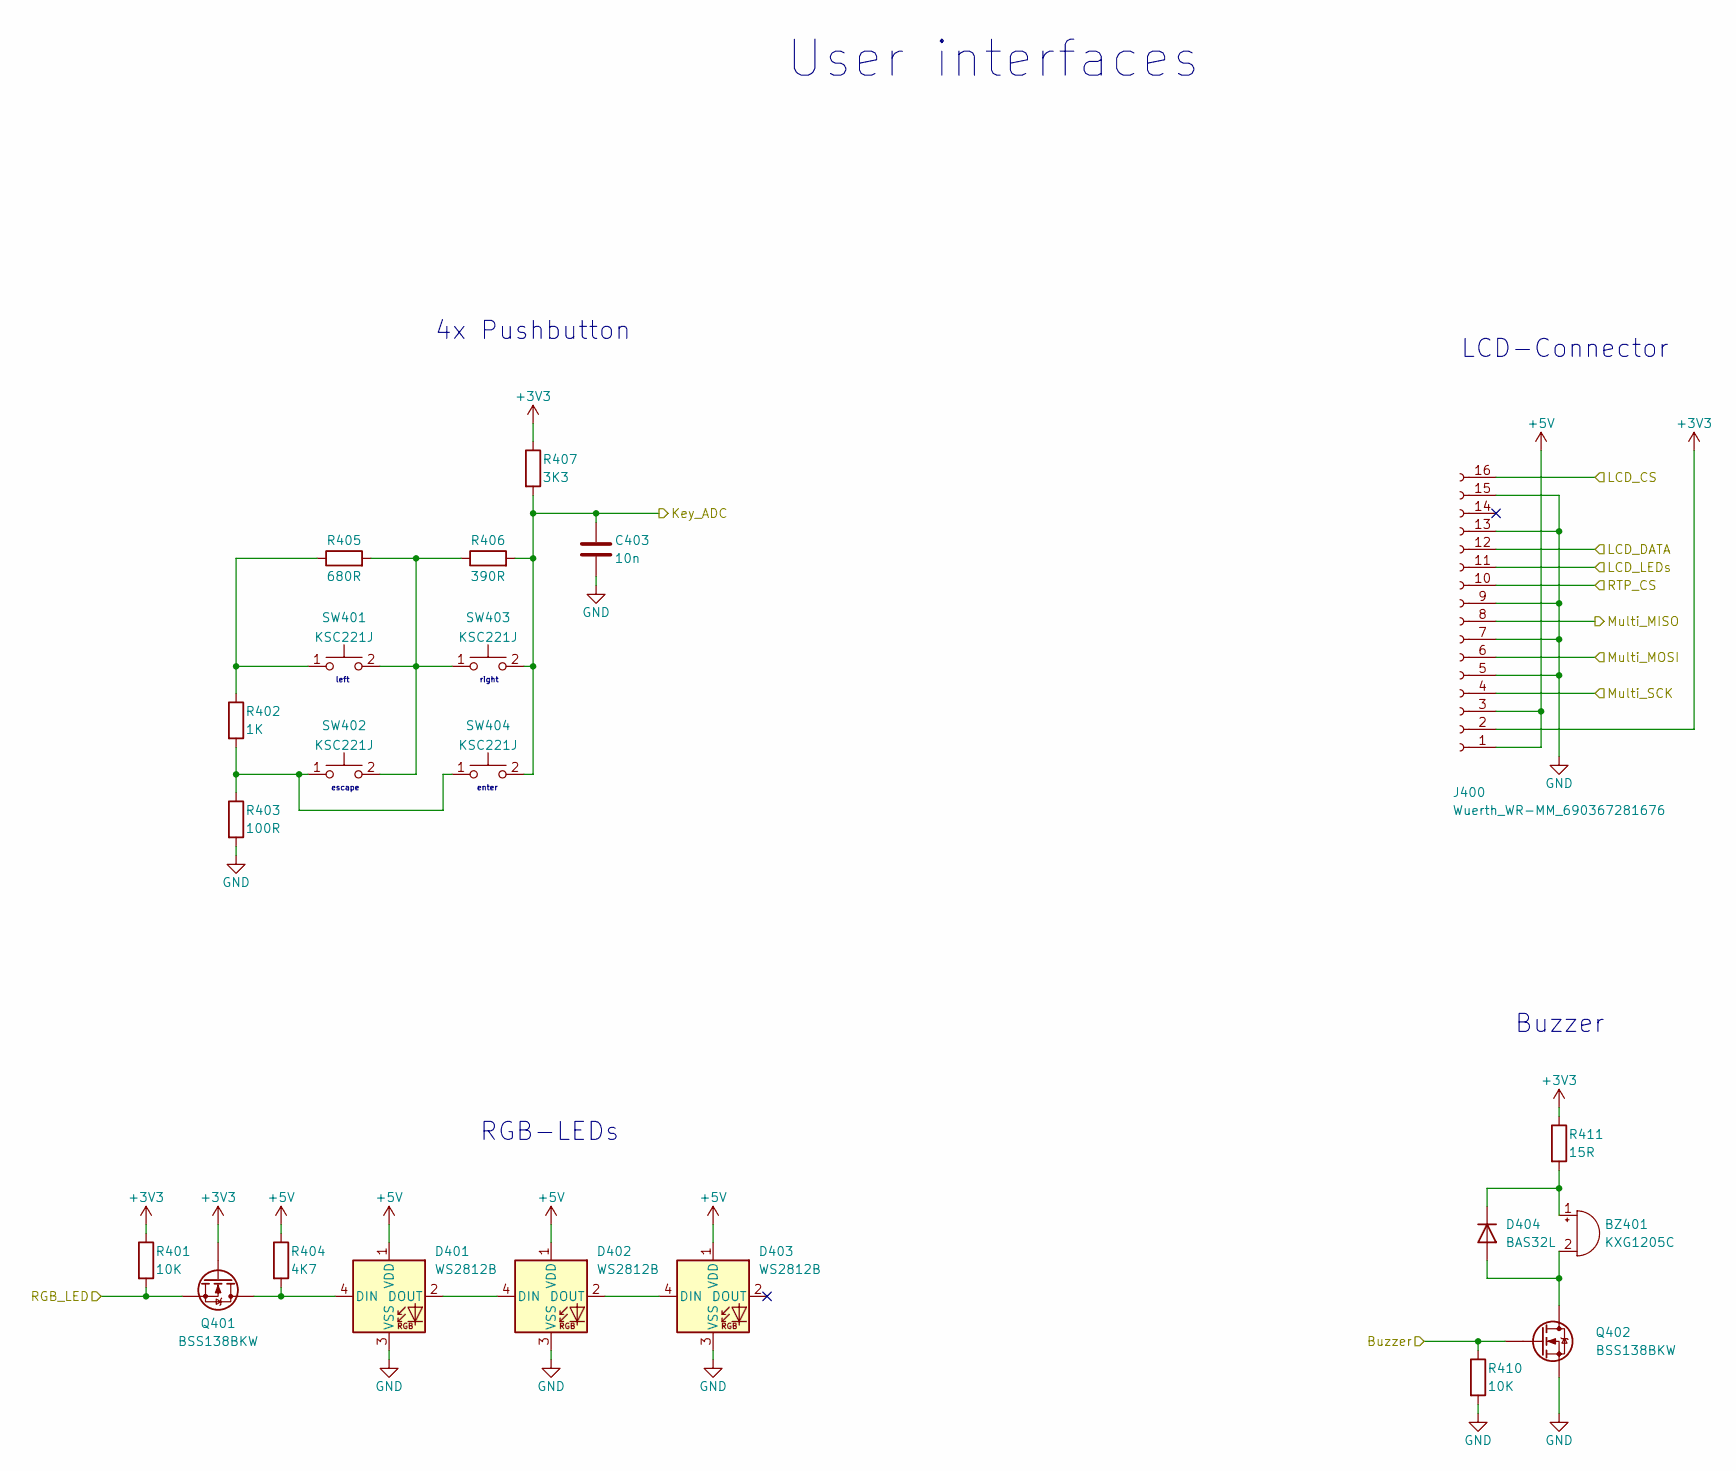
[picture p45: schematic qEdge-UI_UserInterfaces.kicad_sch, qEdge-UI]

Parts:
BZ401: KXG1205C; Buzzer_12x9.5RM7.6; Manufacturer_Part_Number KXG1205C
C403: 10n; C_0603_1608Metric
D401, D402, D403: WS2812B; LED_WS2812B_PLCC4_5.0x5.0mm_P3.2mm; Manufacturer_Part_Number WS2812B
D404: BAS32L; D_MiniMELF; Manufacturer_Part_Number BAS32L,115
J400: Wuerth_WR-MM_690367281676; Manufacturer_Part_Number 690367281676
Q401, Q402: BSS138BKW; SOT-323_SC-70; Manufacturer_Part_Number BSS138BKW,115
R401, R410: 10K; R_0603_1608Metric
R402: 1K; R_0603_1608Metric
R403: 100R; R_0603_1608Metric
R404: 4K7; R_0603_1608Metric
R405: 680R; R_0603_1608Metric
R406: 390R; R_0603_1608Metric
R407: 3K3; R_0603_1608Metric
R411: 15R; R_0805_2012Metric
SW401, SW402, SW403, SW404: KSC221J; SW_Push_1P1T_NO_CK_KSC6xxJ; Manufacturer_Part_Number KSC221JLFS

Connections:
+3V3: J400.2, Q401.1 (G), R401.1, R407.1, R411.1; also elsewhere on the board
+5V: D401.1 (VDD), D402.1 (VDD), D403.1 (VDD), J400.1, J400.3, R404.1; also elsewhere on the board
/Comm. ifaces, Misc/LCD_CS: J400.16; also elsewhere on the board
/Comm. ifaces, Misc/LCD_DATA: J400.12; also elsewhere on the board
/Comm. ifaces, Misc/LCD_LEDs: J400.11; also elsewhere on the board
/Comm. ifaces, Misc/Multi_MISO: J400.8; also elsewhere on the board
/Comm. ifaces, Misc/Multi_MOSI: J400.6; also elsewhere on the board
/Comm. ifaces, Misc/Multi_SCK: J400.4; also elsewhere on the board
/Comm. ifaces, Misc/RTP_CS: J400.10; also elsewhere on the board
/RPis, RTC, µSD/Buzzer: Q402.1 (G), R410.1; also elsewhere on the board
/RPis, RTC, µSD/Key_ADC: C403.1, R406.2, R407.2, SW403.2, SW404.2; also elsewhere on the board
/RPis, RTC, µSD/RGB_LED: Q401.2 (S), R401.2; also elsewhere on the board
GND: C403.2, D401.3 (VSS), D402.3 (VSS), D403.3 (VSS), J400.5, J400.7, J400.9, J400.13, J400.15, Q402.2 (S), R403.2, R410.2; also elsewhere on the board
unnamed: BZ401.1 (-), D404.1 (K), R411.2
unnamed: BZ401.2 (+), D404.2 (A), Q402.3 (D)
unnamed: D401.2 (DOUT), D402.4 (DIN)
unnamed: D401.4 (DIN), Q401.3 (D), R404.2
unnamed: D402.2 (DOUT), D403.4 (DIN)
unnamed: R402.1, R405.1, SW401.1
unnamed: R402.2, R403.1, SW402.1, SW404.1
unnamed: R405.2, R406.1, SW401.2, SW402.2, SW403.1

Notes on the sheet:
right
left
escape
Buzzer
User interfaces
LCD-Connector
4x Pushbutton
enter
RGB-LEDs

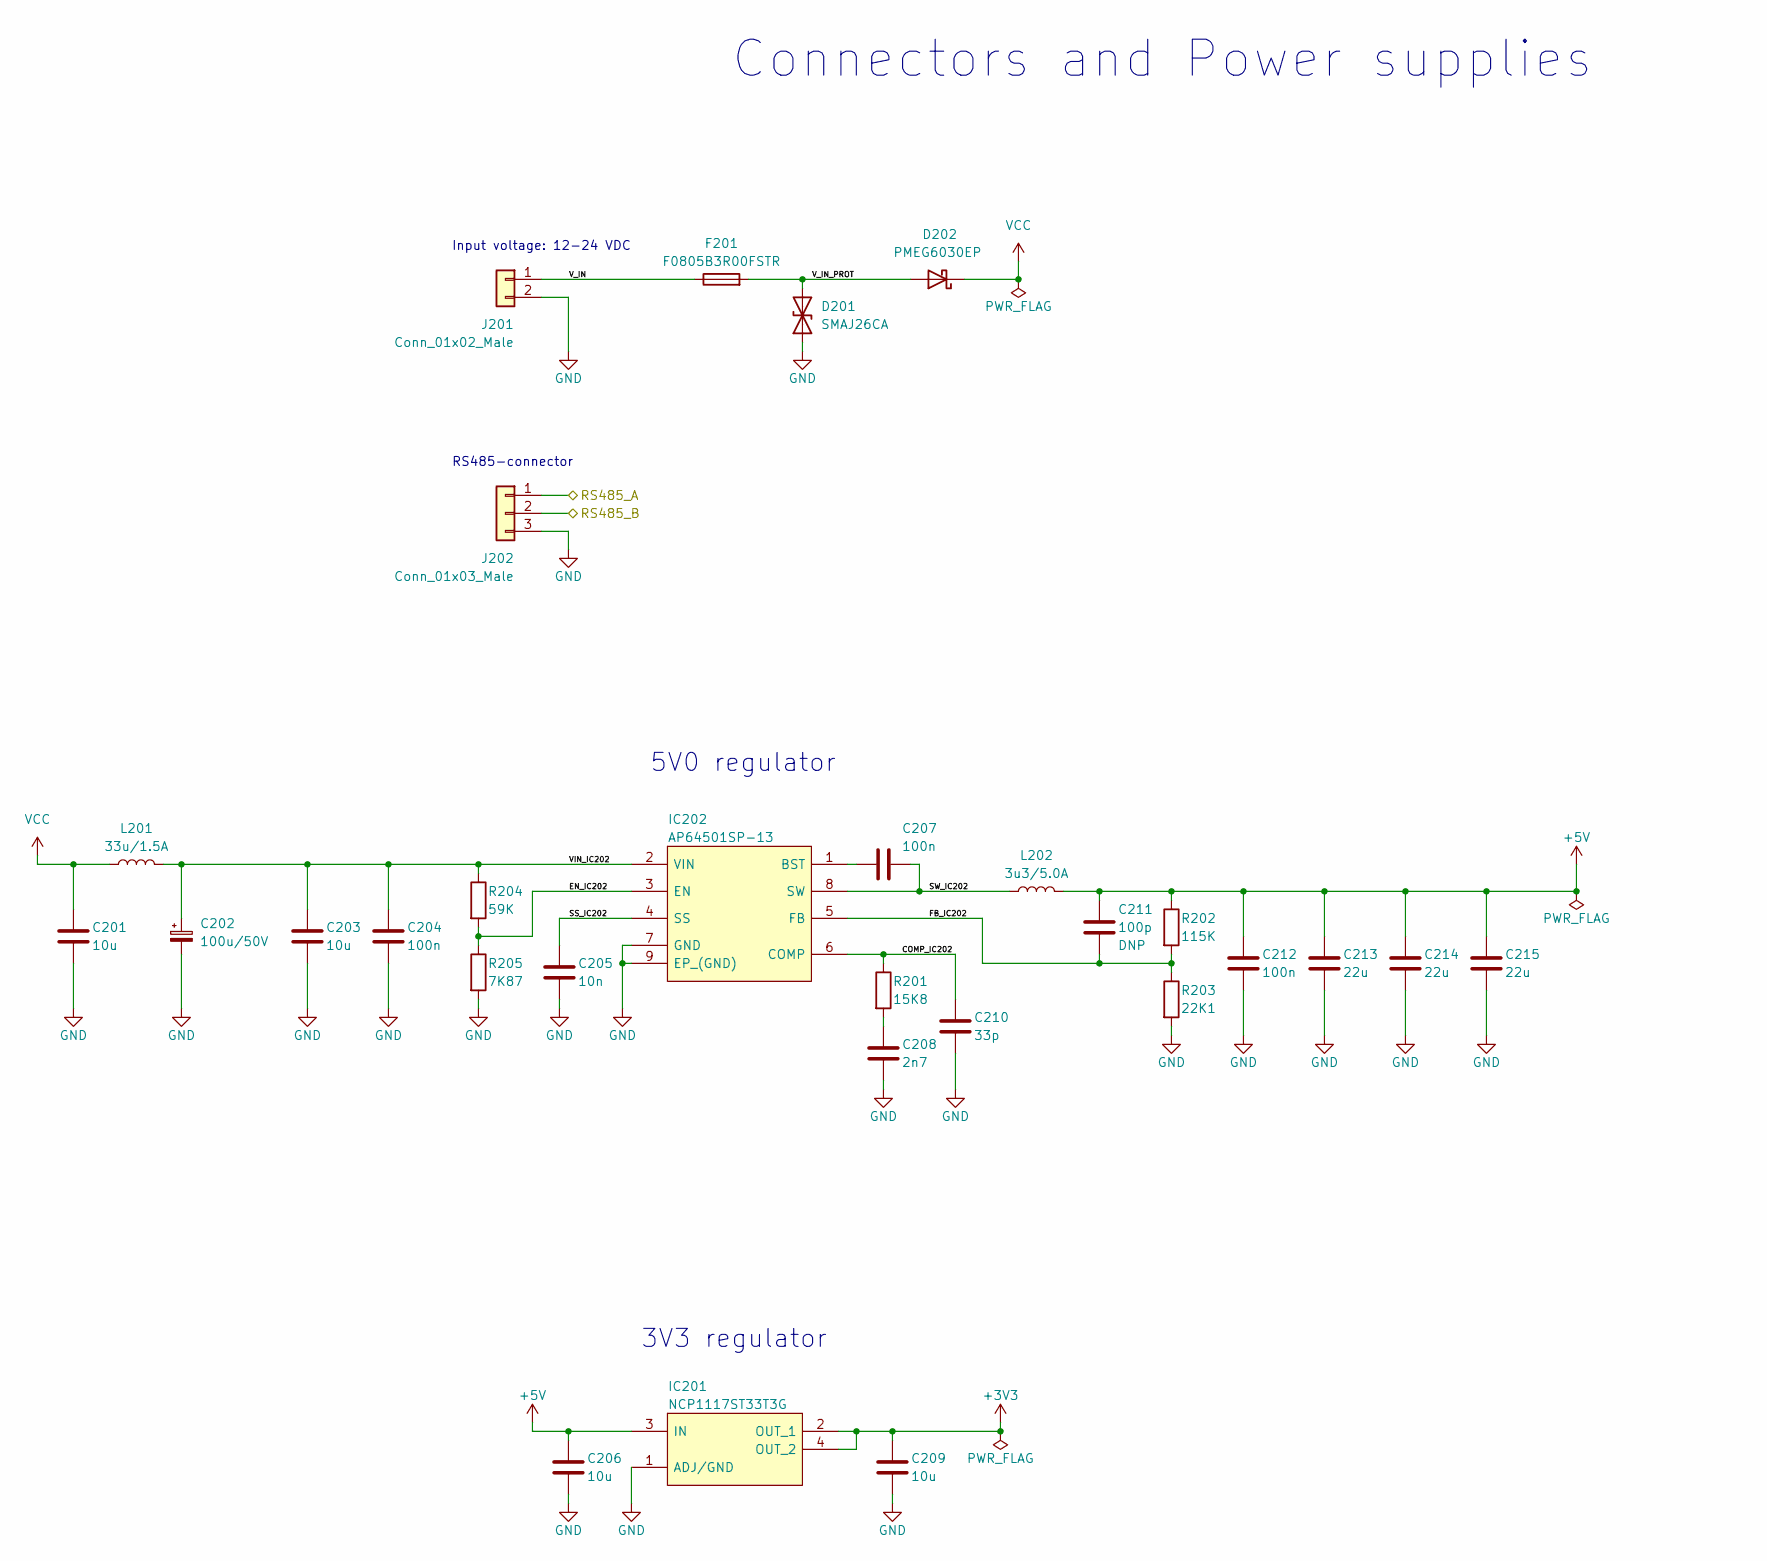
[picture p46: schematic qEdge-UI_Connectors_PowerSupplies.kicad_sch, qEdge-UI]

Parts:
C201, C203: 10u; C_0805_2012Metric
C202: 100u/50V; CP_Elec_8x10.5; Manufacturer_Part_Number 865080653016
C204, C207, C212: 100n; C_0603_1608Metric
C205: 10n; C_0603_1608Metric
C206, C209: 10u; C_0603_1608Metric
C208: 2n7; C_0603_1608Metric
C210: 33p; C_0603_1608Metric
C211: 100p; C_0603_1608Metric
C213, C214, C215: 22u; C_0805_2012Metric
D201: SMAJ26CA; D_SMA_bipolar; Manufacturer_Part_Number SMAJ26CA
D202: PMEG6030EP; D_SOD-128; Manufacturer_Part_Number PMEG6030EP,115
F201: F0805B3R00FSTR; Fuse_0805_2012Metric; Manufacturer_Part_Number F0805B3R00FSTR
IC201: NCP1117ST33T3G; SOT230P700X180-4N; Manufacturer_Part_Number NCP1117ST33T3G
IC202: AP64501SP-13; SOIC127P600X163-9N; Manufacturer_Part_Number AP64501SP-13
J201: Conn_01x02_Male; PhoenixContact_MC_1,5_2-G-3.5_1x02_P3.50mm_Horizontal; Manufacturer_Part_Number MC 1,5/ 2-G-3,5 - 1844210
J202: Conn_01x03_Male; PhoenixContact_MC_1,5_3-G-3.5_1x03_P3.50mm_Horizontal; Manufacturer_Part_Number MC 1,5/ 3-G-3,5 - 1844223
L201: 33u/1.5A; Murata_1255AY100MP3; Manufacturer_Part_Number 1255AY-330M=P3
L202: 3u3/5.0A; Abracon_ASPI0530LR3R3MT2; Manufacturer_Part_Number ASPI-0530LR-3R3M-T2
R201: 15K8; R_0603_1608Metric
R202: 115K; R_0603_1608Metric
R203: 22K1; R_0603_1608Metric
R204: 59K; R_0603_1608Metric
R205: 7K87; R_0603_1608Metric

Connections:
+3V3: C209.1, IC201.2 (OUT_1), IC201.4 (OUT_2); also elsewhere on the board
+5V: C206.1, C211.1, C212.1, C213.1, C214.1, C215.1, IC201.3 (IN), L202.2, R202.1; also elsewhere on the board
/Comm. ifaces, Misc/RS485_A: J202.1; also elsewhere on the board
/Comm. ifaces, Misc/RS485_B: J202.2; also elsewhere on the board
/Connectors, Power supplies/COMP_IC202: C210.1, IC202.6 (COMP), R201.1
/Connectors, Power supplies/EN_IC202: IC202.3 (EN), R204.2, R205.1
/Connectors, Power supplies/FB_IC202: C211.2, IC202.5 (FB), R202.2, R203.1
/Connectors, Power supplies/SS_IC202: C205.1, IC202.4 (SS)
/Connectors, Power supplies/SW_IC202: C207.1, IC202.8 (SW), L202.1
/Connectors, Power supplies/VIN_IC202: C202.1, C203.1, C204.1, IC202.2 (VIN), L201.2, R204.1
/Connectors, Power supplies/V_IN: F201.1, J201.1
/Connectors, Power supplies/V_IN_PROT: D201.2 (A2), D202.2 (A), F201.2
GND: C201.2, C202.2, C203.2, C204.2, C205.2, C206.2, C208.2, C209.2, C210.2, C212.2, C213.2, C214.2, C215.2, D201.1 (A1), IC201.1 (ADJ/GND), IC202.7 (GND), IC202.9 (EP_(GND)), J201.2, J202.3, R203.2, R205.2; also elsewhere on the board
unnamed: C207.2, IC202.1 (BST)
unnamed: C208.1, R201.2
VCC: C201.1, D202.1 (K), L201.1

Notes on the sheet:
RS485-connector
Connectors and Power supplies
3V3 regulator
5V0 regulator
Input voltage: 12-24 VDC

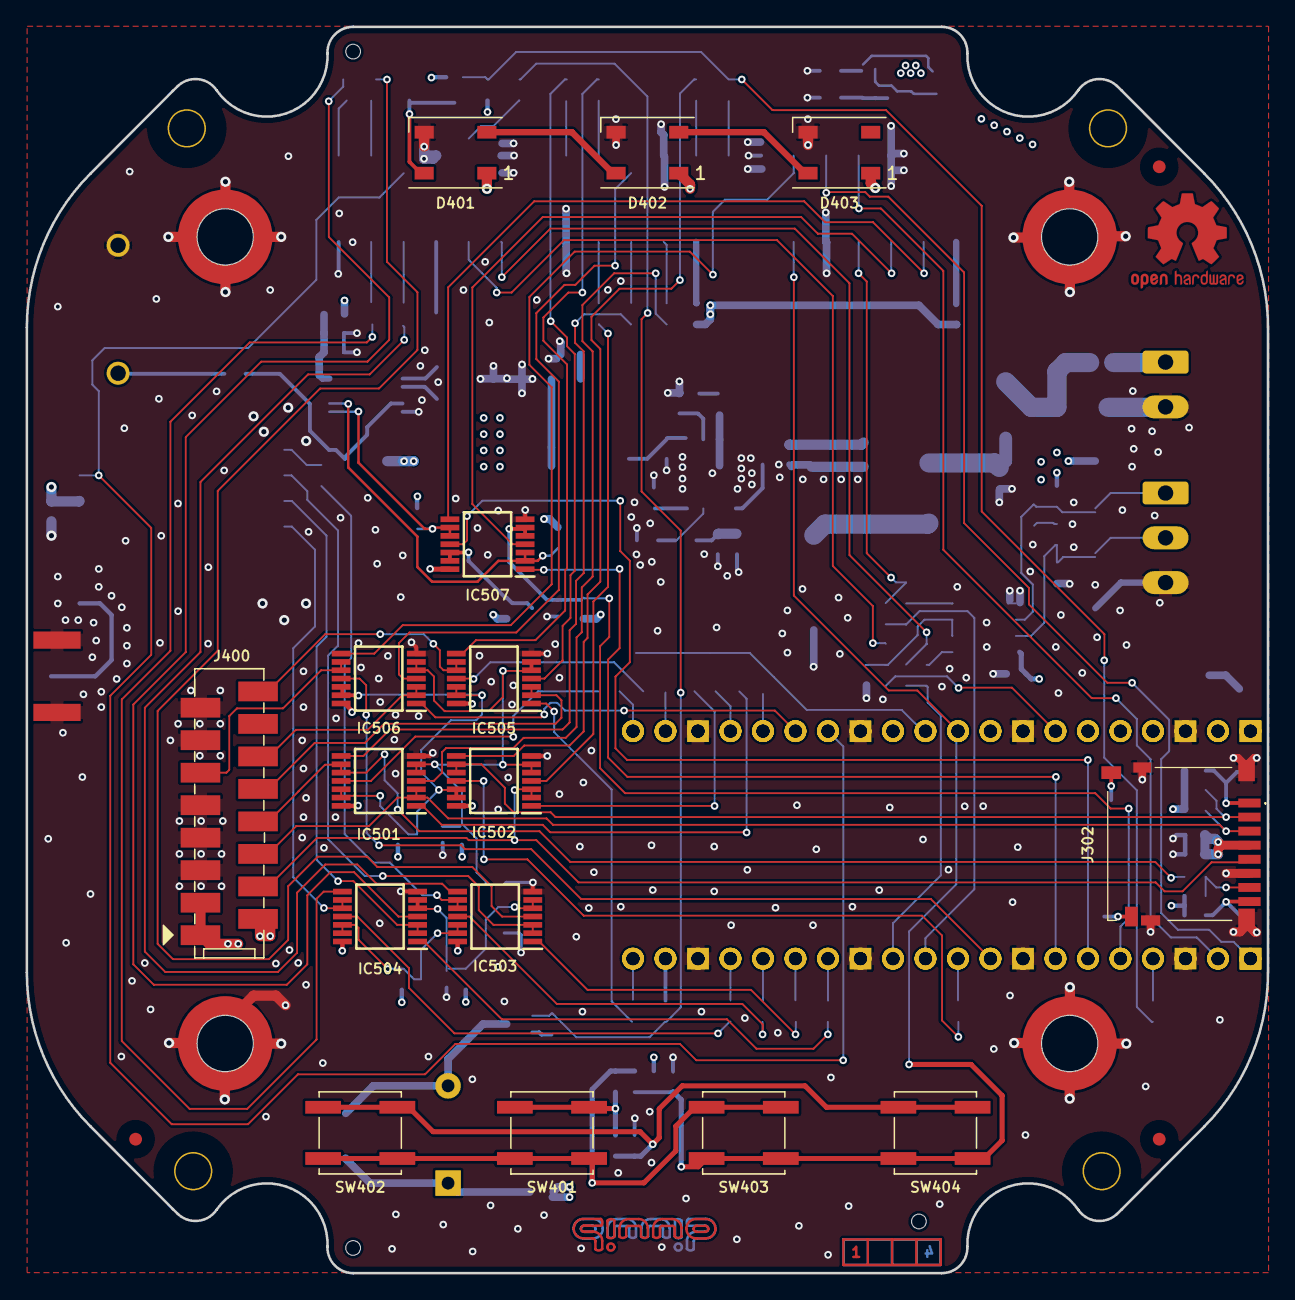
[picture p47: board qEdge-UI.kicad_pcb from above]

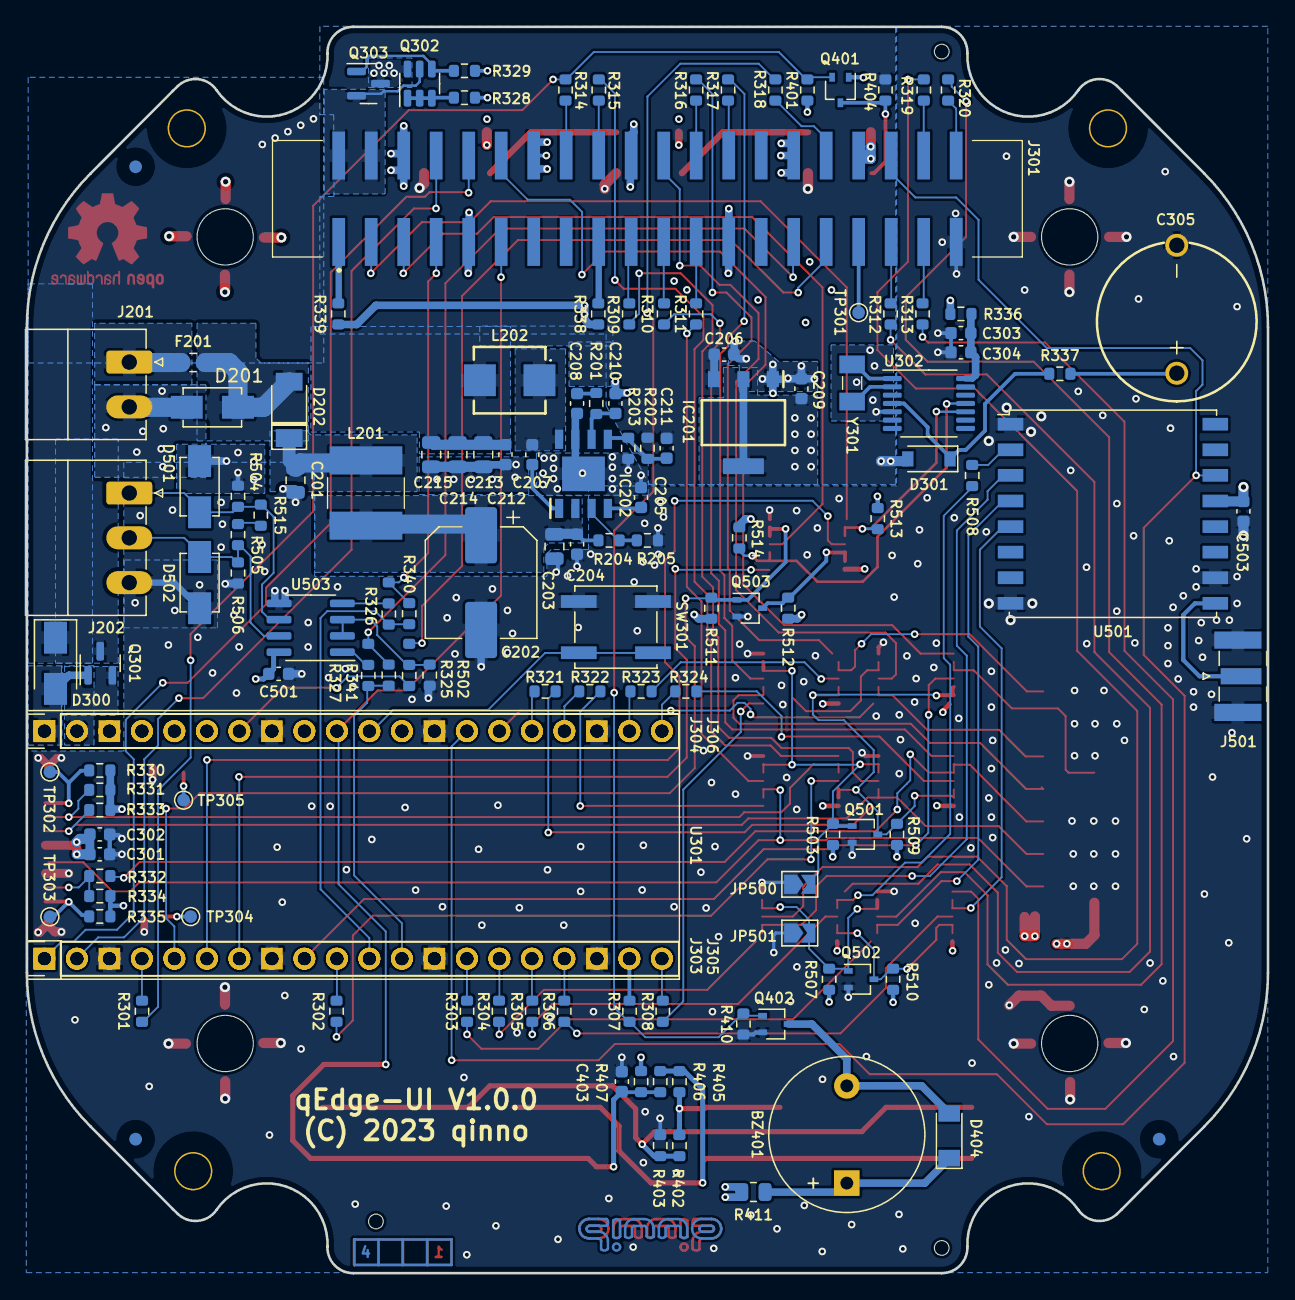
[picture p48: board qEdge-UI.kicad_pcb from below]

Board: 4 copper layers, 97.0 x 97.4 mm, 170 parts (138 on the bottom side), 133 nets.

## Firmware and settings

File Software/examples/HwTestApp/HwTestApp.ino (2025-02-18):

/**
  Hardware Test Application for qEdgeUI

  Copyright (c) 2022-2025 Ralf Wolters

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
  You should have received a copy of the GNU General Public
  License along with this library; if not, write to the Free Software
  Foundation, Inc., 51 Franklin St, Fifth Floor, Boston, MA  02110-1301  USA
*/

/*
  Settings: PICO W
  --> Tools -> Flash size  -> Sketch: 1MB, FS: 1MB
  --> Tools -> CPU speed   -> 125 MHz
  --> Tools -> Optimize    -> -O3
  --> Tools -> WiFi Region -> - select your country

  Settings: PICO2 W
  --> Tools -> CPU Architecture -> ARM
  --> Tools -> Flash size  -> Sketch: 2MB, FS: 2MB
  --> Tools -> CPU speed   -> 150 MHz
  --> Tools -> Optimize    -> -O3
*/

#include "SmartView.h"
#include "HwTestApp.h"

//Uncomment define for enabling "screenshot functionality" by pressing a button to make and store screenshots to FLASH / SD-card
// #define ENABLE_SCREEN_SHOT_FCT
/**
    init
*/
void setup() {
  sViewInit();
  Dln("Init done");
  qEdgeUiBuzzer();
  Dln("Buzz done");
}

/**
    main loop
*/
void loop() {
  Dln("Starting Hardware Test Application Main Menue");
  HwTestAppMenue();
}

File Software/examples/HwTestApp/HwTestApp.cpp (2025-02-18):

/**
  Hardware Test Application for qEdgeUI - functions

  Copyright (c) 2022-2025 Ralf Wolters

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
  You should have received a copy of the GNU General Public
  License along with this library; if not, write to the Free Software
  Foundation, Inc., 51 Franklin St, Fifth Floor, Boston, MA  02110-1301  USA
*/


#include "SmartView.h"
#include "HwTestApp.h"

/**
 * main menu from PNG
 */
void HwTestAppMenue() {
  const uint8_t XF = 4;
  const uint8_t YF = 3;
  int16_t       field, i;  // touch key fields
  int8_t        key;
  uint8_t       rgbc    = 1;  // RGB led color
  bool          refresh = true;
  uint32_t      rgbTime;   // rgb change timer
  uint32_t      idleTime;  // idle timer

  // menu touch keys
  const uint8_t TTEST       = 0;  // Touch test
  const uint8_t SLIDESHOW   = 1;  // slideshow
  const uint8_t UART        = 2;
  const uint8_t RS485       = 3;
  const uint8_t SDSHOW      = 4;  // SD
  const uint8_t LFSSHOW     = 5;  // LittleFS
  const uint8_t RTC         = 6;
  const uint8_t WIFI        = 7;
  const uint8_t TEMPARATURE = 8;
  const uint8_t INFO        = 9;
  const uint8_t KEYBOARD    = 10;
  const uint8_t SETTING     = 11;

  rgbTime  = millis();
  idleTime = millis();

  while (true) {
    if (refresh) {
      sViewLoadPNG(FROM_LFS, 0, 0, "/HwTestAppMenueScreen.png");  //mmenu.png
      sViewSetFields(XF, YF);
      refresh = false;
    }
    field = HwTestAppEvent();
    switch (field) {
      case TTEST:
        qEdgeUiTouchTest();
        refresh = true;
        break;
      case SLIDESHOW:
        HwTestAppSlideshow(FROM_SD);
        refresh = true;
        break;
      case UART:
        HwTestAppTerminal(1);
        refresh = true;
        break;
      case RS485:
        HwTestAppTerminal(2);
        refresh = true;
        break;
      case SDSHOW:
        HwTestAppFSinfo(FROM_SD);
        refresh = true;
        break;
      case LFSSHOW:
        HwTestAppFSinfo(FROM_LFS);
        refresh = true;
        break;
      case RTC:
        HwTestAppLoRa();
        refresh = true;
        break;
      case WIFI:
        HwTestAppWiFiScan();
        refresh = true;
        break;
      case TEMPARATURE:
        gameSetup();
        gameLoop();
        //HwTestAppTemperature();
        refresh = true;
        break;
      case INFO:
        HwTestAppSysInfo();
        refresh = true;
        break;
      case KEYBOARD:
        HwTestAppKeyboard("qinno ");
        refresh = true;
        break;
      case SETTING:
        HwTestAppSettings();
        refresh = true;
        break;
      // keys
      case HOME:
        HwTestAppIdle();
        refresh = true;
        break;
      case SPECIFIC:
        HwTestAppSettings();
        refresh = true;
        break;
      case SCREENSHOT:
        sViewSetFields(XF, YF);
        refresh = true;
        break;
    }
    if (millis() - rgbTime > RGB_UPDATE_MS) {  // rotate RGBs
      for (i = 0; i < RGB_LED_NO; ++i) sViewRGBset(i, rgbc);
      if (++rgbc == 255) rgbc = 1;  // avoid black and white
      rgbTime = millis();
    }
    if (refresh) idleTime = millis();
    if (millis() - idleTime > IDLE_TIME_MS) {  // switch to idle screen
      HwTestAppIdle();
      idleTime = millis();
      refresh  = true;
    }
#ifdef PICO_LED
    digitalWrite(PICO_LED, !digitalRead(PICO_LED));  // toggle onboard LED
#endif
  }
}

/**
 * Application which runs in "idle" mode and displays qEdge logo, time and date information on the display
 */
void HwTestAppIdle() {
  const uint8_t  XF             = 1;
  const uint8_t  YF             = 10;
  const uint16_t UPDATE_TIME_MS = 997;    // update status display
  const uint16_t RESYNC_TIME_MS = 60000;  // resync to WiFi after lost
  const uint8_t  FONT_7SEG      = 7;
  const uint8_t  FONT_LARGE     = 4;
  const uint8_t  FONT_MEDIUM    = 2;
  time_t         now;
  char           buff[80];
  String         wifiInfo;
  uint32_t       updateTime;  // update refresh timer
  uint32_t       resyncTime;  // resync time to WiFi
  uint8_t        i, rgbc, wifiStat;
  const String   dayOfWeek[] = { "Sun", "Mon", "Tue", "Wed", "Thu", "Fri", "Sat" };
  tm*            timeinfo;

  sViewLoadPNG(FROM_LFS, 0, 0, "/qEdgeIdleScreen.png");
  updateTime = millis();
  resyncTime = millis();
  sViewSetFields(XF, YF);

  while (HwTestAppEvent() == NO_EVENT) {
    if (millis() - updateTime > UPDATE_TIME_MS) {  // update screen
      time(&now);
      timeinfo     = localtime(&now);
      uint8_t wday = timeinfo->tm_wday;
      strftime(buff, sizeof(buff), "%H:%M:%S", localtime(&now));  // show time
      sViewDrawField(0, buff, FIELD_TRANS_7SEG, 4);
      strftime(buff, sizeof(buff), "%d.%m.%Y", localtime(&now));  // show date
      sViewDrawField(4, dayOfWeek[wday] + " " + buff, FIELD_TRANS_BIG, 2);
      wifiStat = WiFi.status();
      switch (wifiStat) {
        case WL_NO_SHIELD:
          wifiInfo = "      no WIFI hardware      ";
          break;
        case WL_NO_SSID_AVAIL:
          wifiInfo = "  no WIFI SSIDs available   ";
          break;
        case WL_CONNECT_FAILED:
          wifiInfo = "    WIFI connect failed     ";
          break;
        case WL_CONNECTION_LOST:
          wifiInfo = "    WIFI connection lost    ";
          break;
        case WL_DISCONNECTED:
          wifiInfo = "     WIFI disconnected      ";
          break;
        case WL_IDLE_STATUS:
          wifiInfo = "         WIFI idle          ";
          break;
        case WL_CONNECTED:  // done, OK
          wifiInfo = WiFi.SSID() + ": " + String(WiFi.RSSI()) + "dBm";
          break;
      }
      if ((wifiStat != WL_CONNECTED) and ((millis() - resyncTime > RESYNC_TIME_MS))) {  // resync WiFi
        wifiInfo = "try to reconnect to WiFi ...";

        //tft.drawString(wifiInfo, tft.width() / 2, 160, FONT_MEDIUM);
        //sViewDrawField(6, wifiInfo, FIELD_DEFAULT, 2);
        sViewDrawField(6, wifiInfo, FIELD_TRANS, 2);

        wifiConnect();
        ntpConnect();
        resyncTime = millis();
      }

      else sViewDrawField(6, wifiInfo, FIELD_TRANS, 2);
      //tft.drawString(wifiInfo, tft.width() / 2, 160, FONT_MEDIUM);

      for (i = 0; i < RGB_LED_NO; ++i) sViewRGBset(i, rgbc);  // rotate RGB
      if (++rgbc == 255) rgbc = 1;                            // avoid black and white
      updateTime = millis();
    }
  }
  wifiConnect();
  //tft.setTextPadding(0);
}
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

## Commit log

2023-08-08 initial commit.
    [config.cfg]
2023-08-08 move Software to subdirectory, fix libraries.
    [config.cfg]
2023-08-08 Add electronics and mechanics
    [4xBUTTON_QE.PT-03_102_003_1mm.3mf, BOTTOM-QE.PT-02_101.3mf, Button_QE.PT-03_102+1mm.stl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]
2023-09-12 Renaming software subfolder and file names for a better integration of the git repo in the arduino software development environment.
    [config.cfg]
2023-09-14 added READMEs for Mechanic and Electronic added License in the Electronic schematics restructured Mechanics for better readability and reproducibility
    [4xBUTTON_QE.PT-03_102_003_1mm.3mf, BOTTOM-QE.PT-02_101.3mf, Support-Test-button.104.stl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]
2023-09-15 slow start without uSD fixed tested with 4-32GB uSD-cards FAT32
    [SmartView.cpp, SmartView.h, XD_qEdgeUI.h]
2023-09-23 Create Bambu Studio Print File
    Print File for Bambulab Printers/Bambu Studio added.
    [qEdge.104_BambuStudio-Slicer_P1-X1_3 plate project file.3mf]
2023-09-23 BambuLab A1 Print File
    Added a printfile for BambuLab A1 for BambuStudio 1.7.6.92
    [qEdge.104_BambuStudio-Slicer_A1_4 plates project.3mf]
2023-09-23 Added describing images
    Example images for print data added.
    Overview images for BambuStudio print data added
    +small fix to print data "p1-x1"
    [qEdge.104_BambuStudio-Slicer_P1-X1_3 plate project file.3mf]
2023-09-23 update mech read.me
    Extension of the description with further print data
2023-12-07 added Varmecos donation of material

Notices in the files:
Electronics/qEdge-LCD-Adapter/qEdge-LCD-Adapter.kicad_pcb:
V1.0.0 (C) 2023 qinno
